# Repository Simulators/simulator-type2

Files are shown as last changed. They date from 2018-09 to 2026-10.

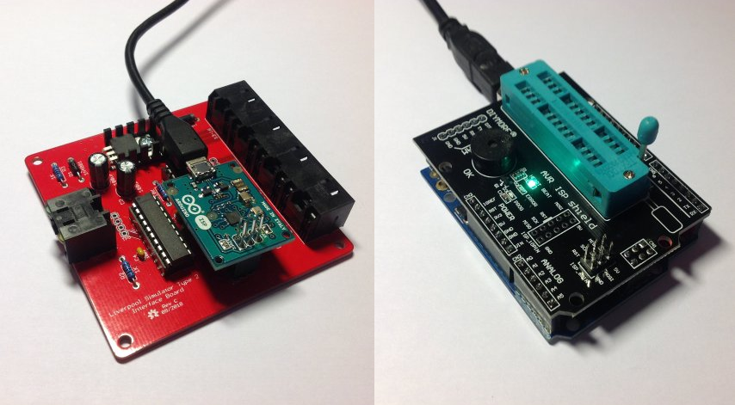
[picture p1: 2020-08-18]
docs/source/Images/Hardware/Interface/programmers.png

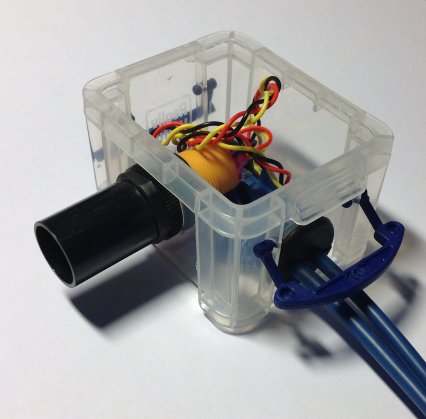
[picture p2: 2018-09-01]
docs/source/Images/Hardware/Enclosures/Img_0459.jpg

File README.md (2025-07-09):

# The Type 2 Liverpool Ringing Simulator

In this repository you will find all the resources for building the Liverpool Ringing Simulator Project's Type 2 simulator interfaces and sensor heads, including:
* Hardware & Software Manuals
* Firmware Source Code
* KiCad PCB Designs
* PCB Fabrication Gerber Files

You probably want to start in the docs folder above...

Please note that this is a Build-it-Yourself project. No pre-built hardware is available.

The original (Type 1) Liverpool Simulator hardware and code can be found in the legacy repository at https://github.com/Simulators/simulator. The Type 1 simulator is no longer under active development.

If you didn't get here from https://www.simulators.org.uk/, you might want to go and look at that, too.

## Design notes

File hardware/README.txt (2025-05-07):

*** If you just want to order PCBs from a fabrication house, ready-made Gerber files can be found in the Gerbers directory ***

If you require PCB CAD files, please use those in the "kicad" subdirectory. The CAD files in the "eagle" subdirectory are the last to be produced using Eagle prior to migration of PCB development to KiCad. Those are provided for reference only, and are no longer maintained.

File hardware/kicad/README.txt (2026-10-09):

HOW TO USE THE KICAD CAD FILES
==============================

*** If you just want to order PCBs from a fabrication house, you don't need THESE files ***
Ready-made Gerber files can be found in the Gerbers directory.

A working knowledge of KiCad is assumed.

The version of KiCad currently used for Liverpool Ringing Simulator Project PCB development is 10.0.x. Some KiCad projects were developed with KiCad 9.0.x, and may require updates if opened in KiCad 10.0.x. 

Libraries
=========

As far as possible, the PCB designs use symbols and footprints from the stock libraries supplied with KiCad. Where no suitable symbol or footprint exists in the stock libraries, additional symbols and footprints are provided by custom libraries in this repository.

Unpack the libraries zipfile into a convenient location, wherever you keep your custom KiCad libraries, and start KiCad 10.x. Note that some libraries now require KiCad 10.0x.

From the project browser window, use the "Preferences | Manage Symbol Libraries..." menu option to register the symbol library file "LRSP_Simulator.kicad_sym" as a Global symbol library with the nickname "LRSP_Simulator".

From the project browser window, use the "Preferences | Manage Footprint Libraries..." menu option to register the footprint library directory "LRSP_Simulator.pretty" as a Global footprint library with the nickname "LRSP_Simulator".

The footprint library uses the KiCad 9.x (and later) embedded file functionality to embed 3D models into the library. There is no need for a separate 3D models collection.

PCB Projects
============

Each PCB zipfile is a compressed KiCad project, created with the "File | Archive Project..." menu option from the KiCad project browser.

Download the zipfile for the PCB(s) you want to work on, and create an empty directory to hold each PCB project.

Use the "File | Unarchive Project..." menu option from the KiCad project browser window to unpack each zipfile into the appropriate directory, then use "File | Open Project..." to load the PCB project.

Gerber & Drill File Creation
============================

The Liverpool Ringing Simulator Project creates Gerbers and drill files using the "Fabrication Toolkit" plugin, which creates a compressed zipfile containing files formatted ready for fabrication by JLCPCB. These Gerbers should be suitable for use by other PCB fabrication houses.

Install this plugin into KiCad using the Plugin and Content Manager (PCM) from the KiCad project browser window, and run it from the icon is places in the PCB Editor toolbar. The output zipfile is placed in the sub-directory "production".

Panelisation
============

The Liverpool Ringing Simulator Project panelises small PCBs using the "KiKit" plugin. Ready-made panelised Gerber files are provided in the Gerbers directory.

KiKit has a two phase installation process. Install the plugin frontend into KiCad using the Plugin and Content Manager (PCM) from the KiCad main window, and the Python backend from the KiCad Comand Prompt window - refer to the KiKit documentation for details.

KiKit panelisation parameter files are provided in the PCB project zipfiles. The small sensor boards use the "KiKit_Panel_6.json" parameter file to create a 2 x 3 panel of 6 boards. The Power and 2nd PC boards use the "KiKit_Panel_4.json" parameter file to create a 2 x 2 panel of 4 boards.

Note that KiKit panelisation is intended to be run from the Standalone PCB Editor, not from within a project.

LRSP
20261009

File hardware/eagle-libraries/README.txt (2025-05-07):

*** DEPRECATED ***

These library files are the last to be produced using Eagle prior to migration of PCB development to KiCad. These are provided for reference only, and are no longer maintained.

Please use the KiCad CAD files where possible.

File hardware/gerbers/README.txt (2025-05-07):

Please use the KiCad-generated Gerbers in the "kicad" directory where possible.

The Gerbers in the "eagle" subdirectory are the last to be produced using Eagle prior to migration of PCB development to KiCad. Those are provided for reference only, and are no longer maintained.

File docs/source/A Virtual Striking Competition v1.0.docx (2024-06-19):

The Liverpool Ringing Simulator

A Virtual Striking Competition

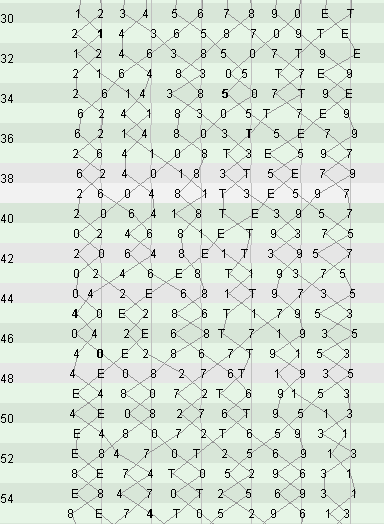
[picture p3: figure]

Author: Andrew Instone-Cowie

Date: 19 June 2024

Version: 1.0

# Index of Figures

# Document History

Version | Author | Date | Changes
0.1 | A J Instone-Cowie | 04/01/2020 | First Draft.
1.0 | A J Instone-Cowie | 19/06/2024 | Update external links.

Copyright ©2020-24 Andrew Instone-Cowie.

Cover image: CAS Visual Representation of Striking.

# Licence

This work is licensed under a Creative Commons Attribution-ShareAlike 4.0 International License.[^1]

Unless otherwise separately undertaken by the Licensor, to the extent possible, the Licensor offers the Licensed Material as-is and as-available, and makes no representations or warranties of any kind concerning the Licensed Material, whether express, implied, statutory, or other. This includes, without limitation, warranties of title, merchantability, fitness for a particular purpose, non-infringement, absence of latent or other defects, accuracy, or the presence or absence of errors, whether or not known or discoverable. Where disclaimers of warranties are not allowed in full or in part, this disclaimer may not apply to You.

To the extent possible, in no event will the Licensor be liable to You on any legal theory (including, without limitation, negligence) or otherwise for any direct, special, indirect, incidental, consequential, punitive, exemplary, or other losses, costs, expenses, or damages arising out of this Public License or use of the Licensed Material, even if the Licensor has been advised of the possibility of such losses, costs, expenses, or damages. Where a limitation of liability is not allowed in full or in part, this limitation may not apply to You.

# Background

## Polling Design

Both the Type 1 and Type 2 variants of the Liverpool Ringing Simulator use a polling approach to detecting sensor inputs. This is discussed in detail in the Type 2 Technical Reference Guide, but in summary, after completing initialization, the firmware code cycles round all the active inputs, examining the state of each sensor in turn. After all inputs have been read, the code loops round and the process starts again.

In the Type 2 Simulator Interface Module each iteration of the main polling loop takes approximately 400µs when configured to poll all 16 possible sensors. Put another way, the inputs are polled at approximately 2.5kHz.

## The Variable Odd-Struckness Problem

This use of a polling architecture invariably introduces a degree of variable odd-struckness.

- If a pulse from any Sensor Module starts a fraction of a second before the polling loop examines the associated input, the pulse will be detected almost immediately.
- If the pulse starts a fraction of a second after the polling loop examines the associated input, the pulse will not be detected until the next iteration of the polling loop, potentially as much as 400µs later.
- There is no fixed correlation between the start time of a pulse and the current position of the polling loop in its cycle, and therefore each pulse is subject to an effectively random delay of between zero and 400µs (the duration of the polling loop).
- The mean delay would be 200µs (half the polling interval), so if this was detectable then it would result in each simulated bell apparently striking randomly early or late by between zero and 200µs.

The following diagram taken from Type 2 Technical Reference Guide illustrates this problem:

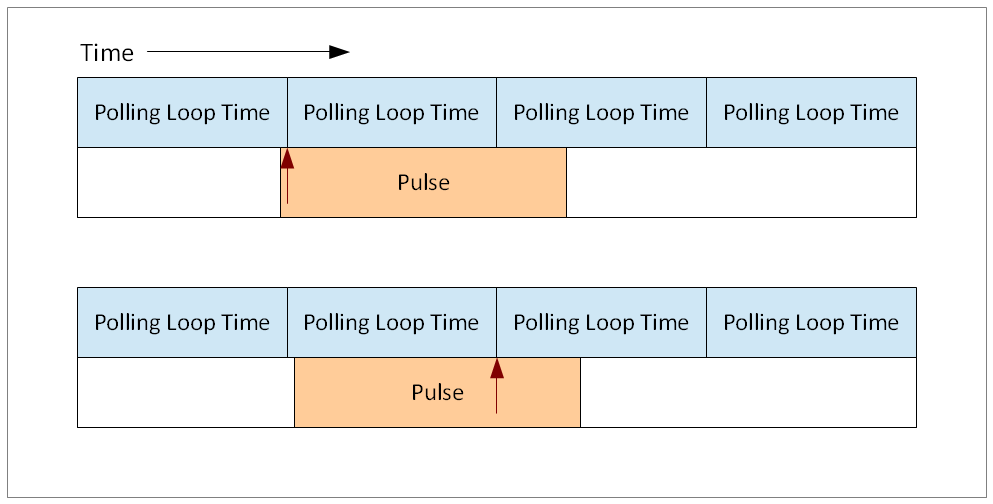
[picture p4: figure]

Figure 1 – Variable Odd-Struckness Illustration

The upper red arrow indicates the polling loop examining an input just after the start of an incoming sensor pulse. The delay due to polling is effectively zero.

In the lower diagram, the polling loop examines the input pin just before the start of an incoming sensor pulse, and hence does not detect the pulse until the next iteration of the loop, indicated by the lower red arrow. The delay due to polling is effectively equal to the polling loop interval.

The design of the simulator assumes that this variable odd-struckness is too small to be significant and is in practice not detectable.

The first question this paper seeks to consider is: Is this assumption reasonable?

## Virtual Striking Competition

The usual ringing approach to quantifying errors in striking is to conduct a striking competition!

A “virtual striking competition” was conducted to validate the reasonableness of this assumption. This exercise pre-dated the development of the Type 2 Simulator, so was undertaken with a Type 1 Simulator Interface driving Abel[^2] running on a PC, however both hardware variants use the same underlying approach.

The competition was conducted as follows:

- The “test piece” consisted of 10 minutes of rounds on 12, with an inter-bell interval of approximately 200ms and an open handstroke lead of 1.0. This results in approximately 240 rows at a peal speed of 3h 30m.
- The Abel striking statistics were reset prior to each test, the striking for each test piece was recorded, and then exported from Abel in “Lowndes” text format[^3].
- Each Lowndes file was then imported into the CAS[^4] tool for analysis. CAS (Computer Analysis of Striking) is used in conjunction with the Hawkear[^5] system as part of the judging process for the National 12-Bell Striking Competition[^6].
- The individual results for each test piece were recorded, and all test pieces were then ranked using the CAS Band Summary tool.
- Three different scenarios were tested, and these are detailed below.
- Note that data relating to two further scenarios has been removed for clarity; this related to other experimental hardware and is not relevant to this discussion.

# Virtual Competition Scenarios

## Test Scenario A

Test Scenario A was a control scenario, using Abel alone with no simulator hardware.

- Abel was setup to ring rounds on 12 at the required speed, the statistics cleared, and the ringing started.
- No external simulator hardware was used in this test.
- In this test, as in all tests, the Simulator PC was left as undisturbed as possible during ringing.

Scenario A is illustrated in the following diagram:

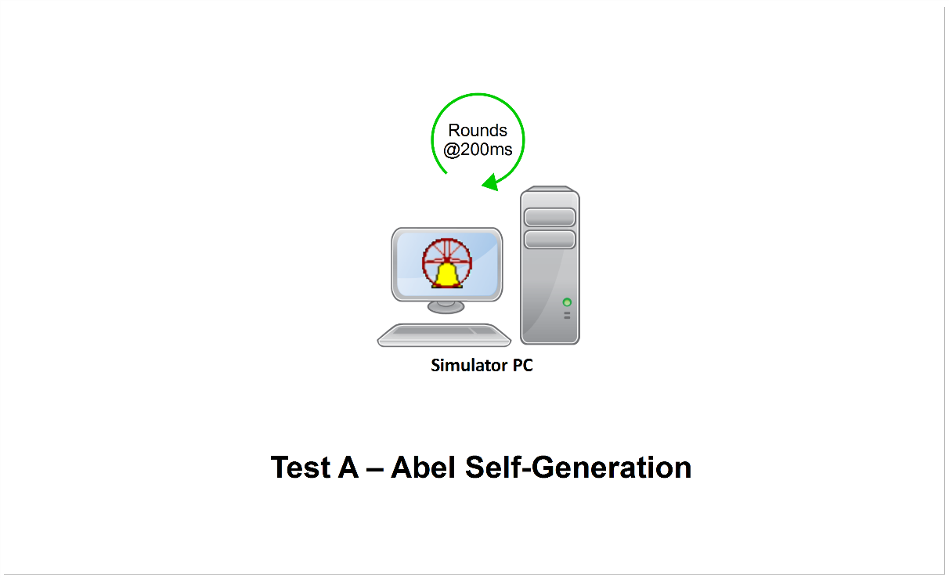
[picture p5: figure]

Figure 2 – Test Scenario A

The CAS analysis of the striking from Test Scenario A is shown in the following table. The single fault is most likely the result of some background processing on the PC.

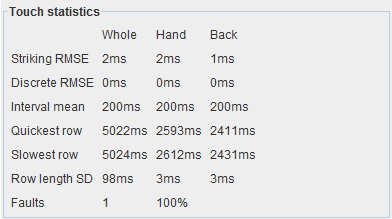
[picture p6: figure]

Figure 3 – Scenario A Test Results

## Test Scenario B

Test Scenario B was also a control and tested the accuracy of serial input detection in Abel.

- Abel was driven by a Simulator Interface operating with custom test code.
- The Interface was setup to ring rounds on 12 at the required speed, all non-essential code being eliminated. The Abel statistics were cleared, and the ringing started.
- No simulator sensor inputs were read in this test, and hence this test should not be susceptible to the variable odd-struckness problem.

Scenario B is illustrated in the following diagram:

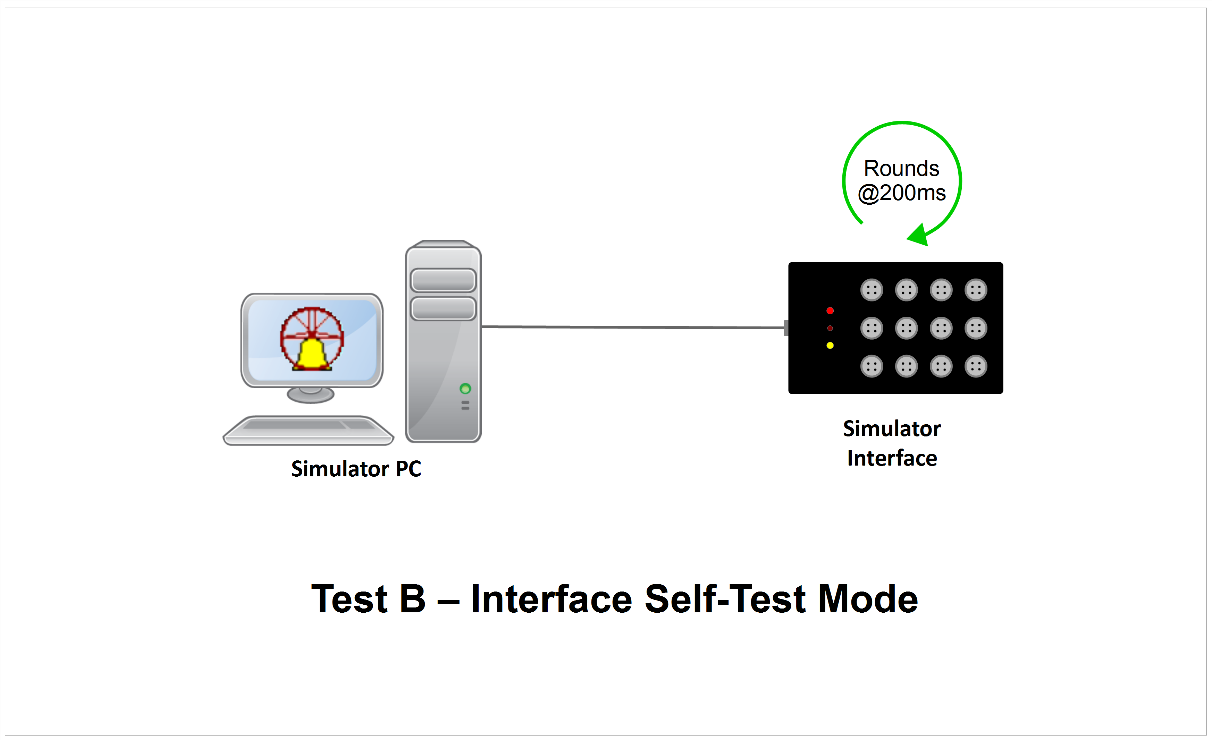
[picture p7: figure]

Figure 4 – Test Scenario B

The CAS analysis of the striking from Test Scenario B is shown in the following table.

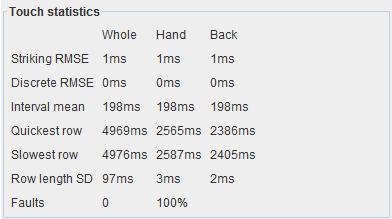
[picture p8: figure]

Figure 5 – Scenario B Test Results

## Test Scenario C

Test Scenario C introduced susceptibility to the variable odd-struckness problem.

- Abel was driven by a Simulator Interface operating with standard code. The Interface sensor inputs were driven by an Arduino setup as a pulse generator, to ring rounds on 12 at the required speed. The Abel statistics were cleared, and the pulse generator started.
- 12 simulator sensor inputs were polled in this test, and hence the test should be susceptible to the variable odd-struckness problem.
- This was the most live-like of the main test scenarios, including all interface code and polling variability.

Scenario C is illustrated in the following diagram:

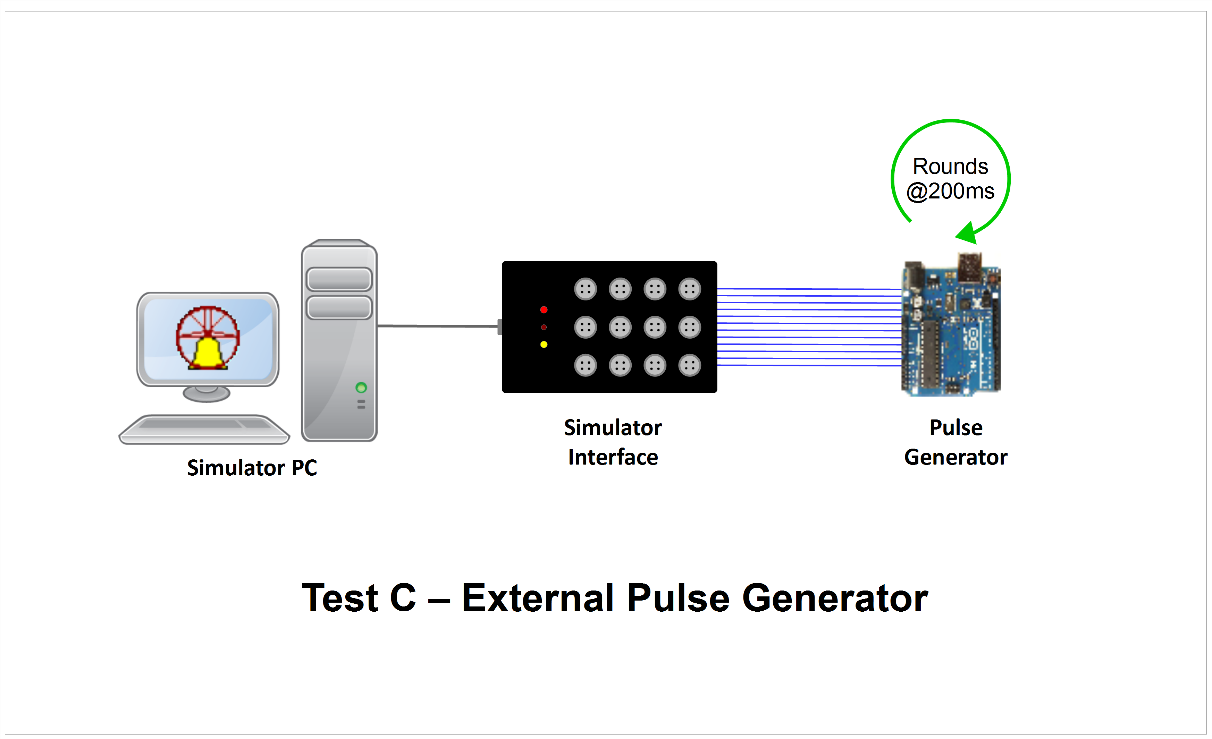
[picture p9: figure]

Figure 6 – Test Scenario C

The CAS analysis of the striking from Test Scenario C is shown in the following table. The virtual ringing is still very good, and no faults are recorded.

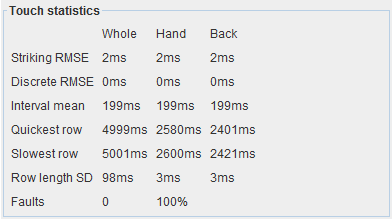
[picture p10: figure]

Figure 7 – Scenario C Test Results

## Interim Results

The CAS Band Summary results for all three scenarios are shown in the following table:

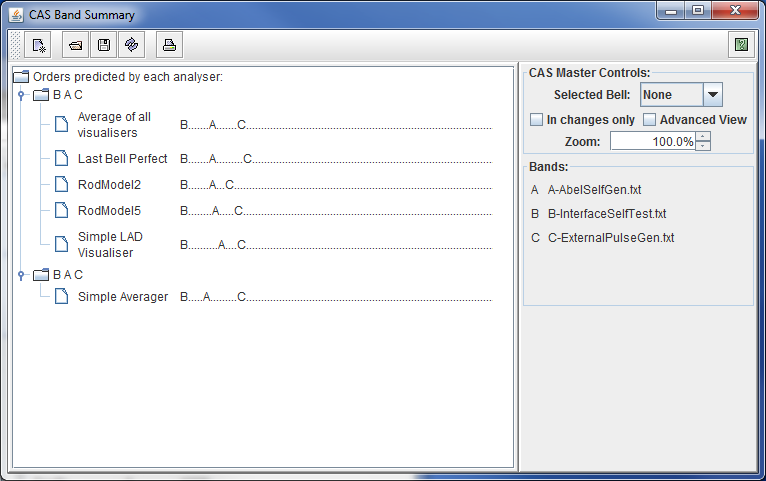
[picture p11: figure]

Figure 8 – Interim CAS Results

The detailed results above for each test scenario show that the striking achieved by the simulator is very good.

- Slightly surprisingly, the most accurate striking was achieved using the serial input (Scenario B) and not from Abel self-generating ringing (Scenario A). However, the difference between the two scenarios is extremely small.
- As expected, a very slight reduction in striking accuracy is introduced by polling Simulator Interface inputs (Scenario C versus Scenario B). The difference is again extremely small, and the striking still achieves a “perfect” 100% accuracy with no faults.
- Scenarios D and E have been removed, as noted above.

The assumption that any variable odd-struckness introduced by polling inputs is too small to be significant does therefore seem to be reasonable.

A more interesting question might be: How does the simulator striking compare to the best that humans can achieve?

# Real World Striking Comparison

To consider the second question, the results of the virtual striking competition were compared with the actual striking data from the bands placed first, fifth and ninth (i.e. last) in the 2010 National 12-Bell Striking Competition held at Crediton. This striking data is used for testing by the CAS developer[^7].

This comparison does not pretend to be a detail statistical analysis and should be treated with a degree of caution, but it does provide a rough indication of the relative magnitudes of the errors introduced by the simulator, and of the errors naturally incurred by highly experienced real ringers ringing under competition conditions.

The speed of competition ringing and the overall number of changes rung are broadly comparable with the simulator test scenarios above[^8].

## Scenario F – Crediton 2010 First Placed Band

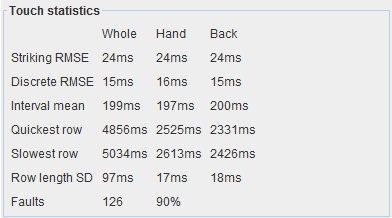
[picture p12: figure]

Figure 9 – Crediton 1st Placed Band

## Scenario G – Crediton 2010 Fifth Placed Band

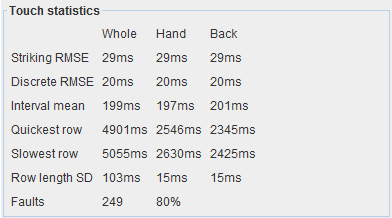
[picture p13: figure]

Figure 10 – Crediton 5th Placed Band

## Scenario H – Crediton 2010 Ninth Placed Band

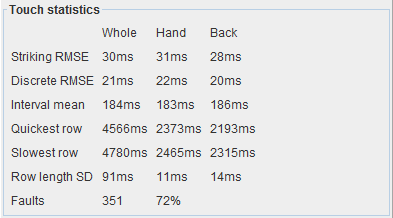
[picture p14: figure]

Figure 11 – Crediton 9th Placed Band

## Overall Result

The CAS summary results for all virtual and competition scenarios are shown in the following table:

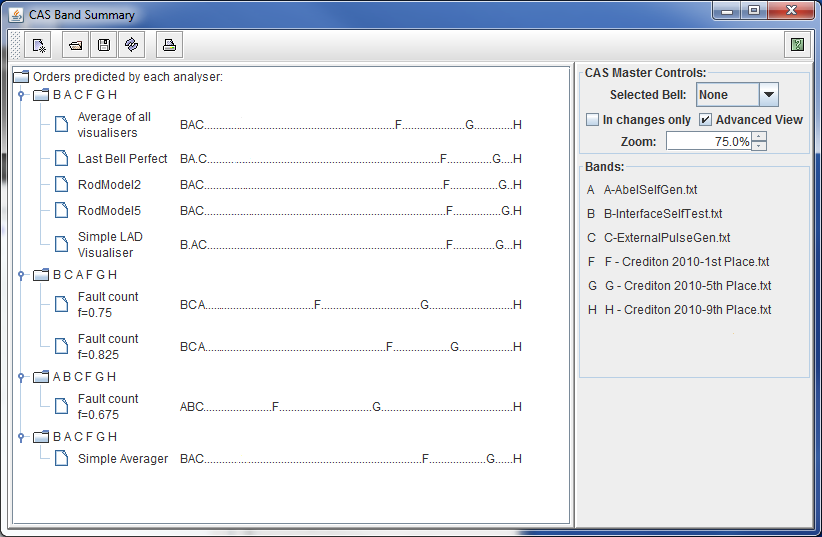
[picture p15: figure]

Figure 12 – Overall CAS Results

As might be expected, all the simulator results are bunched up at the left side of the analysis, showing that the errors introduced by the simulator are very much smaller than the errors naturally incurred by the human ringers.

Overall, the assumption that variable odd-struckness introduced by polling simulator inputs is too small to be significant does appear to be justified.

# Acknowledgements

CAS is developed and released under the GPL by Mark B Davies.

Abel is developed by Chris Hughes and Simon Feather, and is copyright © 2019 AbelSim Ltd.

[^1] https://creativecommons.org/licenses/by-sa/4.0/
[^2] https://www.abelsim.co.uk
[^3] https://www.abelsim.co.uk/doc/striking.htm
[^4] https://www.12bell.org.uk/downloads/cas1.4.zip, released under GNU General Public Licence v3.
[^5] https://www.12bell.org.uk/hawkear/
[^6] https://www.12bell.org.uk
[^7] https://github.com/EmBeeDee/CAS
[^8] https://www.12bell.org.uk/cgi-bin/results.cgi?year=2010&venue=crediton. Note that the judges’ final scores are not derived solely from CAS.

Liverpool Ringing Simulator – A Virtual Striking Competition 1.0

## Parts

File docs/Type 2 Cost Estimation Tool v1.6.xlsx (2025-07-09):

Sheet: Simulator Cost Estimation
Liverpool Simulator (Type 2) Cost Estimation Tool
v1.6, 07/08/2024 | For Interface Rev F, Power Board Rev E, Magnetic Sensor Rev E, Generic Sensor Rev D
This spreadsheet gives an ESTIMATE of the components costs for the Type 2 Liverpool Simulator Hardware.
Please read the notes at the bottom of the sheet, then set the numbers of interfaces and sensors in the red boxes.
Number of Interface/Power Boards | 1 | Adjust the quantities in the red bordered cells to suit the requirements of your installation.
Number of Magneto-Resistive (2SS52M) Sensors | 8
Number of Hall Effect (A1120EUA-T) Sensors | 0
Number of Infra-Red/Generic Sensors | 0
Item | Supplier | Part Code | Quantities Required |  |  |  |  | Pricing |  |  |  | # Multiples | Cost inc VAT
 |  |  | Base | MR Sensor | HE Sensor | IR Sensor | # Total | Price | Per | Multiple | VAT
100Ω 0.25W Metal Film Resistor | Farnell | 9341099 | 0 | 1 | 1 | 1 | 8 | £0.057 | 1 | 10 | 1.20 | 1 | £0.69
1kΩ 0.25W Metal Film Resistor | Farnell | 9341102 | 2 | 1 | 1 | 1 | 10 | £0.059 | 1 | 10 | 1.20 | 1 | £0.70
10kΩ 0.25W Metal Film Resistor | Farnell | 9341110 | 1 | 1 | 1 | 1 | 9 | £0.058 | 1 | 10 | 1.20 | 1 | £0.69
100µF 25V Electrolytic Capacitor (6.3mm Radial) | Farnell | 9451188 | 2 | 0 | 0 | 0 | 2 | £0.110 | 1 | 1 | 1.20 | 2 | £0.26
100nF (0.1µF) 50V MLCC Capacitor (2.54mm Radial) | Farnell | 1457655 | 4 | 1 | 1 | 1 | 12 | £0.095 | 1 | 10 | 1.20 | 2 | £2.27
1N4001 Diode | Farnell | 1458986 | 1 | 0 | 0 | 0 | 1 | £0.254 | 1 | 5 | 1.20 | 1 | £1.52
SA5.0A TVS Diode | Farnell | 1886342 | 1 | 2 | 2 | 2 | 17 | £0.346 | 1 | 5 | 1.20 | 4 | £8.30
SA12A TVS Diode | Farnell | 2679618 | 1 | 0 | 0 | 0 | 1 | £0.249 | 1 | 5 | 1.20 | 1 | £1.49
SA15CA TVS Diode | Farnell | 2762809 | 3 | 0 | 0 | 0 | 3 | £0.346 | 1 | 1 | 1.20 | 3 | £1.25
MC7805CTG 5V Voltage Regulator | Farnell | 9666095 | 1 | 0 | 0 | 0 | 1 | £0.612 | 1 | 1 | 1.20 | 1 | £0.73 | Part Change 26/06/2024
MAX233EPP+G36 Serial Line Driver | Farnell | 2519158 | 1 | 0 | 0 | 0 | 1 | £10.140 | 1 | 1 | 1.20 | 1 | £12.17
Blue 3mm LED | Farnell | 1863182 | 0 | 1 | 1 | 0 | 8 | £0.737 | 1 | 1 | 1.20 | 8 | £7.08
Yellow 3mm LED | Farnell | 2112098 | 0 | 0 | 0 | 1 | 0 | £0.222 | 1 | 5 | 1.20 | 0 | £0.00
Honeywell 2SS52M Magneto-Resistive Sensor | RS | 368-3945 | 0 | 1 | 0 | 0 | 8 | £7.400 | 1 | 1 | 1.20 | 8 | £71.04 | No longer stocked by Farnell, was part 3111519
Allegro Microsystems A1120 Hall Effect Sensor | Farnell | 1791402 | 0 | 0 | 1 | 0 | 0 | £0.830 | 1 | 1 | 1.20 | 0 | £0.00
ATmega328P-PU Microcontroller | Farnell | 1715487 | 1 | 0 | 0 | 0 | 1 | £2.320 | 1 | 1 | 1.20 | 1 | £2.78
Amphenol RJHSE-5084 RJ45 Connector | Farnell | 1860578 | 1 | 0 | 0 | 0 | 1 | £1.230 | 1 | 1 | 1.20 | 1 | £1.48
Amphenol RJHSE-5080-04 RJ45 Connector | Farnell | 2709010 | 1 | 0 | 0 | 0 | 1 | £2.030 | 1 | 1 | 1.20 | 1 | £2.44
Amphenol RJHSE-5080 RJ45 Connector | Farnell | 1860577 | 1 | 0 | 0 | 0 | 1 | £0.926 | 1 | 1 | 1.20 | 1 | £1.11
Amp TE Connectivity 5406526-1 RJ45 Connector | Farnell | 2452587 | 0 | 1 | 1 | 1 | 8 | £2.540 | 1 | 1 | 1.20 | 8 | £24.38
Right Angle PCB D Sub Connector 9 Pin | Farnell | 1848372 | 1 | 0 | 0 | 0 | 1 | £0.673 | 1 | 5 | 1.20 | 1 | £4.04
DC Power Connector 5mm PCB Mount | Farnell | 1854512 | 1 | 0 | 0 | 0 | 1 | £2.450 | 1 | 1 | 1.20 | 1 | £2.94
Header Pins 40-way Strip | Farnell | 1462888 | 0 | 0 | 0 | 3 | 0 | £1.500 | 40 | 40 | 1.20 | 0 | £0.00
ICSP Header 2x3 Pin | Farnell | 1593440 | 1 | 0 | 0 | 0 | 1 | £0.053 | 1 | 1 | 1.20 | 1 | £0.06 | Part Change 26/06/2024
20-pin, 0.3” pitch IC Socket | Farnell | 4285608 | 1 | 0 | 0 | 0 | 1 | £0.163 | 1 | 10 | 1.20 | 1 | £1.96 | Part Change 26/06/2024
28-pin, 0.3” pitch IC Socket | Farnell | 2445626 | 1 | 0 | 0 | 0 | 1 | £0.444 | 1 | 10 | 1.20 | 1 | £5.33
Murata CSTLS8M00G53-A0 Ceramic Resonator | Farnell | 2443273 | 1 | 0 | 0 | 0 | 1 | £0.135 | 1 | 5 | 1.20 | 1 | £0.81
TO-220 Heatsink (Optional) | Farnell | 1703172 | 1 | 0 | 0 | 0 | 1 | £2.770 | 1 | 1 | 1.20 | 1 | £3.32
20mm PCB Mount Fuse Holder | Farnell | 2461158 | 1 | 0 | 0 | 0 | 1 | £0.480 | 1 | 5 | 1.20 | 1 | £2.88
20mm 800mA Quick Blow Fuse | Farnell | 2461215 | 1 | 0 | 0 | 0 | 1 | £0.160 | 1 | 1 | 1.20 | 1 | £0.19
SW4177-1500 AC/DC Power Supply | Farnell | 2802689 | 1 | 0 | 0 | 0 | 1 | £23.580 | 1 | 1 | 1.20 | 1 | £28.30
Really Useful Box 0.75 Litre | Really Useful | NA | 2 | 0 | 0 | 0 | 2 | £2.540 | 1 | 1 | 1.00 | 2 | £5.08
Really Useful Box 0.14 Litre | Really Useful | NA | 0 | 0 | 0 | 1 | 0 | £0.690 | 1 | 1 | 1.00 | 0 | £0.00
Really Useful Box 0.07 Litre | Really Useful | NA | 0 | 1 | 1 | 0 | 8 | £0.670 | 1 | 1 | 1.00 | 8 | £5.36
20mm Closed Grommets | Screwfix | 884VT | 6 | 1 | 1 | 1 | 14 | £3.290 | 100 | 100 | 1.00 | 1 | £3.29 | Part Change 26/06/2024
N52 grade, 20mm x 10mm Neodymium | MagnetExpert | F646-N52-1 | 0 | 1 | 1 | 0 | 8 | £5.680 | 1 | 1 | 1.20 | 8 | £54.53 | Supplier Change
Infra-Red Obstacle Sensor | HobbyComponents | E18-D80NK | 0 | 0 | 0 | 1 | 0 | £4.990 | 1 | 1 | 1.00 | 0 | £0.00 | Supplier Change
RJ45 Power/Data Cable (25m assumed) | CPC | CS24970 | 1 | 0 | 0 | 0 | 1 | £10.120 | 1 | 1 | 1.20 | 1 | £12.14
RJ45 Sensor Cable (5m assumed) | CPC | CS17415 | 0 | 1 | 1 | 1 | 8 | £2.280 | 1 | 1 | 1.20 | 8 | £21.89
USB-Serial Adapter Cable | eBay | NA | 1 | 0 | 0 | 0 | 1 | £13.850 | 1 | 1 | 1.00 | 1 | £13.85
Interface Board PCB | JLCPCB | NA | - | - | - | - | 1 | £1.580 | 5 | 5 | 1.00 | 1 | £1.58
Power Board PCB | JLCPCB | NA | - | - | - | - | 8 | £6.160 | 20 | 20 | 1.00 | 1 | £6.16 | Panelisation fee applies
Magnetic Sensor PCB - for 2SS52M or A1120EUA-T | JLCPCB | NA | - | - | - | - | 8 | £6.080 | 30 | 30 | 1.00 | 1 | £6.08 | Panelisation fee applies
Generic/Optical Sensor PCB | JLCPCB | NA | - | - | - | - | 0 | £6.080 | 30 | 30 | 1.00 | 0 | £0.00 | Panelisation fee applies
Estimated Total Cost |  |  |  |  |  |  |  |  |  |  |  |  | £320.17
Notes
JLCPCB PCB Costs exclude carriage, estimated at £12 per order.
Farnell carriage is free for orders >£40 ex VAT, £9.99 for smaller orders. Many eBay items have free postage.
Other carriage costs not included.
Farnell, CPC, Really Useful and Screwfix prices correct at 26/06/2024.
eBay costs for typical items with active listings on 26/06/2024.
In addition to these components, you will need a PC, simulator software of your choice, and mounting hardware for the sensors.
The VAT column indicates where VAT needed to be added to a price quoted exclusive of VAT.
The Honeywell 2SS52M is no longer stocked by Farnell, part code and price are from RS.

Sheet: Multi-PC Cost Estimation
Multi-PC Hardware (Type 2) Cost Estimation Tool
v1.6, 26/06/2024 | For Second PC Board Rev C, Basic Serial Splitter/Expander Rev D
This spreadsheet gives an ESTIMATE of the components costs for the Type 2 Liverpool Simulator Multi-PC Hardware.
Please read the notes at the bottom of the sheet, then set the numbers of modules in the red boxes.
Number of Second PC Boards | 0 | Adjust the quantities in the red bordered cells to suit the requirements of your installation.
Number of Basic Serial Splitter Master Boards | 1
Number of Basic Serial Splitter Expander Boards | 0
Item | Supplier | Part Code | Quantities Required |  |  |  | Pricing |  |  |  | # Multiples | Cost inc VAT
 |  |  | Second PC | Master | Expander | # Total | Price | Per | Multiple | VAT
1kΩ 0.25W Metal Film Resistor | Farnell | 9341102 | 0 | 1 | 0 | 1 | £0.059 | 1 | 10 | 1.20 | 1 | £0.70
100µF 25V Electrolytic Capacitor (6.3mm Radial) | Farnell | 9451188 | 0 | 2 | 0 | 2 | £0.110 | 1 | 1 | 1.20 | 2 | £0.26
330nF (0.33µF) 50V MLCC Capacitor (6.3mm Radial) | Farnell | 2819679 | 0 | 3 | 0 | 3 | £1.500 | 1 | 1 | 1.20 | 3 | £5.40
47nF (0.047µF) 50V MLCC Capacitor (2.54mm Radial) | Farnell | 2819680 | 0 | 1 | 0 | 1 | £0.308 | 1 | 1 | 1.20 | 1 | £0.37
100nF (0.1µF) 50V MLCC Capacitor (2.54mm Radial) | Farnell | 1457655 | 0 | 6 | 5 | 6 | £0.095 | 1 | 10 | 1.20 | 1 | £1.13
1N4001 Diode | Farnell | 1458986 | 0 | 1 | 0 | 1 | £0.254 | 1 | 5 | 1.20 | 1 | £1.52
SA5.0A TVS Diode | Farnell | 1886342 | 0 | 1 | 0 | 1 | £0.346 | 1 | 5 | 1.20 | 1 | £2.08
SA12A TVS Diode | Farnell | 2679618 | 1 | 1 | 0 | 1 | £0.249 | 1 | 5 | 1.20 | 1 | £1.49
SA15CA TVS Diode | Farnell | 2762809 | 3 | 3 | 0 | 3 | £0.346 | 1 | 1 | 1.20 | 3 | £1.25
MC7805CTG 5V Voltage Regulator | Farnell | 9666095 | 0 | 1 | 0 | 1 | £0.612 | 1 | 1 | 1.20 | 1 | £0.73
MAX3323EEPE+ Serial Line Driver | Farnell | 2511866 | 0 | 1 | 0 | 1 | £10.890 | 1 | 1 | 1.20 | 1 | £13.07
MAX208CNG+ Serial Line Driver | Farnell | 2511906 | 0 | 1 | 1 | 1 | £8.840 | 1 | 1 | 1.20 | 1 | £10.61
Green 3mm LED | Farnell | 1581114 | 0 | 1 | 0 | 1 | £0.078 | 1 | 5 | 1.20 | 1 | £0.47
DIP Switch 8-Way SPST | Farnell | 9472185 | 0 | 1 | 0 | 1 | £1.110 | 1 | 1 | 1.20 | 1 | £1.33
Amp TE Connectivity 5406526-1 RJ45 Connector | Farnell | 2452587 | 1 | 1 | 0 | 1 | £2.540 | 1 | 1 | 1.20 | 1 | £3.05
Right Angle PCB D Sub Connector 9 Pin | Farnell | 1848372 | 1 | 4 | 4 | 4 | £0.673 | 1 | 5 | 1.20 | 1 | £4.04
16-pin, 0.3” pitch IC Socket | Farnell | 2445622 | 0 | 1 | 0 | 1 | £0.235 | 1 | 10 | 1.20 | 1 | £2.82 | Part Change
24-pin, 0.3” pitch IC Socket | Farnell | 2672303 | 0 | 1 | 1 | 1 | £0.750 | 1 | 1 | 1.20 | 1 | £0.90 | Part Change
8-Way Right Angle Header | Farnell | 2356196 | 0 | 0 | 1 | 0 | £0.587 | 1 | 10 | 1.20 | 0 | £0.00
8-Way Right Angle Socket | Farnell | 1668343 | 0 | 0 | 1 | 0 | £2.330 | 1 | 1 | 1.20 | 0 | £0.00
Really Useful Box 0.75 Litre | Really Useful | NA | 1 | 0 | 0 | 0 | £2.540 | 1 | 1 | 1.00 | 0 | £0.00
Really Useful Box 0.55 Litre | Really Useful | NA | 0 | 1 | 0 | 1 | £2.610 | 1 | 1 | 1.00 | 1 | £2.61
20mm Closed Grommets | Screwfix | 884VT | 1 | 1 | 0 | 1 | £3.290 | 100 | 100 | 1.00 | 1 | £3.29
Basic Serial Splitter Board PCB | JLCPCB | NA | - | - | - | 1 | £1.580 | 5 | 5 | 1.00 | 1 | £1.58
Second PC Board PCB | JLCPCB | NA | - | - | - | 0 | £6.160 | 20 | 20 | 1.00 | 0 | £0.00 | Panel fee applies
Estimated Total Cost |  |  |  |  |  |  |  |  |  |  |  | £58.71
Notes
The VAT column indicates where VAT needed to be added to a price quoted exclusive of VAT.
JLCPCB PCB Costs exclude carriage, estimated at £12 per order.
Farnell carriage is free for orders >£40 ex VAT, £9.99 for smaller orders. Many eBay items have free postage.
Other carriage costs not included.
Farnell, CPC, Really Useful and Screwfix prices correct at 26/06/2024.
The VAT column indicates where VAT needed to be added to a price quoted exclusive of VAT.

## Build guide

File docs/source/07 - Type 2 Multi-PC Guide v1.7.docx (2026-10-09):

Type 2 Liverpool Ringing Simulator

07 – Multi-PC Guide

Author: Andrew Instone-Cowie

Date: 09 October 2026

Version: 1.7

# Index of Figures

# Index of Tables

# Document History

Version | Author | Date | Changes
1.0 | A J Instone-Cowie | 01/10/2019 | First Release.
1.1 | A J Instone-Cowie | 18/08/2020 | Minor update.
1.2 | A J Instone-Cowie | 27/08/2021 | Alternative DB9 enclosure drilling option, DB9 part.
1.3 | A J Instone-Cowie | 19/06/2024 | Update external links.
1.4 | A J Instone-Cowie | 26/06/2024 | Updated Farnell/Screwfix part numbers.
1.5 | A J Instone-Cowie | 28/08/2024 | Improve diagrams following feedback, add module configurations table.
1.6 | A J Instone-Cowie | 07/05/2025 | Eagle to KiCad PCB design tool migration. Updated schematics and board layouts.
1.7 | A J Instone-Cowie | 09/10/2026 | Updated Basic Serial Splitter schematics.

Copyright ©2019-26 Andrew Instone-Cowie.

Cover photograph: A completed Type 2 Basic Serial Splitter PCB.

PC ports vector graphic design by https://www.vecteezy.com
(Vecteezy Standard Licence, Free for personal and commercial use with attribution.)

# Licence

This work is licensed under a Creative Commons Attribution-ShareAlike 4.0 International License.[^1]

Unless otherwise separately undertaken by the Licensor, to the extent possible, the Licensor offers the Licensed Material as-is and as-available, and makes no representations or warranties of any kind concerning the Licensed Material, whether express, implied, statutory, or other. This includes, without limitation, warranties of title, merchantability, fitness for a particular purpose, non-infringement, absence of latent or other defects, accuracy, or the presence or absence of errors, whether or not known or discoverable. Where disclaimers of warranties are not allowed in full or in part, this disclaimer may not apply to You.

To the extent possible, in no event will the Licensor be liable to You on any legal theory (including, without limitation, negligence) or otherwise for any direct, special, indirect, incidental, consequential, punitive, exemplary, or other losses, costs, expenses, or damages arising out of this Public License or use of the Licensed Material, even if the Licensor has been advised of the possibility of such losses, costs, expenses, or damages. Where a limitation of liability is not allowed in full or in part, this limitation may not apply to You.

# Attribution

The Creative Commons Attribution-ShareAlike (CC BY-SA) licence permits you to re-use this material for any purpose you wish, subject to the conditions of the licence, including providing attribution of the source.

The following is suggested as a suitable form of attribution for this document, or extracts thereof:

Type 2 Multi-PC Guide, Liverpool Ringing Simulator Project (https://www.simulators.org.uk). This document is licensed under the CC BY-SA 4.0 licence (https://creativecommons.org/licenses/by-sa/4.0/). © 2019-2026 Andrew J Instone-Cowie.

# Documentation Map

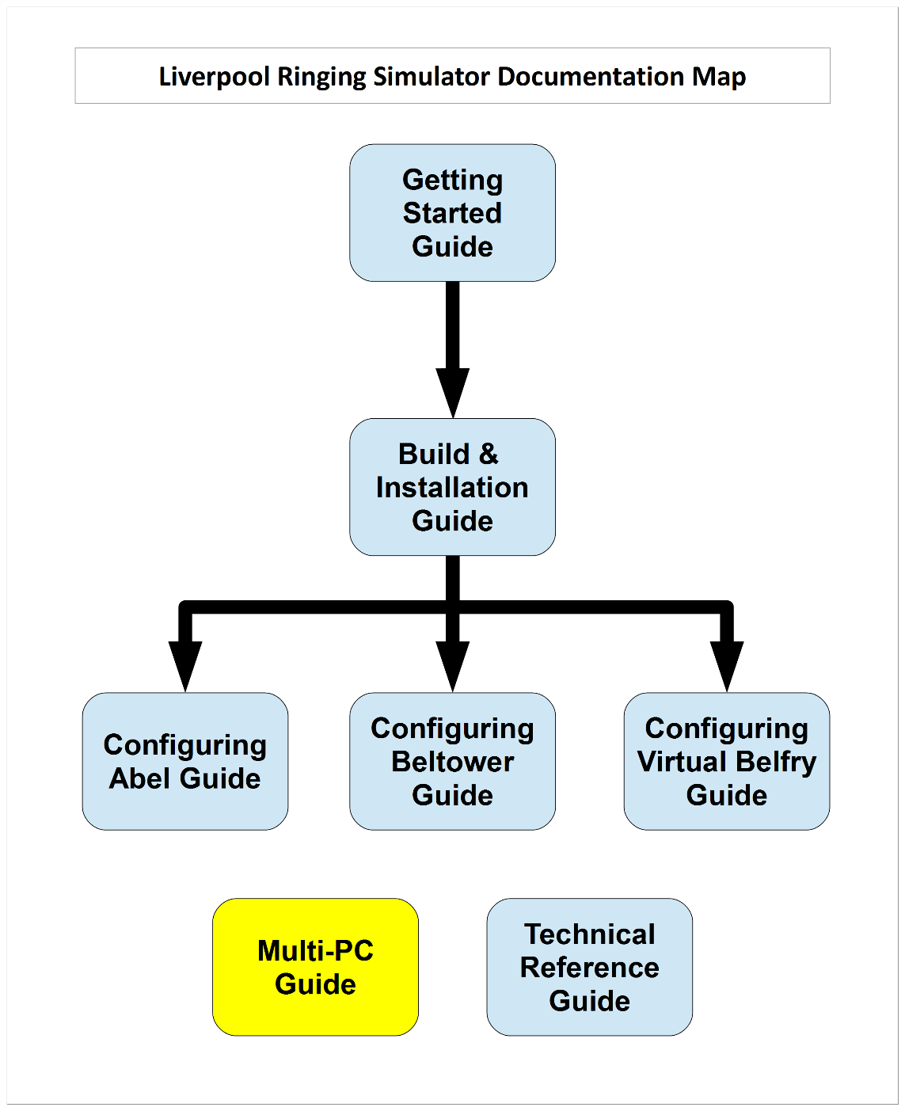
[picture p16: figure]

Figure 1 – Documentation Map

# About This Guide

This guide contains information on building modules which allow multiple PCs to be used concurrently with the Type 2 Liverpool Ringing Simulator:

- Second PC module
- Basic Serial Splitter module

If you are planning to use multiple PCs, it is strongly recommended that you complete and test the core Simulator modules first (Power, Interface, Sensors), as described in the Build & Installation Guide, before moving on to build the multiple PC modules.

In this guide you will find:

- Parts lists and schematics.
- Detailed construction and configuration information.

Notes on configuring the main Simulator Software Packages for use with multiple PCs can be found in the relevant software guides.

Please note that this is a Build-it-Yourself project. No pre-built hardware is available.

# Using Multiple PCs

The Liverpool Ringing Simulator currently supports two alternative modules to use multiple Simulator PCs concurrently. For example, typically this allows more than one ringer with headphones to use the simulator with a simulated band at the same time.

- The Second PC module, as its name suggests, allows a second Simulator PC to be use concurrently with the PC connected to the Power module.
- The Basic Serial Splitter module supports up to four Simulator PCs, or up to eight PCs with an expansion board. Up to two Basic Serial Splitters can also be daisy-chained together, supporting a maximum of 16 PCs.

You can use either the Second PC module, or the Basic Serial Splitter module, depending on how many PCs you want to connect in total.

## Second PC Module

A second Simulator PC can be connected via a Second PC module. This module utilises the second transmitter in the Simulator Interface MAX233 RS-232 serial line driver IC, and a spare core in the Power/Data cable, to provide a separate data feed to the Second PC.

The Second PC module is similar in size and shape to the Power module and is daisy-chained between the Power module and the Simulator Interface module on an RJ45 cable, in a similar manner to the chains of sensors. It also provides surge protection diodes on the power and serial lines.

A typical configuration with a Second PC module is illustrated in the following diagram (only eight sensors are shown to save space, up to 16 may be connected):

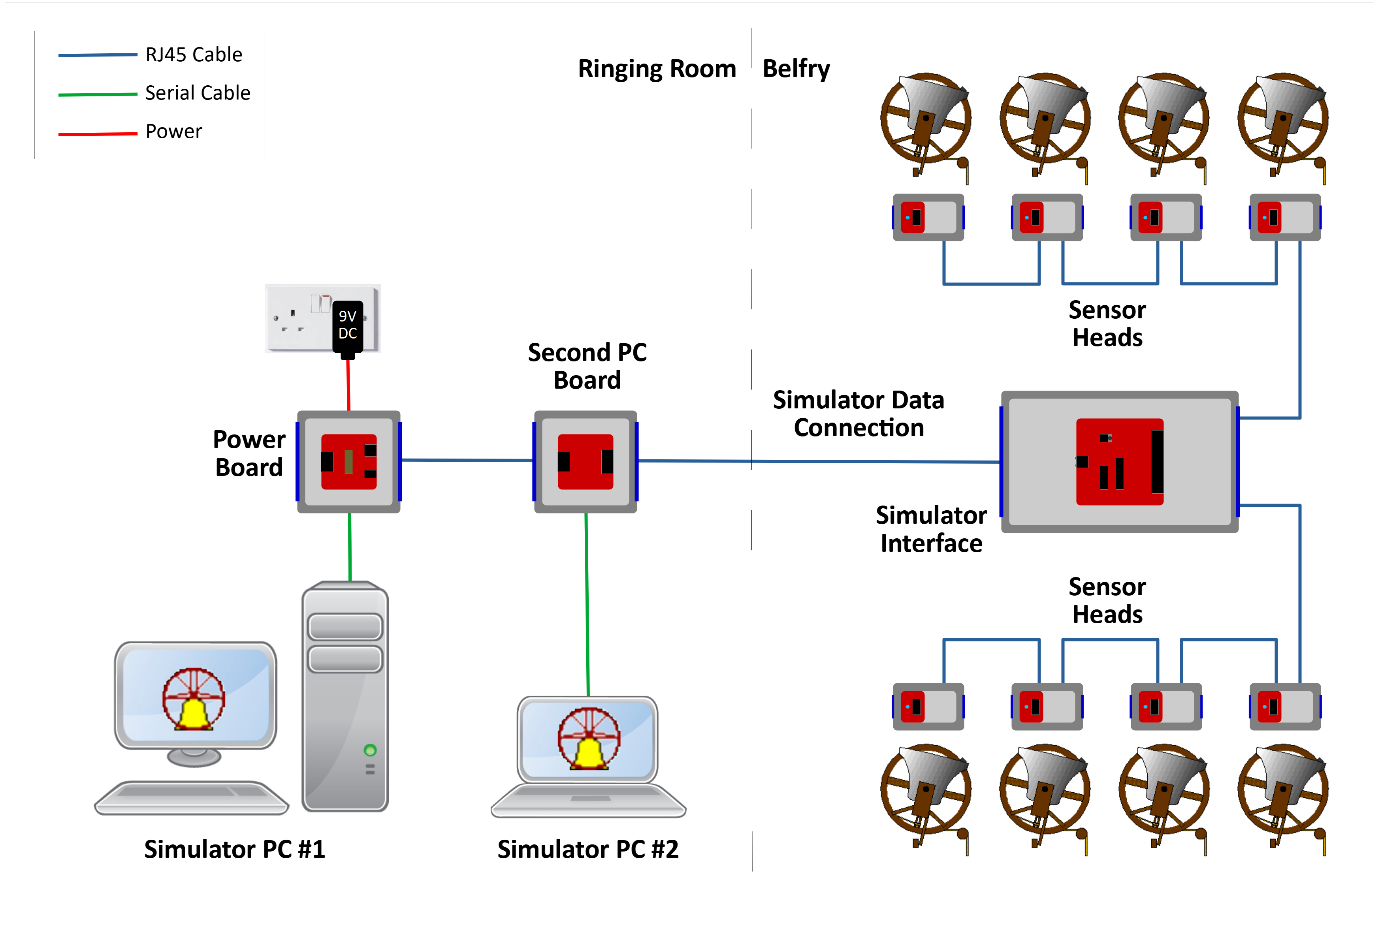
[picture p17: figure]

Figure 2 – Second PC Module General Arrangement

The Second PC receives a read-only copy of the same signals from the Simulator Interface module as the primary PC. Both PCs run their own copies of the Simulator Software Package (or even of different software packages), and the Simulator Software on each PC is configured to filter out unwanted signals.

Only the PC connected to the Power module can be used to configure the Simulator Interface.

The Second PC module requires Revision D or later of the Simulator Interface PCB. A modification is possible for older interface boards, and this is described in an Appendix below.

## Basic Serial Splitter Module

The Basic Serial Splitter module uses additional RS-232 receiver and line driver ICs to copy the stream of signals from the Simulator Interface to multiple PCs. The minimum configuration of the Basic Serial Splitter (the “Master Board”) supports up to four PCs, but this can be linked to a second “Expander Board” which supports four more PCs.

Up to two Basic Serial Splitters can be daisy-chained between the Power module and the Simulator Interface module on RJ45 cables, supporting a maximum of 16 Simulator PCs. The Basic Serial Splitter module also provides surge protection diodes on the power and serial lines.

The maximum configuration of two daisy-chained Basic Serial Splitters is illustrated in the following diagram (only four sensors are shown to save space, up to 16 may be connected):

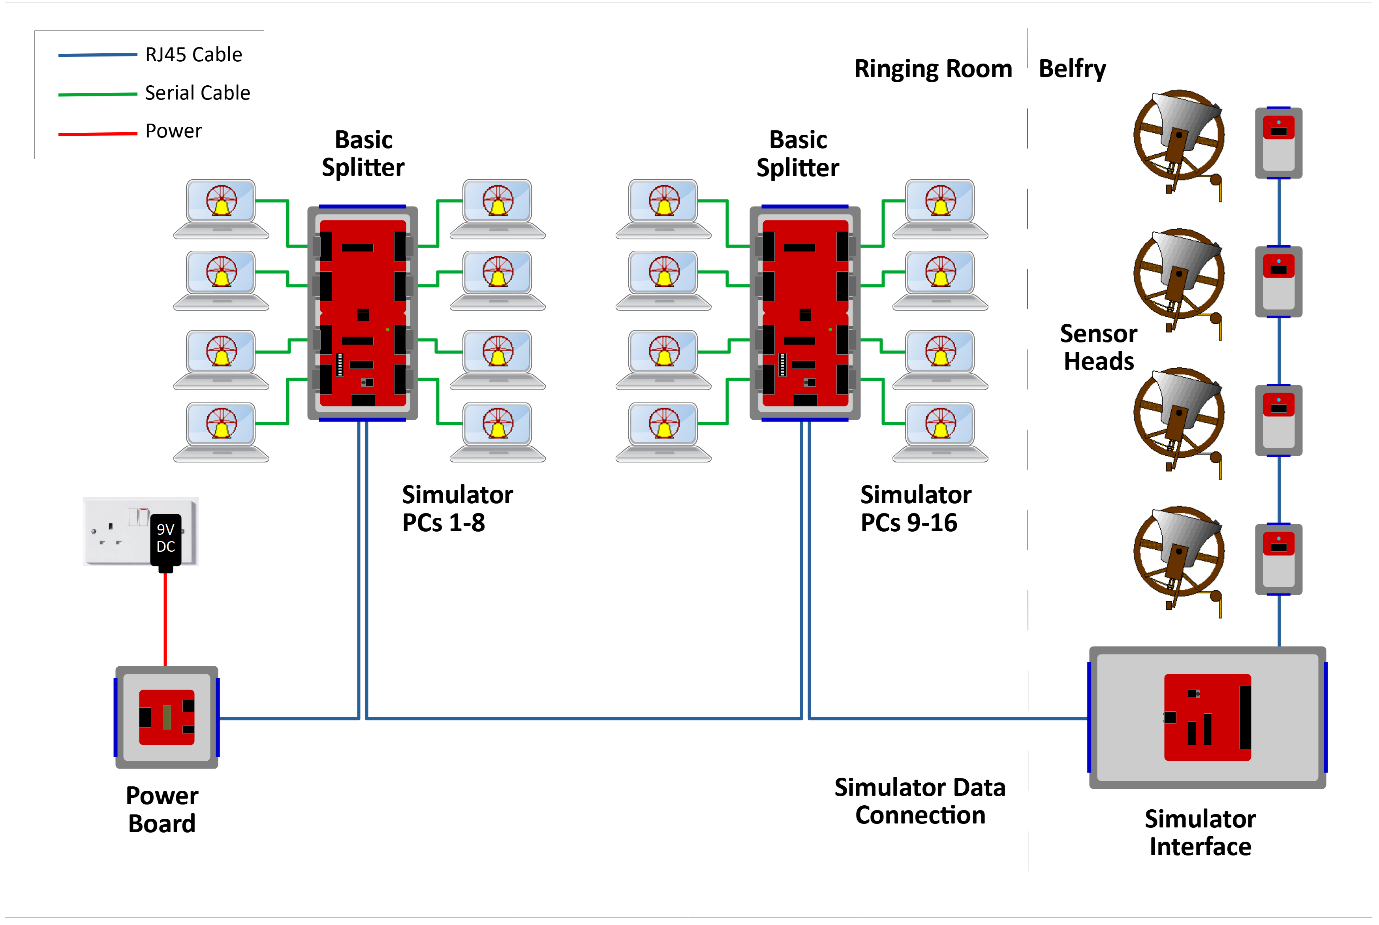
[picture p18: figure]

Figure 3 – Basic Serial Splitter Modules General Arrangement

All Simulator PCs receive a read-only copy of the same signals from the Simulator Interface. Each PC runs its own copy of the Simulator Software Package (or even of different software packages), and the Simulator Software on each PC is configured to filter out unwanted signals.

The PC connector on the Power module is not used with the Basic Serial Splitter.

Any one PC connected to the Basic Serial Splitter can be used to send configuration data to the Simulator Interface, selectable by a switch on the splitter. (If two Basic Serial Splitters are daisy-chained together, only PCs connected to the Splitter nearest to the Power module can be used to configure the Interface.)

Daisy-chaining two Basic Serial Splitters requires Revision D or later of the Simulator Interface PCB. A modification is possible for older interface boards, and this is described in an Appendix below.

## Modules Configurations

In addition to one Simulator Interface module[^2], one Power Module, and between one and 16 Sensor Modules (all covered in the Build & Installation Guide), the multi-PC modules required depend on the number of Simulator PCs to be connected. The following table describes the possible configurations.

Table 1 – Multi-PC Module Configurations

Number of Simulator PCs | Multi-PC Modules Required | Simulator PC Serial Connections
1 | None | Power Module
2 | 1 x Second PC Board | Power Module & Second PC Board
3 or 4 | 1 x Basic Serial Splitter (Master) | Basic Serial Splitter (Power Module serial connector not used)
5 to 8 (Option 1) | 1 x Basic Serial Splitter (Master) 1 x Basic Serial Splitter (Expander) | Basic Serial Splitters (Power Module serial connector not used)
5 to 8 (Option 2) | 2 x Basic Serial Splitter (Master) | Basic Serial Splitters (Power Module serial connector not used)
9 to 12 | 2 x Basic Serial Splitter (Master) 1 x Basic Serial Splitter (Expander) | Basic Serial Splitters (Power Module serial connector not used)
13 to 16 | 2 x Basic Serial Splitter (Master) 2 x Basic Serial Splitter (Expander) | Basic Serial Splitters (Power Module serial connector not used)

# What You Will Need

## Skills

Like the rest of the Liverpool Ringing Simulator, the multi-PC modules are Build-it-Yourself projects. Please refer to the main Build & Installation Guide for details of the skills and tools you will require to build the Simulator.

The Basic Serial Splitter module is more complex to build than the core Simulator modules, so it is probably best to complete and test the core modules before moving on to the multi-PC modules.

Advice and guidance are available from the project via the contact form on the website.

## Parts

Please refer to the main Build & Installation Guide for suggested sources of parts for the multi-PC modules. As with the core Simulator modules, where possible Farnell or CPC part numbers have been given.

## PCBs

Surplus development PCBs may be available from the Liverpool Ringing Simulator Project, please enquire about availability via the contact form on the website.

The multi-PC modules use two basic types of PCB:

- Second PC Board.
- Basic Serial Splitter Board

Note that the Basic Serial Splitter has been designed so that the same type of PCB can be built either as the Master Board or the optional Expander Board.

Suggested sources of PCBs are listed in the main Build & Installation Guide, and PCB design files, known as “Gerber files”, are available from the project GitHub repository:

- https://github.com/Simulators/simulator-type2

### PCB Design Software Change

The Cadsoft Eagle design tool, now owned by AutoDesk, and originally used for all Liverpool Ringing Simulator Project PCBs, is being discontinued. As of May 2025, PCB designs have been migrated to the open source KiCad EDA package, and KiCad CAD files and KiCad-generated Gerber files have been made available in the GitHub repository.

The project documentation has also being updated with schematics and PCB layouts generated by KiCad, but board photographs may continue to show boards designed using Eagle. There may be cosmetic differences between the Eagle and KiCad versions of PCBs, but the functionality of the first KiCad and final Eagle versions of boards will be the same, except where noted otherwise.

# Hardware Assembly

This section describes the assembly of the multi-PC module options. It also covers the suggested enclosures.

Before you start construction of the multi-PC module hardware, check the Release Notes and the issues log on the project GitHub repository for any open or late-breaking issues which may affect your build:

- https://github.com/Simulators/simulator-type2/issues

## Polarised Components

A number of the components of the multi-PC modules are polarised and must be fitted the right way round for correct operation. Guidance is given in the main Build & Installation Guide on correct orientation of the polarised components, but if in any doubt consult the component supplier or the manufacturer’s data sheets. Fitting a polarised component the wrong way round may result in damage to the component.

## Second PC Board

### Parts List

Table 2 – Second PC Module PCB Parts List

Reference | Component | Notes
PCB | Type 2 Second PC Board PCB
PC Connector | Right Angle PCB D Sub Connector 9 Pin | Farnell 1848372*
Connector | AMP TE Connectivity 5406526-1 | Farnell 2452587
D1 | SA12A | Farnell 2679618
D2, D3, D4 | SA15CA | Farnell 2762809

(* Farnell part 1848372 has threaded screw lock posts for cable plugs fitted with locking screws. If you do not want these, use alternative part 1084701 instead.)

### Schematic

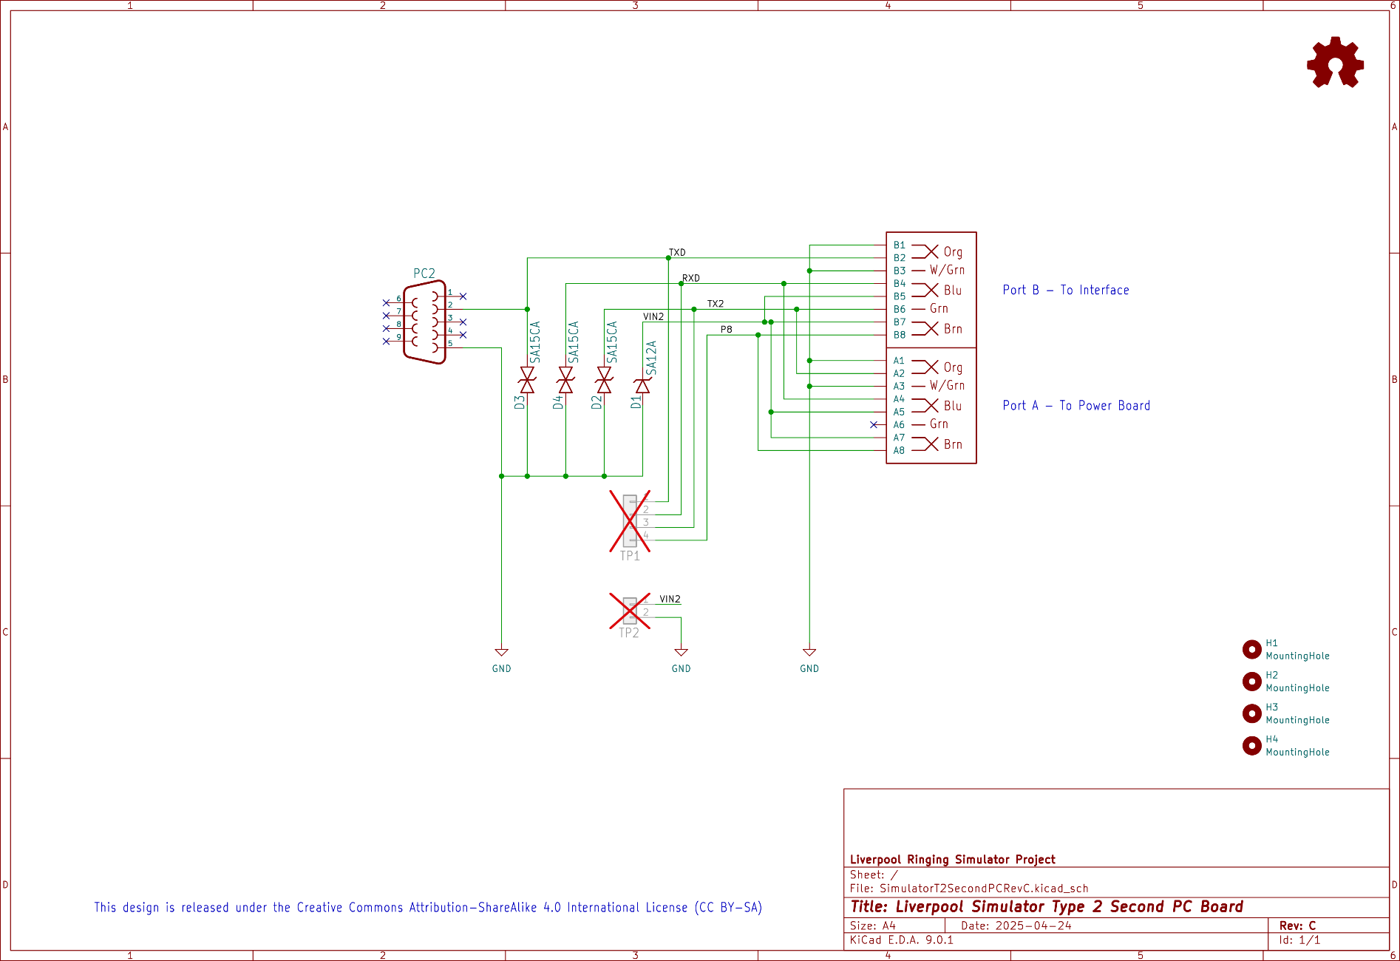
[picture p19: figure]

### Parts

The following photograph shows the complete set of parts required for the Second PC module PCB.

Figure 4 – Second PC Module Parts

### PCB Layout

The following diagram shows the layout of the Second PC module PCB. All components are mounted on the top (silkscreen) side of the board.

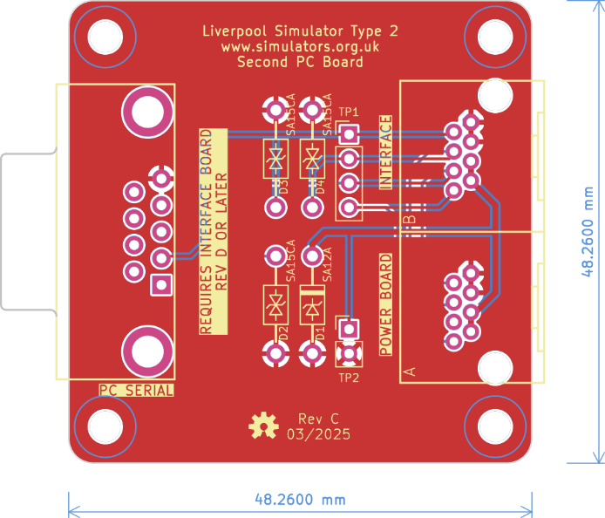
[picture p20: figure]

Figure 5 – Second PC Module PCB Layout

### Construction

All the components on the Second PC module PCB are mounted on top, silkscreen, side of the board.

- If your Second PC PCB came from a panelized PCB, lightly file down any remaining nibs from the edges of the board.
- Pay close attention to the correct orientation of the polarised diode D1.
- D2, D3 & D4 are not polarised.
- There is no need to fit pins to the test point holes TP1 – TP2.

A completed Second PC module is shown in the following photograph.

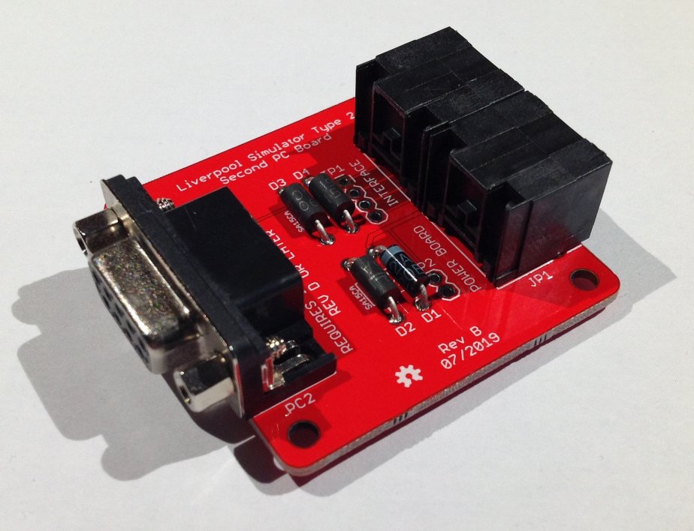
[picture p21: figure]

Figure 6 – Completed Second PC Module

### Enclosure

The Second PC module may be housed in a 0.75 litre Really Useful Box, with space for a USB-Serial adapter if required, and with the same drilling as for the core Power module. The PCB may be mounted on standoffs, as described in the Build & Installation Guide.

## Basic Serial Splitter Module – Master Board

### Parts List

Table 3 – Basic Serial Splitter Module Master Board Parts List

Reference | Component | Notes
PCB | Type 2 Basic Serial Splitter PCB
R1 | 1kΩ 0.25W Metal Film | Farnell 9341102
C1, C2 | 100µF 25V Electrolytic (6.3mm Radial) | Farnell 9451188
C3, C5, C6 | 330nF (0.33µF) 50V MLCC[^3] (2.54mm Radial) | Farnell 2819679
C4 | 47nF (0.047µF) 50V MLCC (2.54mm Radial) | Farnell 2819680
C7, C8, C9, C10, C11, C12 | 100nF (0.1µF) 50V MLCC (2.54mm Radial) | Farnell 1457655
D1 | SA12A | Farnell 2679618
D2, D3, D4 | SA15CA | Farnell 2762809
D5 | 1N4001 | Farnell 1458986
D6 | SA5.0A | Farnell 1886342
IC1 | MC7805CTG (replacement for LM7805) | Farnell 9666095
IC2 | MAX3323EEPE+ | Farnell 2511866
IC3 | MAX208CNG+ | Farnell 2511906
RJ45 Connector | AMP TE Connectivity 5406526-1 | Farnell 2452587
PC1, PC2, PC3, PC4 | Right Angle PCB D Sub Connector 9 Pin | Farnell 1848372*
SW1 | DIP Switch 8-Way SPST | Farnell 9472115
IC Socket | 16-pin, 0.3” pitch | Farnell 2445622
IC Socket | 24-pin, 0.3” pitch | Farnell 2672303
LED1 | Green 3mm | Farnell 1581114
Hardware | 6mm M3 PCB Standoffs, Nuts & Screws | eBay

(* Farnell part 1848372 has threaded screw lock posts for cable plugs fitted with locking screws. If you do not want these, use alternative part 1084701 instead.)

### Schematic

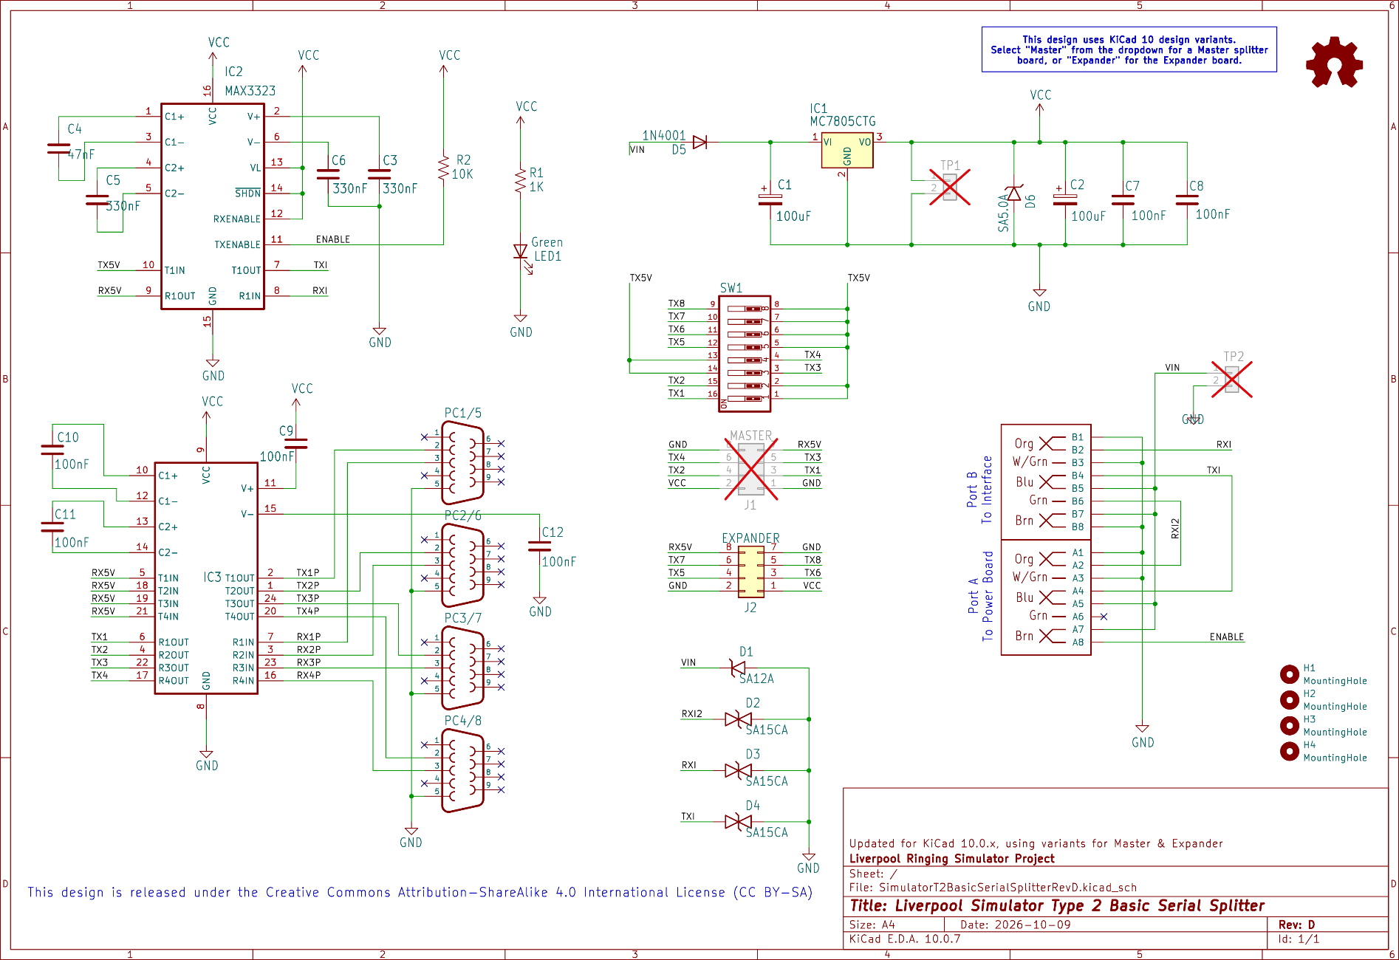
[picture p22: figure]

### Parts

The following photograph shows the complete set of parts required for the Basic Serial Splitter Module Master Board.

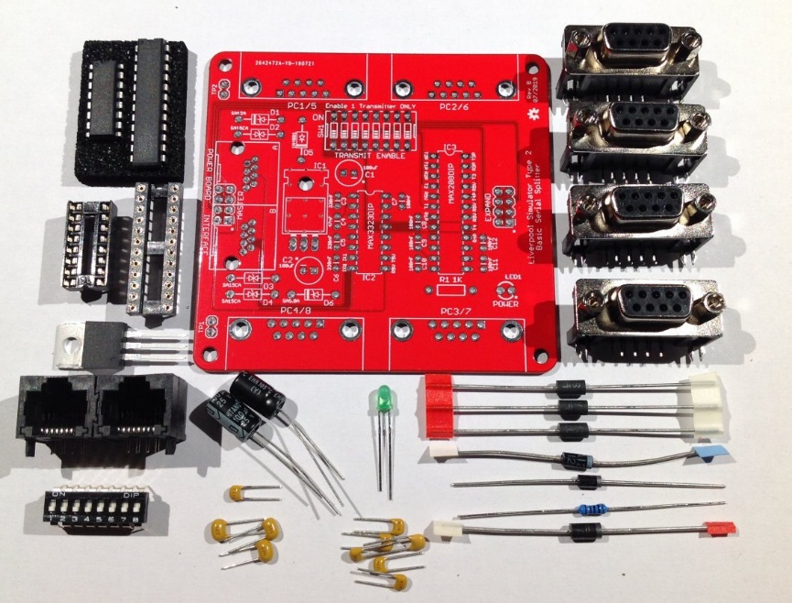
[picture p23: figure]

Figure 7 – Basic Serial Splitter Module Master Board Parts

### PCB Layout

The following diagram shows the layout of the Basic Serial Splitter Master PCB. All components are mounted on the top (silkscreen) side of the board. Note that the Expander uses an identical PCB.

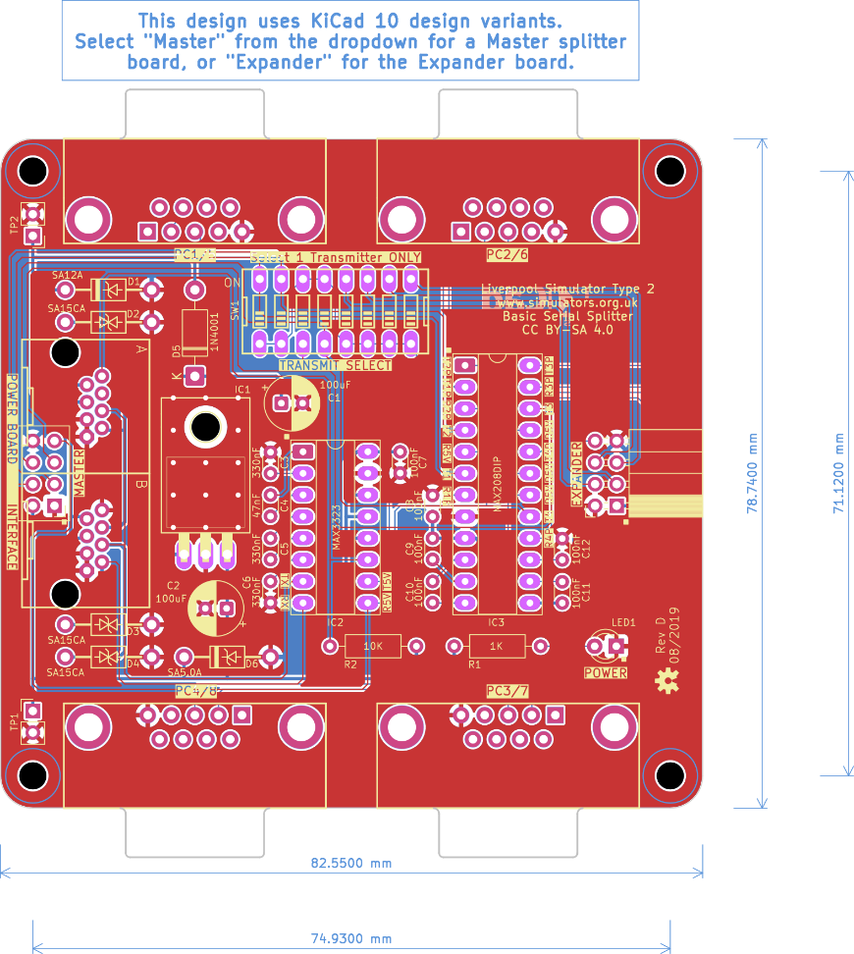
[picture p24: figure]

Figure 8 – Basic Serial Splitter Module Master Board Layout

### Construction

All the components on the Basic Serial Splitter Module Master Board are mounted on top, silkscreen, side of the board.

- Start by soldering the components with the lowest profile (resistors, ceramic capacitors), then the remainder of the components in order of increasing height, ending with the RJ45 and 9-Pin Serial connectors.
- The use of IC sockets for IC2 & IC3 is strongly recommended.
- When fitting the voltage regulator, carefully bend the pins through 90 degrees so that the mounting hole in the tab lines up with the mounting hole in the PCB. Secure the regulator to the board with an M3 nut, bolt and washer before soldering the pins. A tiny smear of heatsink compound between the tab and board will improve heatsinking. No additional heatsink is required.
- Before fitting the socketed ICs, connect the board to a power supply (using the Power module and a short RJ45 cable) and check using a multimeter that the supply voltage appears on the pins of TP2, and that +5V and 0V appear on the pins of TP1 and the correct pins of the IC sockets. The pins are identified in the diagram below. The green power LED should also light. Disconnect the power supply and fit the ICs.

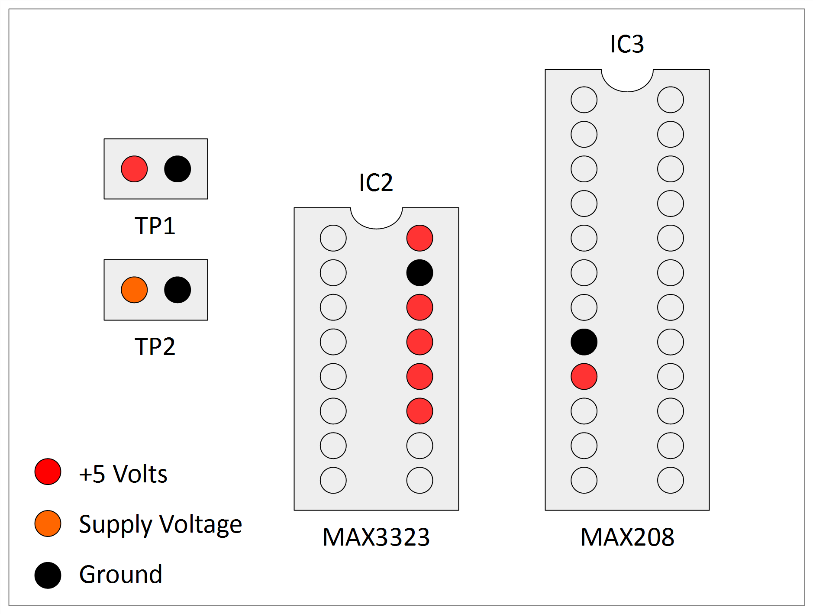
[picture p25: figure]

Figure 9 – Voltage Check Pin Locations

- Pay close attention to the correct orientation of the polarised components D1, D5, D6, C1, C2, IC1, IC2, IC3 & LED1.
- Diodes D2, D3 & D4 are not polarised.
- The mounting lugs of the RJ45 and 9-Way D-Sub connectors clip into the holes in the PCB. Make sure the connector pins are correctly aligned with the holes before clipping the connector into the board, and then soldering the pins.

A completed Basic Serial Splitter module Master Board is shown in the following photograph.

Figure 10 – Completed Basic Serial Splitter Module Master Board

## Basic Serial Splitter Module – Expander Board

The Expander Board links to the Master Board and provides four additional serial ports for Simulator PCs. Only one Expander can be linked to a Master Board.

### Parts List

Table 4 – Basic Serial Splitter Module Expander Board Parts List

Reference | Component | Notes
PCB | Type 2 Basic Serial Splitter PCB
C8, C9, C10, C11, C12 | 100nF (0.1µF) 50V MLCC (2.54mm Radial) | Farnell 1457655
IC3 | MAX208CNG+ | Farnell 2511906
PC5, PC6, PC7, PC8 | Right Angle PCB D Sub Connector 9 Pin | Farnell 1848372*
IC Socket | 24-pin, 0.3” pitch | Farnell 2672303
Master Connector | 8-Way Right Angle Header | Farnell 2356196
Expand Connector[^4] | 8-Way Right Angle Socket | Farnell 1668343
Hardware | 6mm M3 PCB Standoffs, Nuts & Screws | eBay

(* Farnell part 1848372 has threaded screw lock posts for cable plugs fitted with locking screws. If you do not want these, use alternative part 1084701 instead.)

### Schematic

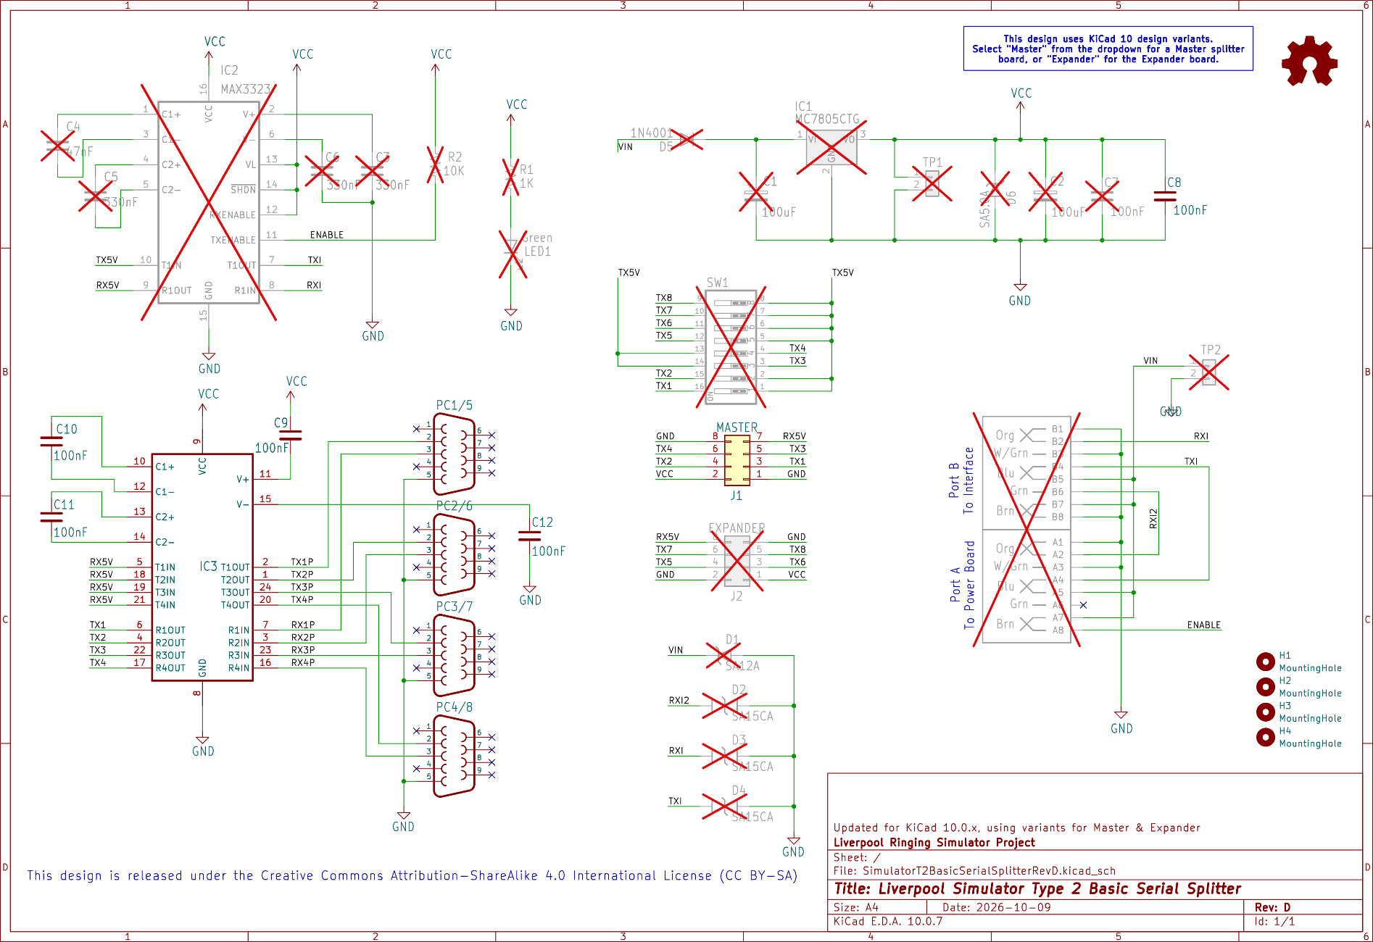
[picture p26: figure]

### Parts

The following photograph shows the complete set of parts required for the Basic Serial Splitter Expander PCB.

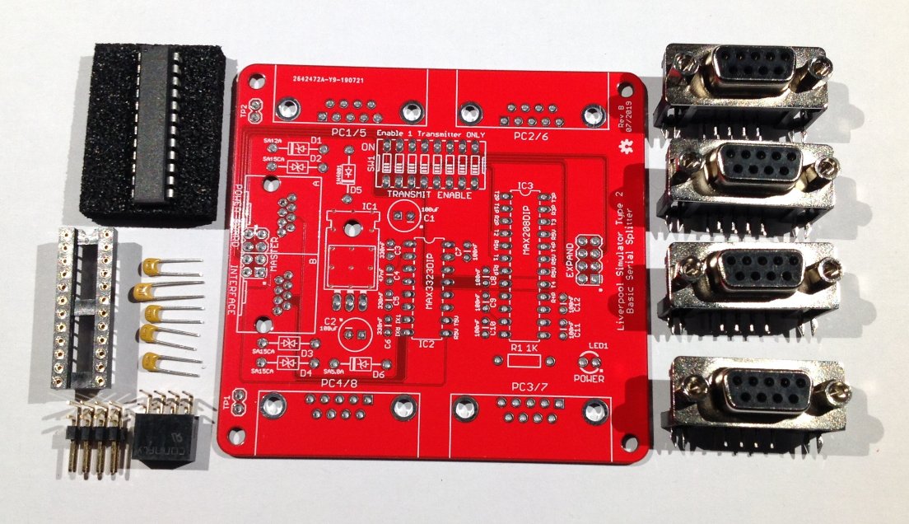
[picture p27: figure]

Figure 11 – Basic Serial Splitter Module Expander Board Parts

### Construction

The Basic Serial Splitter module Expander uses the same PCB as the Master board, shown in the diagram in the previous section. All the components are mounted on top, silkscreen, side of the board.

- Fit only the parts listed in the Expander parts list above. All remaining positions on the Expander PCB can be left empty.
- Note that the 8-Way Right Angle Socket is fitted to the Expand position on the MASTER board, not the Expander. It mates with the 8-Way Right Angle Header fitted to the Master position on the Expander board, as shown in the photographs below.
- The use of an IC socket for IC3 is strongly recommended.
- Before fitting the socketed IC, connect the board to a power supply (via the Master board and a Power Board and a short RJ45 cable) and check using a multimeter that +5V and 0V appear on TP1 and the correct pins of the IC3 socket. The pins are the same as identified in the diagram above. Disconnect the power supply and fit the ICs.
- Pay close attention to the correct orientation of the polarised component IC3.
- The mounting lugs of the 9-Way D-Sub connectors clip into the holes in the PCB. Make sure the connector pins are correctly aligned with the holes before clipping the connector into the board, and then soldering the pins.

A completed Basic Serial Splitter module with Master and Expander Boards is shown in the following photograph.

Figure 12 – Basic Serial Splitter Master & Expander PCBs

## Enclosures

The suggested enclosures for the Second PC module and the Basic Serial Splitter module are from the “Really Useful” series of plastic boxes, widely available from hobby and stationery shops, or direct from the manufacturer[^5].

- Drilling large diameter holes with twist drills can result in bit grabbing and damage to the enclosure. Use a 20mm hole saw[^6] for cable holes, this makes the process of drilling the enclosure much easier and safer.
- Support the inside surface of the enclosure with a block of scrap wood when cutting the holes and cut at a low speed.
- Clean up any rough edges or swarf with a sharp knife.
- Cables are run into the enclosures via PVC grommets, which provide some protection against dust and moisture.
- A set of suitable paper templates is available from the GitHub repository as a PDF and should be printed out full size with no scaling.

### Parts List

Table 5 – Enclosures Parts List

Reference | Component | Notes
Second PC Module | Really Useful Box® 0.75 Litre | 195 x 135 x 55mm
Basic Serial Splitter | Really Useful Box® 0.55 Litre | 220 x 100 x 40mm
Grommets | 20mm Closed Grommets | Screwfix 884VT

### Second PC Module Enclosure

The following diagram shows the holes required in a 0.75 litre Really Useful Box for the Second PC module.

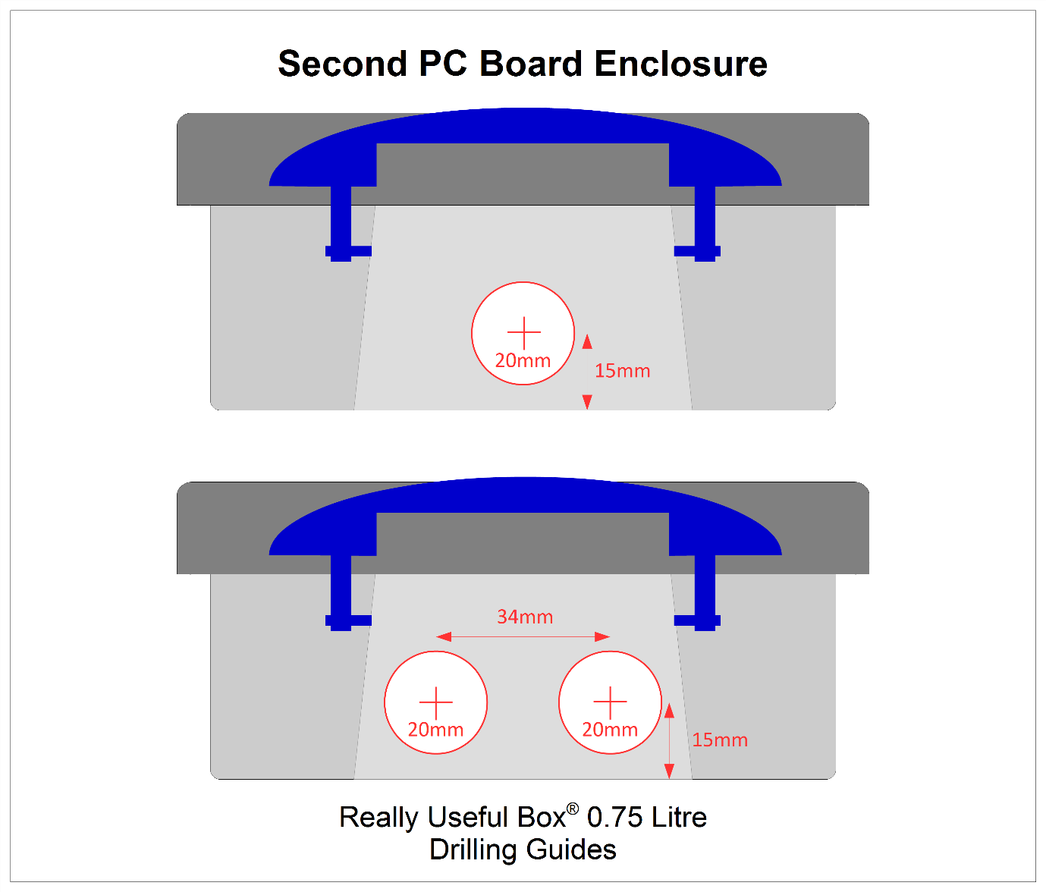
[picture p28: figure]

Figure 13 – Second PC Module Enclosure Drilling Guide

### D Sub Serial Connector Alternative Drilling

The single 20mm hole in the Second PC Module enclosure is sufficient for a USB-Serial adapter with a USB-A connector. If you are using an RS-232 cable with a 9-pin D Sub Connector, then a larger hole will be required. Drill two 20mm holes and cut out the area between them as shown by the dotted lines in the diagram below.

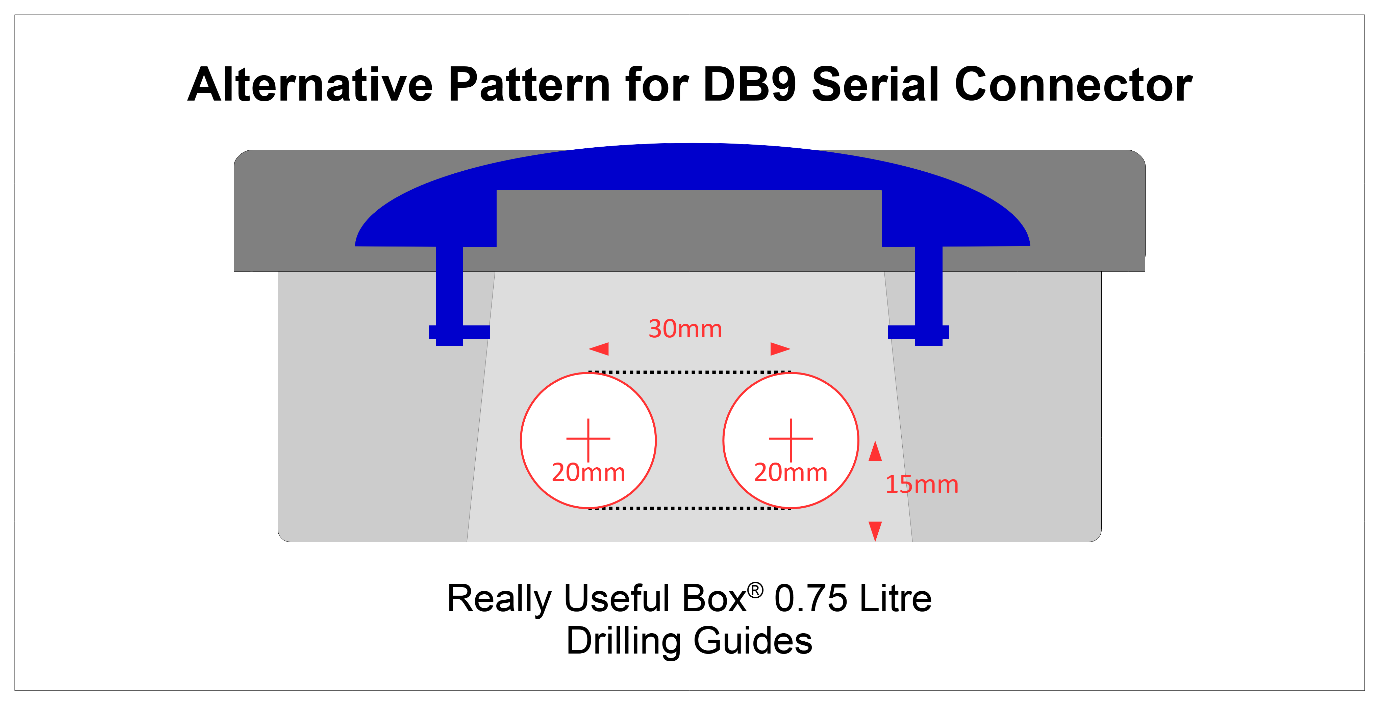
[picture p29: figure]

Figure 14 – Alternative Drilling Guide for DB9 Connector

### Basic Serial Splitter Enclosure

The following diagram shows the holes required in a 0.55 litre Really Useful Box for the Basic Serial Splitter. A single enclosure is big enough for a linked Master Board and Expander Board.

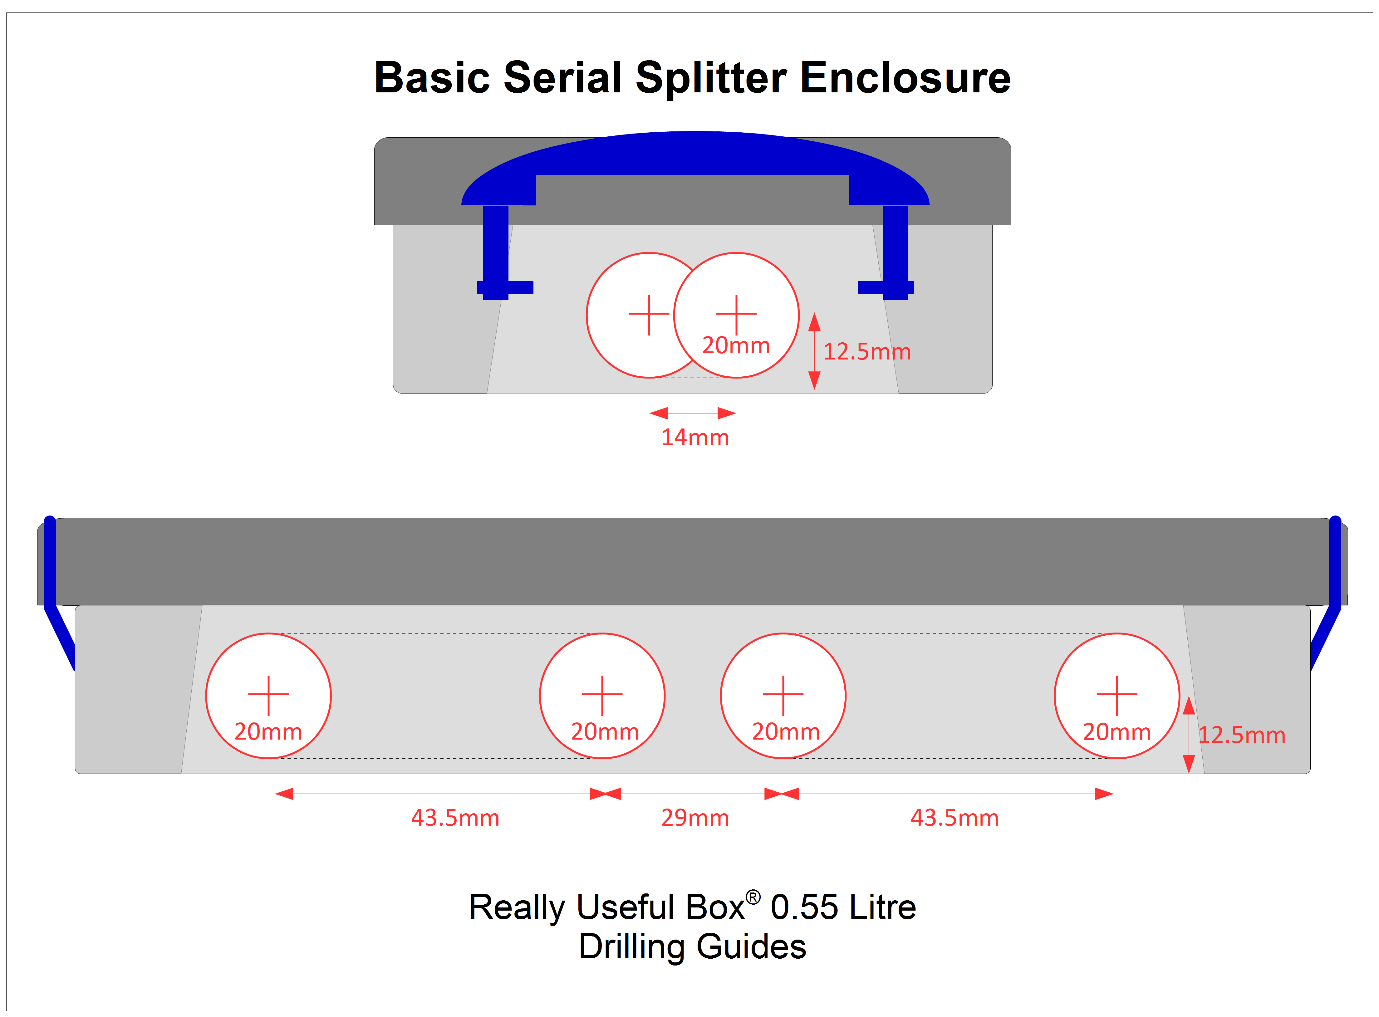
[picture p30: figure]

Figure 15 – Basic Serial Splitter Module Enclosure Drilling Guide

The two 20mm holes in the end of the enclosure overlap. The material between each pair of 20mm holes in each side of the enclosure should be cut out, leaving two slots. This can be seen in the completed assembly module photograph below.

### PCB Mounting Hardware

The Basic Serial Splitter PCBs should be secured to the base of the enclosure using M3 x 6mm Nylon PCB standoffs, nuts, screws and washers.

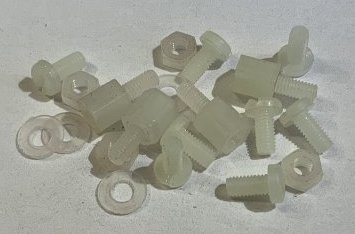
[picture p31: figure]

Figure 16 – PCB Mounting Hardware

The following photograph shows how the bare PCBs can be used to mark out the base of the Basic Serial Splitter enclosure prior to drilling.

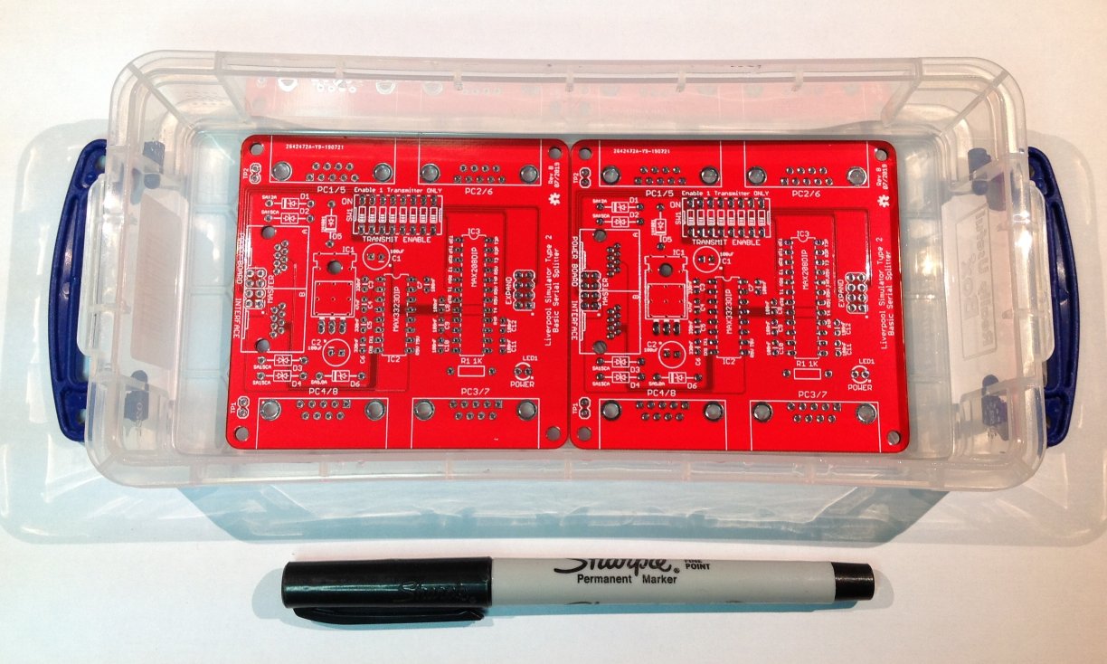
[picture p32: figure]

Figure 17 – Enclosure Marking Out

The Basic Serial Splitter enclosure marked out for drilling is shown in the following photograph.

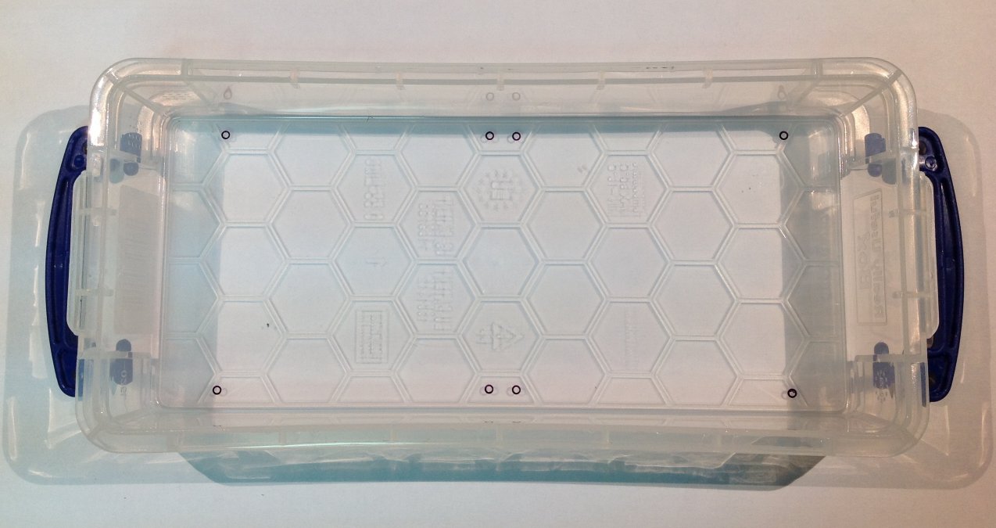
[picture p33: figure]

Figure 18 – Enclosure Marked for Drilling

## Completed Assemblies

### Second PC Module

The following photograph shows a completed Second PC Board, with a USB-Serial adapter also inside the enclosure.

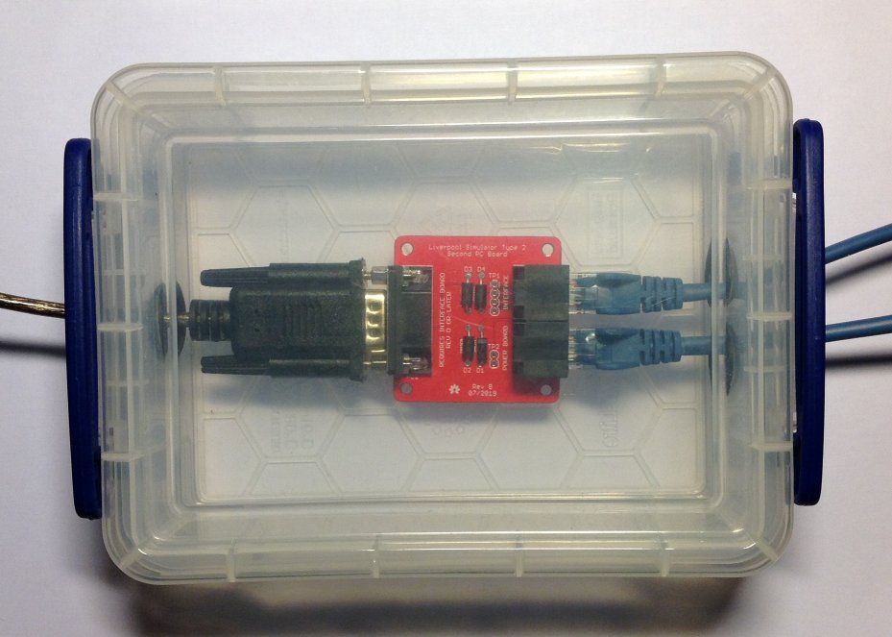
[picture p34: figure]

Figure 19 – Completed Second PC Module in Enclosure

### Basic Serial Splitter Module

The following photographs show completed Basic Serial Splitter modules, with Master & Expander Boards.

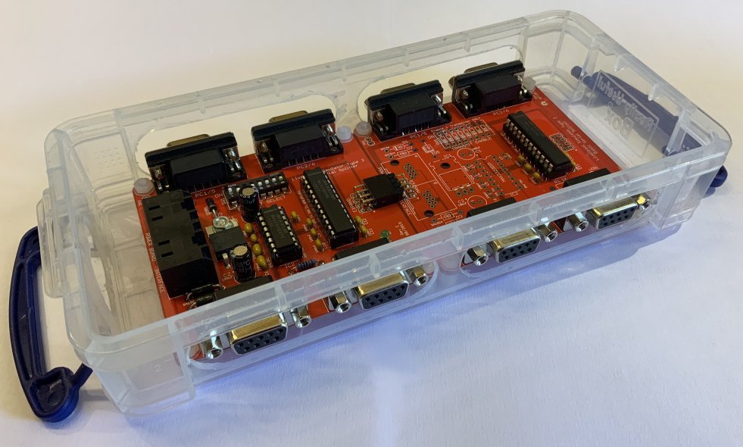
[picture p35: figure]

Figure 20 – Completed Basic Serial Splitter Module in Enclosure

Figure 21 – Completed Basic Serial Splitter Module

## Cabling

### Second PC Module

The Second PC module is daisy-chained between the Simulator Interface module and the Power module, as shown in the following diagram.

- As with the core Simulator cabling, the cable is a standard straight-through (not crossover) Cat5e or Cat6 Ethernet network cable, with RJ45 connectors.
- The maximum total length of cable tested is 30m (25m between Interface and Second PC module, and a further 5m to the Power module), although longer cables may be feasible.

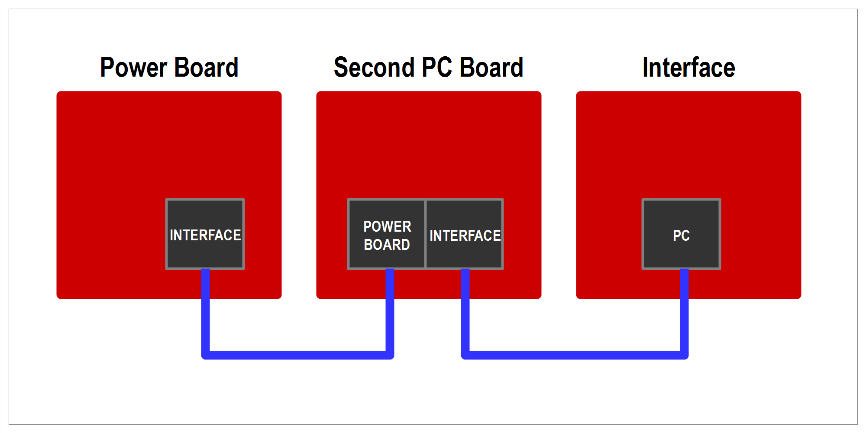
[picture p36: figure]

Figure 22 – Second PC Module Cabling

### Basic Serial Splitter Module

The Basic Serial Splitter module is daisy-chained between the Simulator Interface module and the Power module, as shown in the following diagram.

- One or two Basic Serial Splitter modules may be connected as shown, providing ports for up to 8 or up to 16 Simulator PCs.
- As with the core Simulator cabling, the cable is a standard straight-through (not crossover) Cat5e or Cat6 Ethernet network cable, with RJ45 connectors.
- The maximum total length of cable tested is 30.5m (25m between Interface and Basic Serial Splitter module, a further 5m to the second Splitter module, and a short cable to the Power module), although longer cables may be feasible.

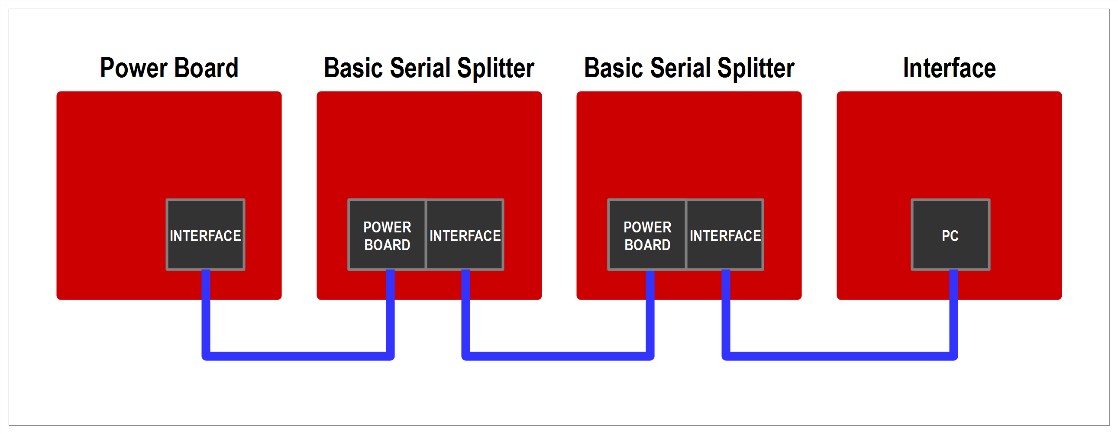
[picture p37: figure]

Figure 23 – Basic Serial Splitter Module Cabling

# Appendix: Older Interface Boards

The Second PC module works with Simulator Interface PCBs from PCB Revision D onwards – no modification of these interface boards is necessary.

Daisy-chaining two Basic Serial Splitter modules together works with Simulator Interface PCBs from PCB Revision D onwards – no modification of these interface boards is necessary.

A single Basic Serial Splitter module will work with any version of the Simulator Interface PCB.

Older Simulator Interface PCBs may be modified for use with the Second PC module, or to allow daisy-chaining of two Basic Serial Splitter modules, with the addition of two wire links. On the solder side of the Simulator Interface PCB, fit two small wire links:

- Between pins 1 and pin 2 of IC2.
- Between pin 18 of IC2 and pin 2 of TP5 (pin 1 of TP5 is marked with a square pad).

Remember that when working on the solder side of the PCB the IC pin numbers will be reversed. The locations of the links are shown in the diagram below:

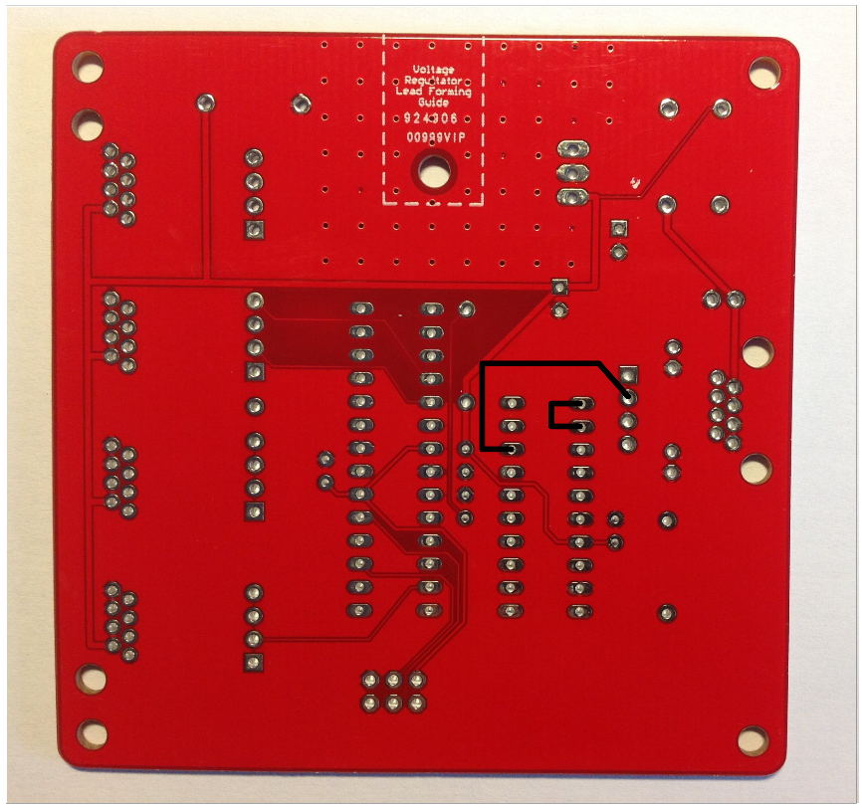
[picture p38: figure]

Figure 24 – Modification for Older Interface PCBs

An example of a modified Simulator Interface PCB is shown in the following photograph.

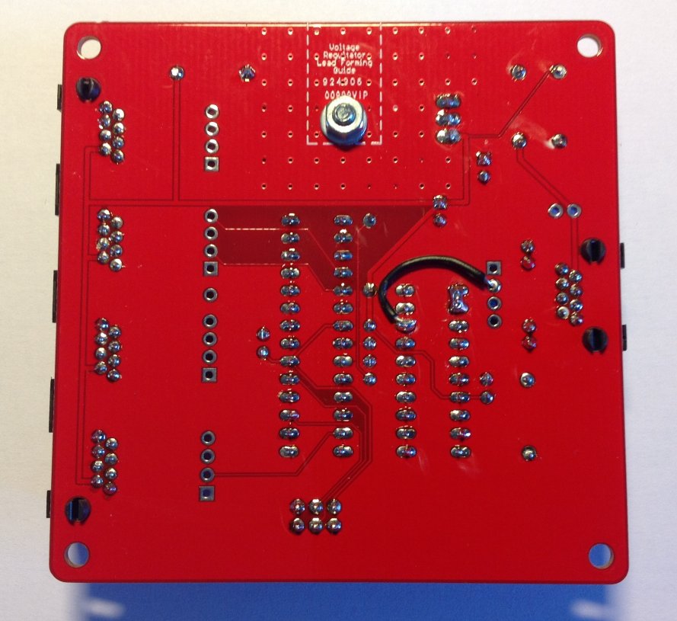
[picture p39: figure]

Figure 25 – Modified Interface Board

# Appendix: Configuring the Interface

When multiple PCs are connected, only one PC can be used to configure the Simulator Interface using a terminal emulator (as described in the Build & Installation Guide).

- When using the Second PC module, only the PC connected to the Power module can be used to configure the Interface.
- The PC connected to the Second PC module is not able to send data to the Interface and cannot be used for configuration.
- When using a single Basic Serial Splitter module, any one PC (selected by the 8-way DIP switch on the PCB) can be used to configure the Interface. Only one PC should be enabled at any time.
- When two Basic Serial Splitter modules are connected, any one PC (selected by the 8-way switch) connected to the Splitter closest to the Power module can be used to configure the Interface. The PCs connected to the Splitter closer to the Interface module are automatically disabled for configuration use.
- The PC connector on the Power module is not used at all when the Basic Serial Splitter(s) is used and must not have a PC connected to it.

# Licensing & Disclaimers

## Documentation

All original manuals and other documentation (including PCB layout CAD files and schematics) released as part of the Liverpool Ringing Simulator project[^7] are released under the Creative Commons Attribution-ShareAlike 4.0 International License (CC BY-SA),[^8] which includes the following disclaimers:

Unless otherwise separately undertaken by the Licensor, to the extent possible, the Licensor offers the Licensed Material as-is and as-available, and makes no representations or warranties of any kind concerning the Licensed Material, whether express, implied, statutory, or other. This includes, without limitation, warranties of title, merchantability, fitness for a particular purpose, non-infringement, absence of latent or other defects, accuracy, or the presence or absence of errors, whether or not known or discoverable. Where disclaimers of warranties are not allowed in full or in part, this disclaimer may not apply to You.

To the extent possible, in no event will the Licensor be liable to You on any legal theory (including, without limitation, negligence) or otherwise for any direct, special, indirect, incidental, consequential, punitive, exemplary, or other losses, costs, expenses, or damages arising out of this Public License or use of the Licensed Material, even if the Licensor has been advised of the possibility of such losses, costs, expenses, or damages. Where a limitation of liability is not allowed in full or in part, this limitation may not apply to You.

## Software

All original software released as part of the Liverpool Ringing Simulator project is released under the GNU General Public Licence (GPL), Version 3[^9], and carries the following disclaimers:

This program is free software: you can redistribute it and/or modify it under the terms of the GNU General Public License as published by the Free Software Foundation, either version 3 of the License, or (at your option) any later version.

This program is distributed in the hope that it will be useful, but WITHOUT ANY WARRANTY; without even the implied warranty of MERCHANTABILITY or FITNESS FOR A PARTICULAR PURPOSE. See the GNU General Public License for more details.

# Acknowledgements

The Liverpool Ringing Simulator project relies extensively on work already undertaken by others, notably David Bagley (developer of the Bagley MBI), Chris Hughes and Simon Feather (developers of the Abel simulator software package), Derek Ballard (developer of the Beltower simulator software package), Doug Nichols (developer of the Virtual Belfry simulator software package), and others. Their invaluable contributions are hereby acknowledged. Sources used are referenced in the footnotes throughout.

Thanks are also owed to the Ringing Masters and ringers of the following towers for their willingness to be the crash test dummies of simulator design and testing.

- Liverpool Cathedral
- St George’s, Isle of Man
- St Mary, Chirk, Wrexham
- St John, Higham, Kent
- St Margaret, Crick, Northamptonshire
- St Mary & St Peter, Lois Weedon, Northamptonshire

Really Useful Box ® is a registered trademark of Really Useful Products Ltd.

[^1] https://creativecommons.org/licenses/by-sa/4.0/
[^2] Configurations with more than one Simulator Interface are possible, but unusual.
[^3] Multi-Layer Ceramic Capacitor
[^4] Note that this component is installed on the MASTER board.
[^5] https://www.reallyusefulproducts.co.uk/
[^6] Frequently used by electricians.
[^7] https://www.simulators.org.uk/
[^8] https://creativecommons.org/licenses/by-sa/4.0/
[^9] https://www.gnu.org/licenses/gpl-3.0.en.html

Type 2 Simulator – Multi-PC Guide 1.7

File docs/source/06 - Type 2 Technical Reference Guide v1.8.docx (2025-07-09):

Type 2 Liverpool Ringing Simulator

06 – Technical Reference Guide

Author: Andrew Instone-Cowie

Date: 09 July 2025

Version: 1.8

# Index of Figures

# Index of Tables

# Document History

Version | Author | Date | Changes
0.1 | A J Instone-Cowie | 26/12/2019 | First Draft.
1.0 | A J Instone-Cowie | 28/12/2019 | First Release.
1.1 | A J Instone-Cowie | 02/01/2020 | Add Basic Serial Splitter hardware details, more cabling information, logic analyser trace.
1.2 | A J Instone-Cowie | 18/08/2020 | Minor update.
1.3 | A J Instone-Cowie | 27/08/2021 | Add Circuit Protection, DB9 pin-outs, minor corrections.
1.4 | A J Instone-Cowie | 19/06/2024 | Update for interface firmware 3.7, MBI Protocol 0xFD command support in Abel 10.3.2, update software versions. Update external links.
1.5 | A J Instone-Cowie | 03/03/2025 | Add Type 1 – Type 2 Interface Adapter.
1.6 | A J Instone-Cowie | 07/05/2025 | Eagle to KiCad PCB design tool migration. Updated schematics and board layouts.
1.7 | A J Instone-Cowie | 09/05/2025 | Restyled MR sensors as “Magnetic Sensors” for consistency with Build & Installation Guide.
1.8 | A J Instone-Cowie | 07/07/2025 | Debugging options changes for Firmware 3.8.

Copyright ©2019-25 Andrew Instone-Cowie.

Cover image: Type 2 Simulator Interface PCB Design.

# Licence

This work is licensed under a Creative Commons Attribution-ShareAlike 4.0 International License.[^1]

Unless otherwise separately undertaken by the Licensor, to the extent possible, the Licensor offers the Licensed Material as-is and as-available, and makes no representations or warranties of any kind concerning the Licensed Material, whether express, implied, statutory, or other. This includes, without limitation, warranties of title, merchantability, fitness for a particular purpose, non-infringement, absence of latent or other defects, accuracy, or the presence or absence of errors, whether or not known or discoverable. Where disclaimers of warranties are not allowed in full or in part, this disclaimer may not apply to You.

To the extent possible, in no event will the Licensor be liable to You on any legal theory (including, without limitation, negligence) or otherwise for any direct, special, indirect, incidental, consequential, punitive, exemplary, or other losses, costs, expenses, or damages arising out of this Public License or use of the Licensed Material, even if the Licensor has been advised of the possibility of such losses, costs, expenses, or damages. Where a limitation of liability is not allowed in full or in part, this limitation may not apply to You.

# Attribution

The Creative Commons Attribution-ShareAlike (CC BY-SA) licence permits you to re-use this material for any purpose you wish, subject to the conditions of the licence, including providing attribution of the source.

The following is suggested as a suitable form of attribution for this document, or extracts thereof:

Type 2 Technical Reference Guide, Liverpool Ringing Simulator Project (https://www.simulators.org.uk). This document is licensed under the CC BY-SA 4.0 licence (https://creativecommons.org/licenses/by-sa/4.0/). © 2019-2025 Andrew J Instone-Cowie.

# Documentation Map

Figure 1 – Documentation Map

# About This Guide

The Type 2 Liverpool Ringing Simulator allows sensors, attached to one or more real tower bells or teaching dumb bells, to be connected to a computer Simulator Software Package such as Abel[^2], Beltower[^3] or Virtual Belfry[^4]. This allows you to extend and augment the teaching and practice opportunities in your tower.

This Technical Reference Guide contains background information on the design of the simulator hardware and firmware, and other reference material which may be useful.

Configuration guides for the main Simulator Software Packages are available separately, as are the detailed Build & Installation Guide and Multi-PC Guide.

Please note that this is a Build-it-Yourself project. No pre-built hardware is available.

# Typical Type 2 Simulator Installations

## Basic Configuration

The following diagram illustrates the general arrangement of a simulator installation using a sensor aggregation hardware interface like the Liverpool Ringing Simulator.

Multiple Sensor Modules in the belfry, one per bell, are connected to a Simulator Interface Module. A single data cable transmits the aggregated signals from the Simulator Interface Module to the Simulator PC in the ringing room. The same cable feeds power from a low voltage power supply in the ringing room, via a Power Module, back up to the Simulator Interface to power both Interface and Sensor Modules. The Type 2 simulator supports up to 16 sensors (only 12 shown on the diagram to save space).

In the ringing room, a PC runs a Simulator Software Package which interprets the received signals and turns them into the simulated sound of bells.

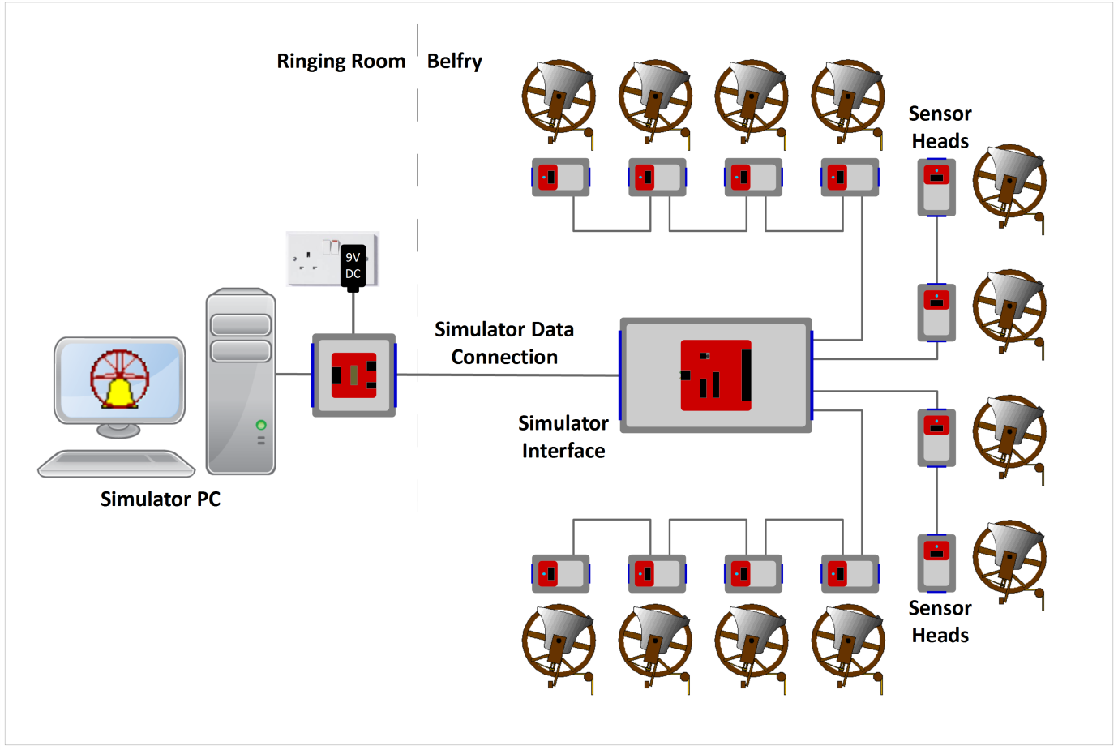
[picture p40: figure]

Figure 2 – Simulator General Arrangement

## Second PC Module

As an option, multiple Simulator PCs may be used concurrently, using either a Second PC Module, or the Basic Serial Splitter Module.

A second Simulator PC can be connected via a Second PC Module. This module utilises the second transmitter in the Simulator Interface MAX233 RS-232 serial line driver IC, and a spare core in the Power/Data cable, to provide a separate data feed to the Second PC.

A typical configuration with a Second PC Module is illustrated in the following diagram (only a subset of sensors are shown to save space):

Figure 3 – Second PC Module General Arrangement

## Basic Serial Splitter Module

The Basic Serial Splitter Module uses additional RS-232 receiver and line driver ICs to copy the stream of signals from the Simulator Interface to multiple PCs. The minimum configuration of the Basic Serial Splitter (the “Master Board”) supports up to four PCs, but this can be linked to a second “Expander Board” which supports four more PCs.

Two Basic Serial Splitter Modules can be daisy-chained between the Power Module and the Simulator Interface Module on RJ45 cables, supporting a maximum of 16 Simulator PCs. The maximum configuration of two daisy-chained Basic Serial Splitters is illustrated in the following diagram (all sensors are omitted to save space):

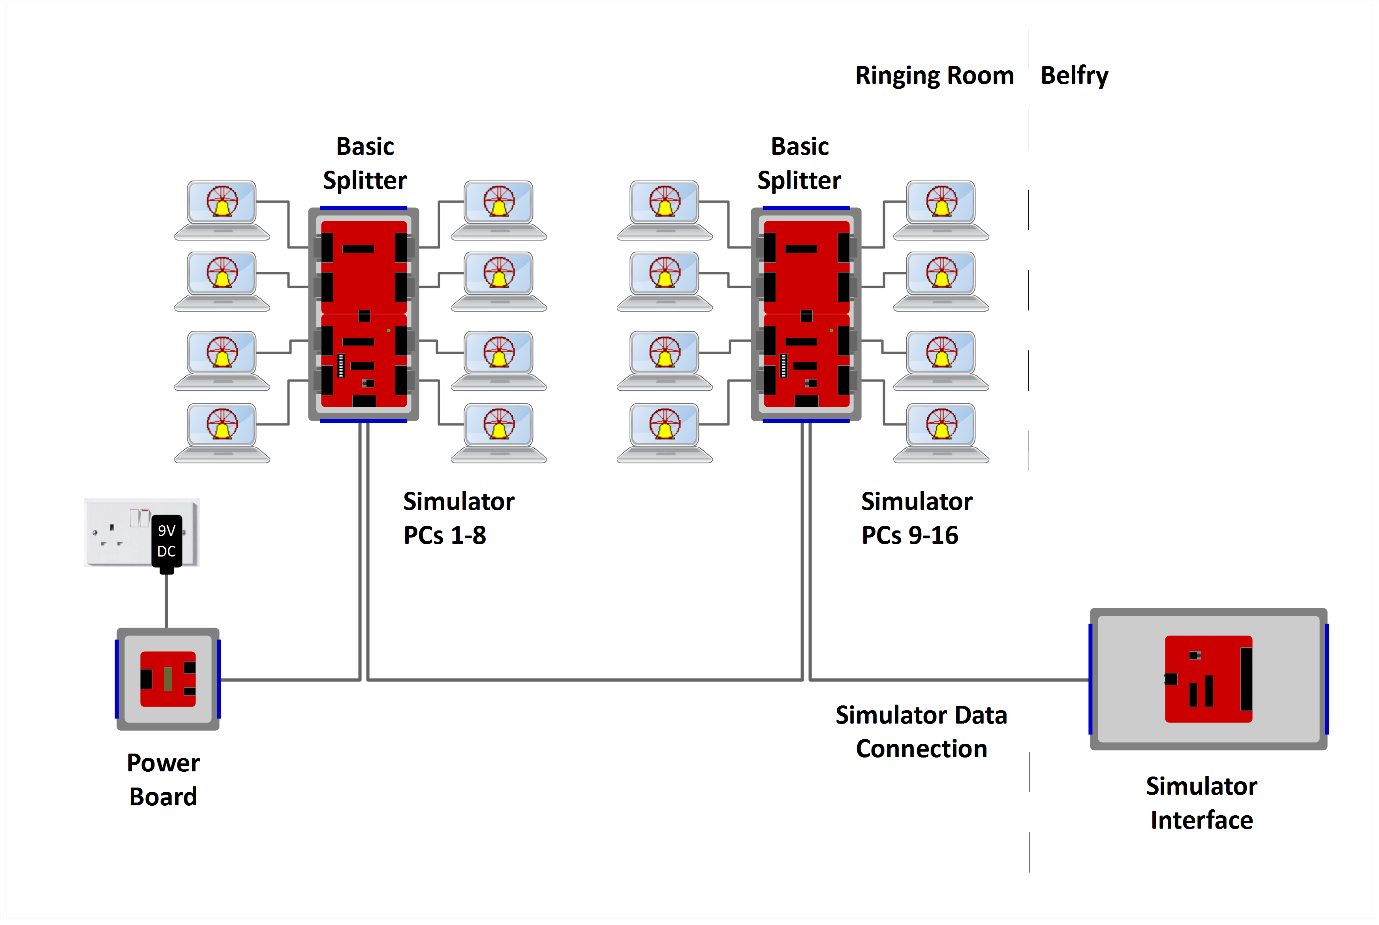
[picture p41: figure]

Figure 4 – Basic Serial Splitter Modules General Arrangement

All Simulator PCs receive a read-only copy of the same signals from the Simulator Interface. Each PC runs its own copy of the Simulator Software Package (or even of different software packages), and the Simulator Software on each PC is configured to filter out unwanted signals.

Any one PC connected to the Basic Serial Splitter can be used to send configuration data to the Simulator Interface, selectable by a switch on the splitter. (If two Basic Serial Splitters are daisy-chained together, only PCs connected to the Splitter nearest to the Power module can be used to configure the Interface.)

# Simulator Overview

## Bell Sensing Methods

### Sensor Types

Over the years a number of different approaches have been used for detecting the position of a tied or dumb bell, and translating that position into a signal for use by a simulator.

- Mechanical switches or contacts suffer from reliability problems, including mechanical fatigue and environmental damage (e.g. corrosion or ingress of dirt), and are not now widely used. Mechanical switches also typically suffer from a high degree of contact “bounce”.
- Electro-Magnetic sensors, typically consisting of a glass-encapsulated reed switch attached to the bell frame and a small magnet attached to the wheel shroud, have also been used, but typically require very close alignment of switch and magnet. They can also suffer from fatigue and contact bounce.
- Inductive sensors, which have a fixed detector circuit attached to the bell frame, and a wire coil fitted to the wheel shroud, have also been used. In principle the absence of moving parts should make these a very reliable option. However, a key component of the original design[^5] is no longer available, and parts for an alternative design[^6] are described as difficult to obtain.
- Aidan Hedley has produced a sensor design[^7] using a Honeywell magneto-resistive sensor, activated by a small, powerful rare earth magnet mounted on the wheel shroud. Alan Griffin and Derek Livsey produced a similar design using an Allegro Microsystems Hall Effect device. The standard magnetic sensor used by the Type 2 Liverpool Ringing Simulator is derived from these designs.
- A wireless, accelerometer-based sensor has been developed and prototyped as the Belfree simulator. This sensor is mounted on the wheel of the bell and communicates with the Simulator PC via a radio link. At the time of writing these not currently available[^8].
- Optical sensor heads using visible light typically consist of a light source, usually a fixed red Light Emitting Diode (LED), mounted parallel to a photo-diode or photo-transistor detector, in an enclosure attached to the bell frame; and a reflector mounted on the wheel shroud. Visible light optical sensors are widely used, are very reliable, and this is the approach adopted by the Bagley MBI sensor heads[^9]. Their use can be problematic in areas with high ambient light levels. Other designs include additional pulse-shaping or timing circuitry[^10].
- Optical sensor heads using infra-red light are similar in general design, but have reduced susceptibility to ambient visible light levels. A sensor design using a low cost commercially available modulating infra-red detector has been developed as an alternative sensor for the Type 2 Simulator.

## Single vs Dual Trigger

There are generally two approaches used by simulators when detecting signals from sensors:

- The dual trigger approach uses two triggers (for example, optical reflectors) on the shroud of the wheel of each bell, one of which triggers at the moment that the bell would strike at handstroke, the other at the moment that the bell would strike at backstroke.
- The single trigger approach uses one trigger, which triggers as the bell passes through the bottom dead centre (BDC) of its swing. A delay is then applied (either in the Simulator Interface or the Simulator Software Package) before the simulator triggers the simulated sound of the bell.

The Liverpool Ringing Simulator project adopts the single trigger approach, on the grounds of simplicity of installation and compatibility with other similar systems. This is discussed in more detail in a later section of this guide.

### Dual Triggers

The dual trigger approach uses two triggers (for example, optical reflectors or magnets) on the shroud of the wheel of each bell, one of which triggers at the moment that the bell would strike at handstroke, the other at the moment that the bell would strike at backstroke. The simulator triggers the simulated sound of the bell as soon as the signal pulse is received (from the trigger travelling past the sensor as the bell is on its way up to the balance), and then ignores the next signal pulse (as the first trigger travels back past the sensor as the bell is on its way down), and so on.

This approach is illustrated in the following diagrams. In Figure 5 the bell is rising towards the handstroke position, and is passing through the backstroke strike point. The backstroke trigger passes the sensor and generates a signal to the Simulator. Figure 6 shows the opposite stroke as the bell rises towards the backstroke position and passes through the handstroke strike point.

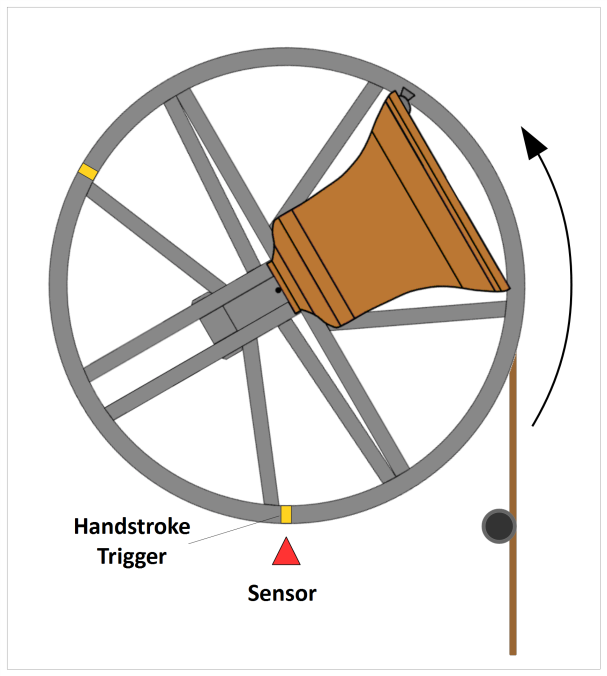
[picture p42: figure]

Figure 5 – Dual Triggers – Backstroke Strike Point | Figure 6 – Dual Triggers – Handstroke Strike Point

The sensor is shown at the BDC position only for clarity. The sensor may be located anywhere around the wheel, provided that the geometrical relationship between the sensor and the two triggers is maintained.

This approach has the capacity to provide a very accurate representation of the striking of a bell, but equally requires very accurate placement of the triggers to match the strike points of the bell in motion. This may be difficult and time-consuming to determine.

### Single Trigger

The single trigger approach uses one trigger, which triggers as the bell passes through the bottom dead centre (BDC) of its swing. A delay is then applied (either in the Simulator Interface or the Simulator Software Package) before the simulator triggers the simulated sound of the bell.

This approach is illustrated in the following diagrams. In Figure 7 the bell is rising towards the handstroke position. The trigger passed the sensor at BDC, and a delay is applied so that the signal to the Simulator is generated later, as the bell passes through the backstroke strike point. Figure 8 shows the opposite stroke as the bell rises towards the backstroke position and passes through the handstroke strike point.

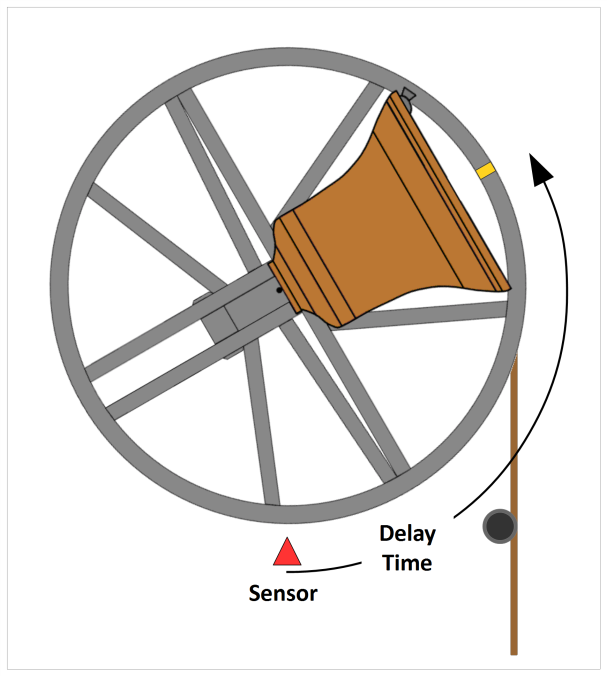
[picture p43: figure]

Figure 7 – Single Trigger – Backstroke Strike Point | Figure 8 – Single Trigger – Handstroke Strike Point

The sensor is again shown at BDC only for clarity. The sensor may be located anywhere around the wheel, provided that the geometrical relationship between the sensor and the trigger is maintained, the trigger being positioned directly opposite the sensor when the bell is down.

This approach is simpler to implement, and the single trigger is much easier to align accurately against the Sensor Head with the bell down. Work by John Norris[^11] has shown that this approach can provide an acceptable degree of accuracy, with any errors considered too small to be detectable to the human ear.

The Type 2 Liverpool Ringing Simulator adopts the single trigger approach, on the grounds of simplicity of installation, and compatibility with other similar systems.

# Simulator Interface Module Hardware

## Overview

The Simulator Interface Module hardware consists of three main functional blocks:

- A 5V regulated power supply, which provides power for the interface electronics and for the sensor.
- A digital microcontroller, which detects incoming signals from the sensors, and then sends aggregated signals to the Simulator PC in the form of a stream of ASCII characters.
- A RS-232 serial line driver, which converts the TTL-level signals from the microcontroller to higher voltage RS-232 signals, for transmission over longer distances to the Simulator PC.

All the components of these functional blocks are mounted on a single custom PCB. The same core hardware (and firmware) can connect to any number of Sensors Modules from one to 16.

## Hardware Options

Over recent years several low-cost electronic prototyping platforms have been brought to the market, with a number of different architectures, and suitable for a wide range of experimental and embedded functions. These include single board computers running feature-rich operating systems, such as the Raspberry Pi and Beagle Board, and simpler microcontroller-based products such as the Arduino family, PICAXE, ARM Cortex and others.

New devices and variants are released frequently.

The Arduino Uno development platform (based on the Microchip (formerly Atmel) ATmega328P microcontroller[^12]) was originally selected as the prototyping platform for the Liverpool Cathedral Simulator project, on the grounds of:

- Simplicity & low cost
- Established user base & wide community support
- Wide availability of additional prototyping peripheral hardware (“shields”)

The use of the same microcontroller family has been continued for the Type 2 Liverpool Ringing Simulator, allowing the same well-supported and freely available tool chain to be used for code development and deployment.

## Hardware Interrupts

The choice of the ATmega328P imposes an important constraint on the firmware design for the Simulator Interface, in that the microcontroller has limited support for hardware interrupt inputs. This is described in more detail in a later section of this guide.

## Microcontroller Hardware

The Simulator Interface is based on the same Microchip (formerly Atmel) ATmega328P microcontroller as the Arduino Uno used in the first prototype interfaces. Using the same microcontroller makes it very easy to port the Simulator Interface firmware to the new hardware.

- The Simulator Interface[^13] makes use of an external 8MHz resonator as a clock source. Although this is less accurate than a crystal oscillator, it is still adequate for the purposes of the Simulator Interface, and this reduces the overall component count and complexity of the interface board by omitting crystal load capacitors.
- Although the Simulator Interface uses the ATmega328P microcontroller and development tool chain, it does not use the Arduino boot loader program. The ATmega328P is programmed via an ICSP header using a programmer (the Arduino-as-ISP method is suggested and is described in more detail in the Build & Installation Guide.)

## Serial Line Driver

- The Simulator Interface uses the Analog Devices (formerly Maxim) MAX233 RS-232 serial line driver[^14]. The MAX233 has the advantage over other line driver ICs of requiring no external charge pump capacitors, also reducing the overall component count. It also provides two RS-232 transmitters, simplifying support for multiple Simulator PCs.

## Microcontroller Configuration

### Microcontroller I/O Pins

The following table shows the ATmega328P pin assignments for the Type 2 Simulator Interface:

Table 1 – Microcontroller I/O Pin Assignments

Arduino I/O Pin[^15] | ATmega328P Physical Pin | Function
0 | 2 | Serial Port Receive
1 | 3 | Serial Port Transmit
2 | 4 | Sensor #12 (T)
3 | 5 | Sensor #10 (0)
4 | 6 | Diagnostic LED
5 | 11 | CRO Timing Pin (enabled in development code only)
6 | 12 | Sensor #1
7 | 13 | Sensor #2
8 | 14 | Sensor #3
9 | 15 | Sensor #4
10 | 16 | Sensor #5
11 | 17 | Sensor #6
12 | 18 | Sensor #7
13 | 19 | Sensor #8
14 (A0) | 23 | Sensor #9
15 (A1) | 24 | Sensor #11 (E)
16 (A2) | 25 | Sensor #13 (A)
17 (A3) | 26 | Sensor #14 (B)
18 (A4) | 27 | Sensor #15 (C)
19 (A5) | 28 | Sensor #16 (D)

### Microcontroller Fuse Settings

The ATmega328P microcontroller has several configuration registers known as fuses. These are used to control the behaviour of the microcontroller[^16]. Fuse values are contained in the file boards.txt described in the section on uploading firmware below, and are only written during the burn bootloader phase of programming.

Warning: Setting incorrect fuse values can render the microcontroller unusable or prevent further reprogramming without specialist hardware.

The appropriate set of fuses is selected in the Arduino IDE by selecting the correct board type in the Liverpool Ringing Simulator Boards set.

Table 2 – ATmega328P Fuse Settings – Board Rev A to D

Fuse | Value | Notes
Low | 0xE2 | 8MHz internal oscillator, maximum clock startup delay. (SUT0, CKSEL3, CKSEL2, CKSEL0)
High | 0XDF | Enable serial programming, boot reset vector disabled. (SPIEN)
Extended | 0xFD | Brown-out detection level 1 (2.7V). (BODLEVEL1)

For more details of these fuse settings and their functions, refer to the ATmega328P data sheet, or see the online fuse calculator at: https://eleccelerator.com/fusecalc/fusecalc.php?chip=atmega328p&LOW=E2&HIGH=DF&EXTENDED=FD.

Table 3 – ATmega328P Fuse Settings – Board Rev E onwards

Fuse | Value | Notes
Low | 0xCF | 8MHz external resonator, maximum clock startup delay. (SUT0, SUT1)
High | 0XDF | Enable serial programming, boot reset vector disabled. (SPIEN)
Extended | 0xFD | Brown-out detection level 1 (2.7V). (BODLEVEL1)

For more details of these fuse settings and their functions, refer to the ATmega328P data sheet, or see the online fuse calculator at: https://eleccelerator.com/fusecalc/fusecalc.php?chip=atmega328p&LOW=CF&HIGH=DF&EXTENDED=FD.

Note that unlike the Type 1 Simulator Interface, EEPROM contents are cleared on firmware load (high fuse bit 3, EESAVE, is not set, giving 0xDF instead of 0xD7). This is to be confident of having a workable default configuration even if the interface has not yet been configured by the user.

## Power Supply

DC power is supplied to the Simulator Interface over the Power/Data Cable at a higher voltage than required, to overcome the effects of losses due to the resistance of the Power/Data Cable. Incoming power is fed to a conventional linear 5V regulator on the Simulator Interface PCB. An alternative to a conventional linear regulator is described in the Build & Installation Guide, for installations with higher current requirements.

### Typical Current Requirements

The Simulator Interface Module and Sensor Modules all operate at 5V DC.

- The Simulator Interface current consumption is approximately 25mA.
- The current consumption of the standard Magnetic Sensor Modules is approximately 8mA per module in the triggered state (i.e. with the LED lit).
- The current consumption of the Infra-Red Sensor Modules is approximately 25mA per module in the triggered state.
- The total current requirement with a full set of 16 Magnetic Sensor Modules is therefore approximately 153mA.
- The total current requirement with a full set of 16 Infra-Red Sensor Modules is approximately 425mA.

These values are well below the 1A maximum current rating of the specified 5V voltage regulator, however heatsinking may be required for configurations with many Infra-Red Sensor Modules, as noted below.

### Microcontroller Package Ratings

The ATmega328P microcontroller has a source/sink current limit of 40mA per pin, and a total device package current limit of 200mA. The majority of the microcontroller pins will be connected to sensor inputs, and these were measured to sink approximately 130 μA each when triggered, so neither of the microcontroller limits should present a problem. Other pins drive the diagnostic LED and the RS-232 line driver, and in total these do not draw more than a few milliamps.

### Voltage Regulator

The Simulator Interface uses a standard linear voltage regulator to provide a regulated 5V DC supply. The voltage regulator requires at least 7V DC at its input pin in order to maintain a stable 5V DC output. The voltage regulator is fed via a polarity protection diode, which drops approximately 0.7V, giving a minimum input voltage requirement of 7.7V at the Simulator Interface input.

### Cable Voltage Drop

CAT5 Ethernet cable is specified[^17] as having a DC loop resistance of <0.188 Ω/m.

The effective resistance of the power cores of a 25m cable (considering that the simulator configuration doubles up both power and ground cores) is therefore estimated to be approximately 2.35Ω. At a peak supply current of 425mA, this would result in a voltage drop of approximately 1V along the 25m cable.

Taking into account the voltage drop across the polarity protection diode, the theoretical minimum supply voltage to the cable is approximately 8.7V in order for the voltage regulator to maintain a stable 5V DC output. In practice a multi-voltage DC plug-in power supply unit rated at 1000mA with the output set to 9V has been found adequate for a cable run up to 25m.

For exceptionally long cable runs a 12V DC supply could be used, but there is no advantage to doing so for shorter runs, and the heat dissipation of the voltage regulator will increase, with a requirement for additional heatsinking.

### Heat Dissipation

At peak load, with a full complement of 16 Infra-Red Sensor Modules, the voltage regulator would be dissipating a minimum[^18] of approximately 0.85W. The power dissipation will be higher with shorter cable runs or a higher supply voltage. The data sheet for the voltage regulator indicates that this will require a heatsink.

An alternative approach, described in the Build & Installation Guide, is to replace the linear voltage regulator with a switched buck regulator. These are available as drop-in replacements for the standard TO-220 regulator package and eliminate the need for a heatsink altogether.

## Hardware Compatibility

The Type 2 Liverpool Ringing Simulator has been designed to be compatible, as far as possible, with existing simulator hardware, to allow operation with unmodified Simulator Software Packages which support the MBI protocol. This is described in more detail in later section of this guide. The following hardware design decisions have been made to maximise compatibility and interoperability:

- The Simulator Data Connection uses a RS-232 data link to the Simulator, running at 2400 bps, 8 data bits, 1 stop bit, no parity.
- The sensor inputs of the Simulator Interface operate at 5V DC TTL levels. Under normal (un-triggered) conditions the interface expects that the Sensor Head output pin will be HIGH (nominally +5V), and that when triggered the Sensor Head output pin will drop LOW (nominally 0V) for the duration of the trigger pulse[^19].

Unlike the Type 1 design, the simplified cabling used by the Type 2 Simulator Interface means that the sensor inputs do not use the same 4-pin GX16-4 panel mount connectors as the Bagley MBI. Integrating existing sensors into the Type 2 Simulator may be achieved using the Generic Sensor module described in the Build & Installation Guide.

# Basic Serial Splitter Module Hardware

## Overview

The Basic Serial Splitter Module replicates data sent from the Simulator Interface Module (“downstream data”) to up to 8 Simulator PCs. All PCs receive copies of the same data, simultaneously. For example, typically this allows more than one ringer with headphones to use the simulator with a simulated band at the same time, the Simulator Software Package on each ringer’s PC responding only to the Sensor on “their” tower bell.

The Basic Serial Splitter Module also allows any one Simulator PC to send data to the Simulator Interface Module (“upstream data”) for configuration purposes. The active Simulator PC is selected using a DIP switch on the Basic Serial Splitter Module.

Finally, it is possible to daisy-chain two Basic Serial Splitters to allow the connection of up to 16 Simulator PCs. When two Basic Serial Splitters are daisy-chained together, only PCs on the more downstream Splitter Module can be used to send configuration data to the Simulator Interface Module.

The Basic Serial Splitter Module is a passive device and has no microcontroller or firmware.

## Serial Line Drivers

The Basic Serial Splitter uses two different Serial Line Driver ICs. Data to and from the upstream Simulator Interface Module is handled by an Analog Devices (formerly Maxim) MAX3323, and data to and from the Simulator PCs is handled by an Analog Devices (formerly Maxim) MAX208.

- The MAX3323 has been selected to handle the interface data because it can disable its transmitter and receiver in response to additional control pins (only the ability to disable the transmitter is used in the Basic Serial Splitter Module), and because its receiver has the capacity to fan out to multiple transmitters (calculation below).
- The MAX208 consists of 4 pairs of RS-232 transmitters and receivers in a single package. It can therefore handle signals to and from up to 4 PCs per IC. Note that no RS-232 control lines are connected. A second MAX208 on the expander board supports a further 4 PCs.

## PCB Design

The Basic Serial Splitter Module has been designed such that a common PCB can be assembled either as a Master Board with connections to the Simulator Interface Module, Power Module, and up to 4 PCs; or as an Expander Board, which connects to the Master Board and up 4 further PCs.

The Expander Board requires only a subset of the components normally fitted to a Master Board. This is detailed in the assembly instructions in the Multi-PC Guide.

## Power Supply

The Basic Serial Splitter derives its power from the Power Module, using the power lines looped through on the RJ45 connectors. Although the Basic Serial Splitter current requirements are very low, a large TO-220 voltage regulator is used to handle the additional heat dissipation if the installation requires a 12V supply instead of the usual 9V.

## Downstream Data

The downstream data flow is illustrated in the following diagram:

Figure 9 – Basic Serial Splitter Downstream Data Flow

Data from the Simulator Interface Module is received at RS-232 line levels by the receiver on the MAX3323, which inverts and level shifts it to TTL levels. The data is then fanned out to up to 8 MAX208 transmitters, which invert and level shift it back to RS-232 line levels for the connected Simulator PCs.

### Fan-Out Calculation

The MAX3323 can operate on supply voltages between 3.0V and 5.5V. In the Basic Serial Splitter Module design the supply voltage VCC is nominally 5.0V, and the VL logic supply pin is tied to VCC.

The choice of VCC = 5.0V is driven by the MAX208, which requires a supply voltage of 5.0V.

MAX3323 RS-232 receiver output specification:

Output Voltage Low VOL:

- IOUT = 1.6mA, VL > 1.8V, guarantees VOL < 0.4V
- IOUT = 1mA, VL ≤ 1.8V, guarantees VOL < 0.4V
- Hence at VL = VCC = 5.0V, the receiver output can sink up to 1.6mA while maintaining VOL below 0.4V.

Output Voltage High VOH:

- IOUT = -1mA, VL > 1.8V, guarantees VOH > VL - 0.4V
- IOUT = -500µA, VL ≤ 1.8V, guarantees VOH > VL - 0.4V
- Hence at VL = VCC = 5.0V, the receiver output can source up to 1mA while maintaining VOH above 4.6V.

MAX208 RS-232 transmitter input specification:

Input Voltage Low:

- Input Logic Threshold Low < 0.8V
- Input internal pull-up resistor = 400kΩ
- Input current therefore approximately 12.5μA per transmitter with transmitter input held low.
- One MAX3323 receiver will drive 8 x MAX208 transmitters in a fully populated Basic Serial Splitter Module (master board + expander board).
- 12.5μA x 8 transmitters = 100μA
- 100μA is less than the maximum 1.6mA which the MAX3323E receiver output can sink.
- Hence one MAX3323 RS-232 receiver can maintain VOL < 0.4V, which is less than the 0.8V MAX208 RS-232 transmitter logic low threshold, while driving the required 8 x MAX208 RS-232 transmitters.

Input Voltage High:

- Input Logic Threshold High > 2.0V
- The MAX208 transmitter input pull-up resistor ensures logic high even if the input is open circuit. No external current source is required.
- Hence one MAX3323 RS-232 receiver output can maintain VOH >4.6V, which is greater than the 2.0V MAX208 RS-232 transmitter logic high threshold, while driving the required 8 x MAX208 RS-232 transmitters.

## Upstream Data

The upstream data flow is illustrated in the following diagram:

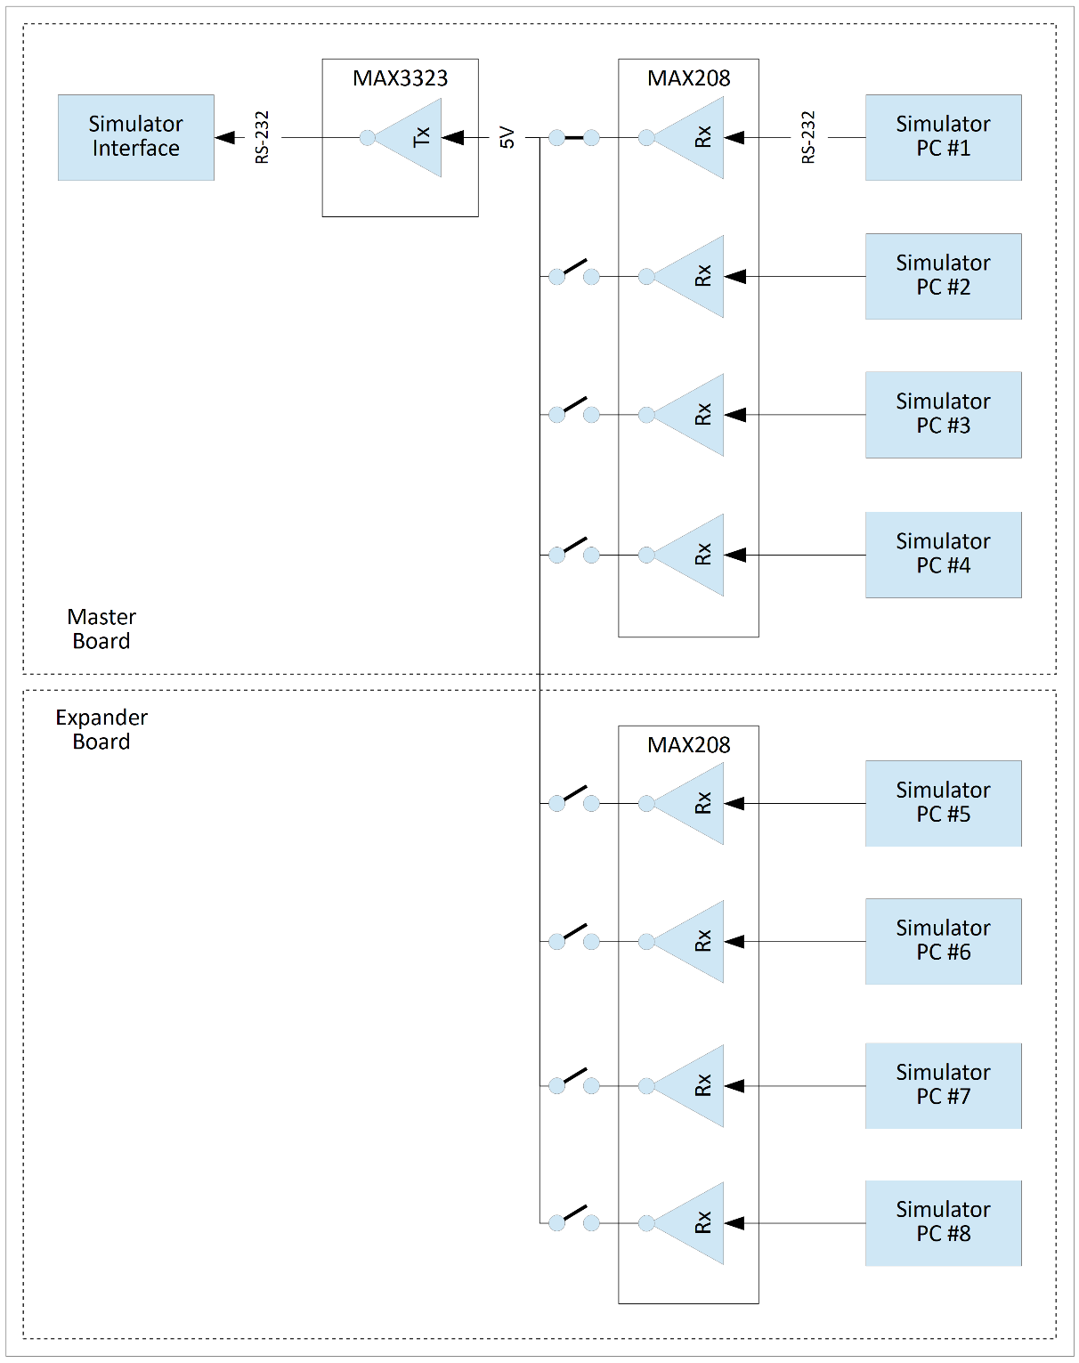
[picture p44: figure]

Figure 10 – Basic Serial Splitter Upstream Data Flow

Data from a Simulator PC is received at RS-232 line levels by a receiver on a MAX208, which inverts and level shifts it to TTL levels. The data from one PC (Simulator PC #1 in the diagram above) is then connected via the DIP switch to the MAX3323 transmitter, which inverts and level shifts it back to RS-232 line levels for the Simulator Interface Module.

It is important to note that only one MAX208 receiver should be connected at any time to the MAX3323 transmitter.

- The MAX208 ensures that the outputs of any receivers not connected to an RS-232 source are held at logic 1 level (logic 1 is high voltage – approximately VCC – on the TTL side).
- Connecting more than one receiver at the same time will result in an effective short circuit from VCC to ground during any data transmission from a connected PC, as the other receiver tries to pull its output low. This may damage the MAX208.

### Transmitter Disabling

Two Basic Serial Splitter Modules may be daisy-chained to support a maximum of 16 Simulator PCs.

- Where a single Basic Serial Splitter Module is used, only one Simulator PC can be used to send configuration data to the Simulator Interface Module. The active PC is selected using the 8-position DIP switch on the Basic Serial Splitter Module.
- Where two Basic Serial Splitter Modules are daisy-chained together, only one module can be used to send configuration data to the Simulator Interface Module (the active PC on that module being selected with the DIP switch, as above).
- Only the RS-232 transmitter on the downstream of the two modules is enabled; the transmitter on the upstream module is disabled.
- The disabling of the upstream transmitter is automatic and cannot be configured.

The circuit controlling the transmitter disabling function is illustrated in the following diagram:

Figure 11 – Basic Serial Splitter Transmitter Control

The transmitter disabling function operates as follows:

- The Basic Serial Splitter Modules uses the MAX3323 RS-232 serial line driver IC, which has the capability to disable the serial transmitter via a control pin, making the RS-232 level transmit T1OUT[^20] pin passive and high impedance[^21].
- When a single Basic Serial Splitter Module is used, the TXENABLE pin is held high via a 10kΩ pull-up resistor.
- The TXENABLE pin is also connected to pin 8 of the Power Board connector. This is pin is not connected on the Power Module, so the TXENABLE pin is still held high. This enables the RS-232 transmitter.
- Pin 8 on the Interface connector is connected to ground (0V). This pin is not used on the Simulator Interface Module, so this has no effect.
- When a second Basic Serial Splitter is connected, pin 8 on the Power Board connector of the upstream module is connected to the Interface connector of the downstream interface. This has the effect of pulling low the TXENABLE pin of the upstream module’s MAX3323.
- This disables the upstream MAX3323’s RS-232 transmitter and makes the T1OUT transmit pin high impedance. PCs connected to the upstream module cannot transmit data to the Simulator Interface Module, regardless of the DIP switch setting.
- The TXENABLE pin of the downstream module’s MAX3323 is still held high by its pull-up resistor. As above, this pin is connected to pin 8 of the Power Board connector, but this is not connected on the Power Module, so the TXENABLE pin is still held high. The downstream module’s RS-232 transmitter remains enabled.

# Circuit Protection

## Over-Current Protection

Primary over-current protection is provided by the 800mA fuse fitted to the Power Module.

Secondary over-current protection is provided by the selected LM340T-5.0 voltage regulator[^22] or alternative Traco Power TSR 1-2450 switched buck regulator[^23]. Both devices have internal short-circuit protection and thermal shutdown features.

The LM340T-5.0 has internal thermal overload protection, and an internal short-circuit current limit of 2.1A.

The short-circuit current limit of the Traco Power TSR 1-2450 is not specified in the data sheet, but the maximum input current is given as 1000mA (1A).

## Polarity Protection

The use of polarised connectors on all modules of the Liverpool Ringing Simulator minimises the possibilities for reversed polarity connections between modules. However, many general-purpose plug-in power supply units are provided with a selection of non-polarised reversible connector tips, with the consequent risk of inadvertently connecting the power supply with the polarity reversed.

The Simulator Interface Module and the Basic Serial Splitter Module are therefore provided with a reverse polarity protection diode, connected before the voltage regulator or other polarity sensitive devices.

The diode specified is a 1N4001 device[^24], which has a maximum peak forward current rating of 1A, and a peak inverse voltage rating of 50V, which is adequate for a fully specified simulator.

With correct power supply polarity, the diode is forward biased and conducts, allowing current to flow to the rest of the Interface or Splitter Module. This is illustrated in the following diagram:

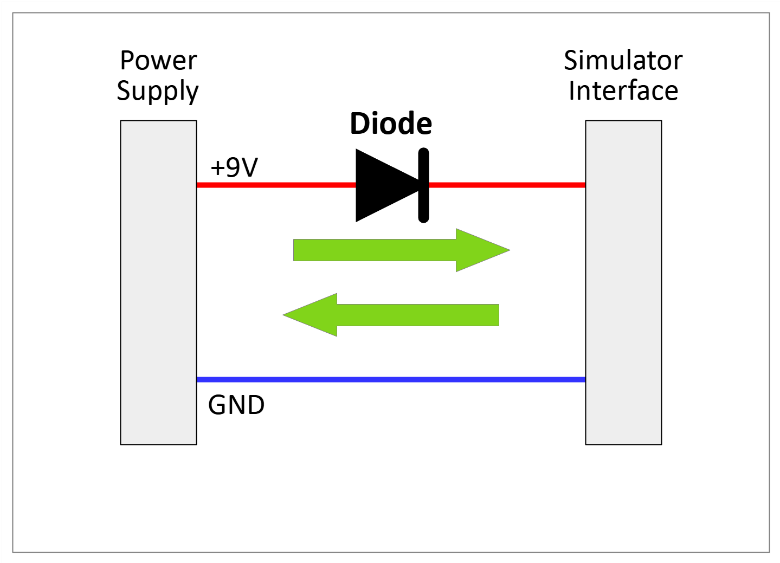
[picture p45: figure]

Figure 12 – Polarity Protection – Correct

If the power supply is connected with the polarity reversed, the diode is reverse biased and does not allow current to flow, thus protecting the remainder of the electronics. The peak inverse voltage rating of the diode provides protection up to 50V. Reverse polarity connection is illustrated in the following diagram:

Figure 13 – Polarity Protection – Reversed

## Transient Voltage Suppression

The Liverpool Ringing Simulator modules are fitted with Transient Voltage Suppression (TVS) diodes to provide a degree of protection against induced over-voltage spikes on the power supply and signal lines, for example resulting from local lightning strikes or electrostatic discharge events.

Uni-directional TVS diodes are used on logic and power supply lines. Bi-directional TVS diodes are used on the RS-232 signal lines.

The key properties of the diodes specified are listed in the following table, taken from the device data sheet:[^25]

Table 4 – TVS Diode Key Properties

Part Number | Reverse Standoff Voltage (VR) | Breakdown Voltage (VBR) | Maximum Clamping Voltage (VC) | Maximum Peak Pulse Current (IPP) (A) | Maximum Reverse Leakage Current (IR @ VR) (µA)
SA5.0A | 5.0 | 6.40 – 7.00 | 9.2 | 55.4 | 600
SA12A | 12.0 | 13.30 – 14.70 | 19.9 | 25.6 | 1
SA15CA* | 15.0 | 16.70 – 18.50 | 24.4 | 20.9 | 1

(* Bi-directional)

TVS diodes will not provide protection against direct lightning strikes. Disconnecting the Simulator Interface cable from the Power Module is recommended when the simulator is not in use.

The differences between the behaviour of uni-directional and bi-directional TVS diodes can be seen in the following graphs:[^26]

Figure 14 – TVS Diode Characteristic Curves

When reverse biased up to its Reverse Standoff Voltage, a uni-directional TVS diode does not conduct (apart from the Reverse Leakage Current discussed further below). As the reverse voltage reaches and exceeds the Breakdown Voltage, the diode starts to conduct, restricting the further increase in applied voltage, until the Maximum Peak Pulse Current is reached, at which point the voltage is effectively clamped at the Clamping Voltage.

When forward biased, a uni-directional TVS diode behaves much like a conventional rectifier diode and starts conducting with a very small forward voltage drop.

A bi-directional TVS diode is effectively two diodes connected anode-to-anode. It therefore always behaves as though it is reverse biased.

Note that the quoted values are not continuous ratings. TVS diodes are designed to absorb large amounts of power during sub-millisecond spikes.

### Uni-Directional TVS Diodes

12V Reverse Standoff Voltage uni-directional TVS diodes are fitted across the incoming unregulated power supply rails of the following modules:

- Power Module
- 2nd PC Module
- Basic Serial Splitter Module

5V Reverse Standoff Voltage uni-directional TVS diodes are fitted across the 5V regulated power rails of the Simulator Interface Module and the Sensor Modules, and between the 5V signal line and ground on the Sensor Modules.

The uni-directional TVS diodes operate as follows: On power supply rails, the power rail is always expected to be positive relative to ground rail; between +9V and +12V for the unregulated supplies, and +5V for the regulated supplies.

On data signal lines, the signal line is expected to be at +5V or 0V relative to the ground rail.

The TVS diode is connected as shown in the following diagram and is therefore normally reverse biased at up to[^27] its rated Reverse Standoff Voltage, and no current flows through the diode:

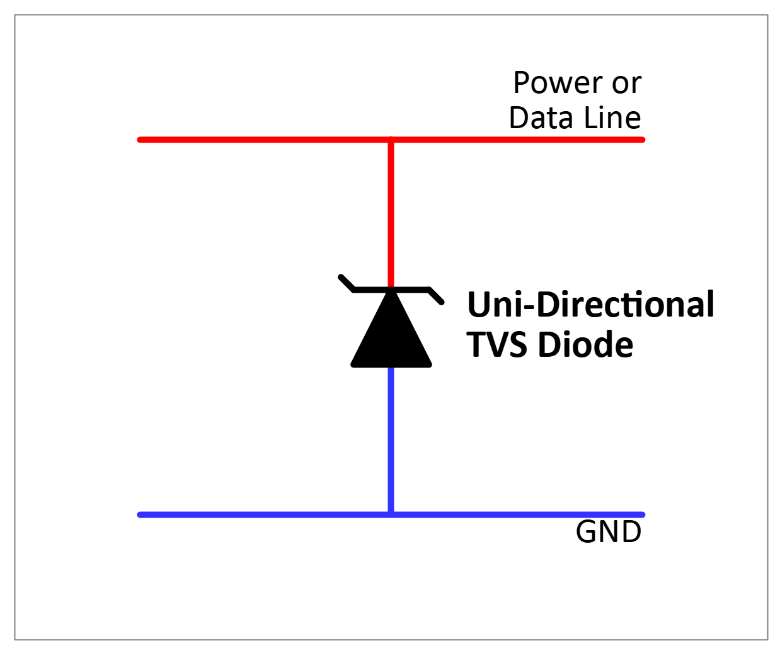
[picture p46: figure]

Figure 15 – Uni-Directional TVS Diode

If a transient voltage event causes the power or signal line voltage to spike above Breakdown Voltage of the TVS diode, the diode starts to conduct, holding the rail down to the Clamping Voltage and dissipating the power of the spike. This is illustrated in the following diagram:

Figure 16 – Spike Dissipation (Uni-Directional)

If a transient voltage event causes the voltage of the ground rail to rise above that of the power rail or signal line, the diode is forward biased and starts to conduct, clamping the two lines together and dissipating the power of the spike.

### Bi-Directional TVS Diodes

15V Reverse Standoff Voltage bi-directional TVS diodes are fitted between the RS-232 data lines and ground in the following modules:

- Power Module
- 2nd PC Module
- Basic Serial Splitter Module

RS-232 data lines may operate in the range +15V to -15V relative to the ground rail[^28], but the typical voltage swing achieved by the line drivers used in the Liverpool Ringing Simulator is ±8V (MAX233, MAX208) or ±5.4V (MAX3323). These are still within the limits of the RS-232 specification, which deliberately allows for wide ranges.

Because the RS-232 data lines swing both positive and negative relative to ground, uni-directional TVS diodes cannot be used, and bi-directional TVS diodes are required.

The bi-directional TVS diodes operate as follows: Regardless of whether the RS-232 data line is currently positive or negative relative to the ground rail, the TVS diode is always effectively reverse biased at up to its rated Reverse Standoff Voltage, and no current flows through the diode:

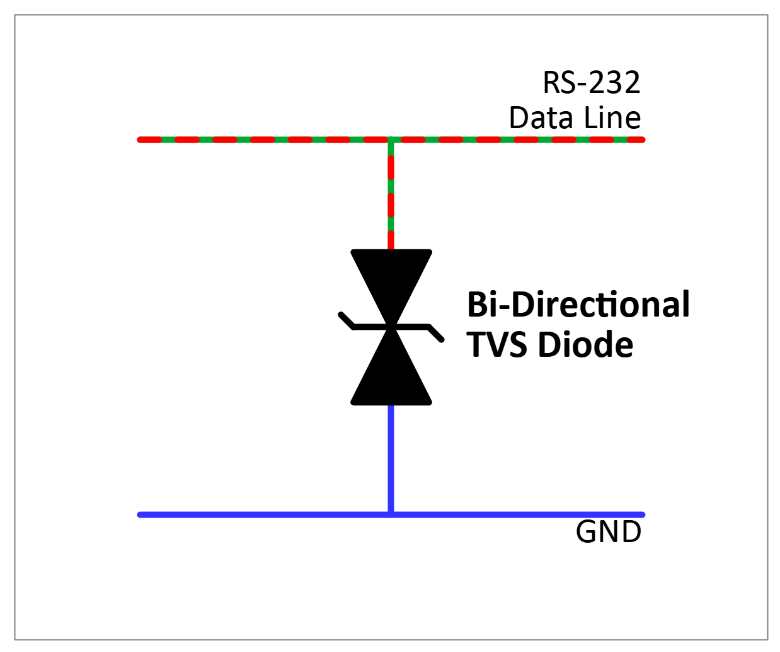
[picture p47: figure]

Figure 17 – Bi-Directional TVS Diode

If a transient voltage event causes the RS-232 data line spike outside the Breakdown Voltage of the TVS diode (so above +15V, or below -15V), the diode starts to conduct, holding the rail down to the Clamping Voltage and dissipating the power of the spike. The direction in which the diode conducts depends on the polarity of the spike. This is illustrated in the following diagram:

Figure 18 – Spike Dissipation (Bi-Directional)

### Leakage Current Issues

As noted above, the TVS diodes pass a Reverse Leakage Current when reverse biased, and for lower voltage diodes this can be substantial. The SA5.0A diode has a leakage current up to 600µA at 5V, and this can cause problems with microcontroller inputs.

Most sensors have “open-collector” outputs. When the sensor is triggered, a transistor inside the sensor turns on and connects the output pin to the ground rail, pulling it low. When the sensor is not triggered, the transistor turns off and the output pin “floats”. A pull-up resistor is required to pull the pin high.

The ATmega328P microcontroller requires an input pin to reach approximately 3V (VIH Min) to be considered “high”, and has weak internal pull-up resistors which can be activated in code to pull floating input pins high[^29]. The value of these resistors is not formally specified but is estimated to be in the range 20kΩ – 50kΩ, and may vary between devices.

As well as being pulled high by the microcontroller internal pull-up resistor, the sensor output pin is also connected the ground rail via a TVS diode. Reverse biased, the diode behaves like a resistor, and the weak internal pull-up resistor and the TVS diode “resistor” form a simple voltage divider which can be enough to hold the untriggered pin below the 3V required for it to be registered as high by the microcontroller.

This is illustrated in the following schematic:

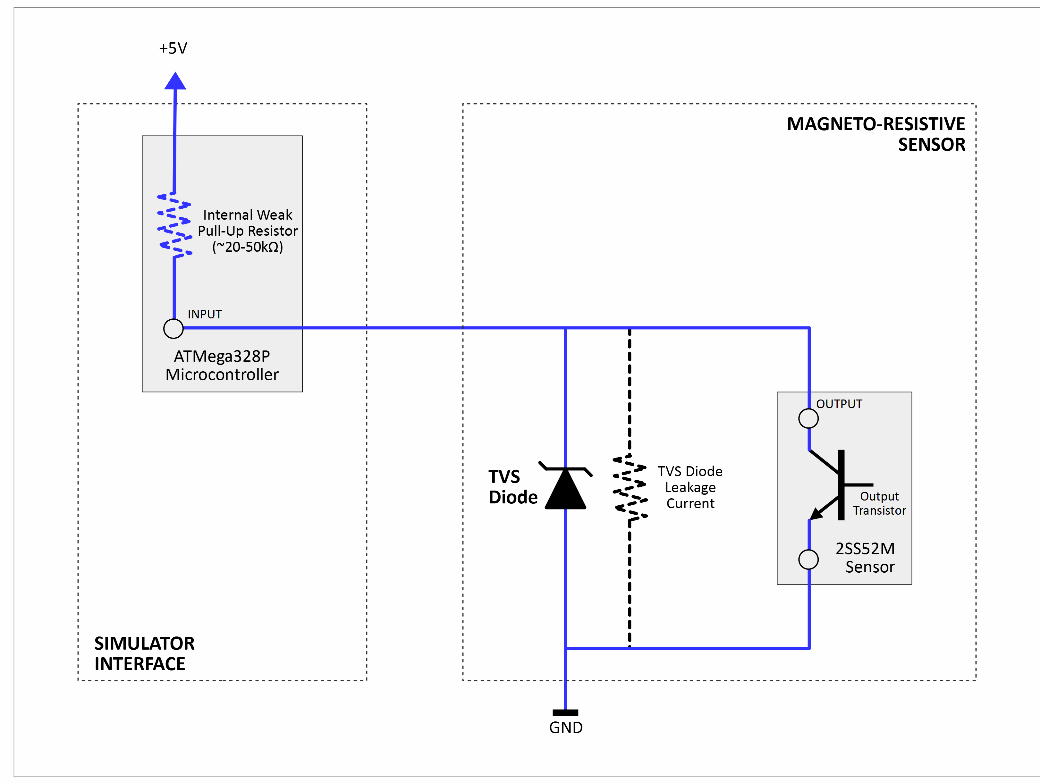
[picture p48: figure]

Figure 19 – Leakage Current "Voltage Divider" Effect

To counteract this, the Sensor Modules are also fitted with a supplementary “helper” 10kΩ pull-up resistor, as shows in the following diagram. A value of 10kΩ has been found adequate with the sensors used, but if found necessary the value of this resistor could be reduced further to 4.7kΩ.

Figure 20 – Leakage Current – Supplementary Pull-Up Resistor

# Connector Pin-Outs

## Multiple Device Conventions

The following conventions are used by the Power/Data connections between the Simulator Interface Module and any downstream devices (such as the Power Module or Multi-PC Modules, where these are used).

- Data is transmitted by the Simulator Interface Module downstream on pin 2, and from board Rev D, also on pin 6, using the second RS-232 transmitter in the MAX233.
- Upstream configuration data is received from the (or a) Simulator PC on pin 4.
- Power pins are doubled up to mitigate the effects of voltage drop in longer cable runs. Pins 5 and 7 are used for the nominal +9V supply to the devices, and pins 1 and 3 are 0V.
- Any downstream device connected to a Simulator Interface should expect to find and to use incoming serial data on pin 2 of the RJ45 Interface connector.
- Any downstream device connected to a Simulator Interface should assume that there may also be incoming serial data on pin 6 of the RJ45 Interface connector[^30], and should loop pin 6 to pin 2 on any downstream connector[^31].
- Any downstream device which does not require to send data to an upstream Simulator Interface should loop pin 4 of the RJ45 Interface connector to pin 4 on any downstream connector[^32].
- Any downstream device which requires to send configuration data to an upstream Simulator Interface should do so on pin 4 of the RJ45 Interface connector. This pin should also be looped to pin 4 on any downstream connector.
- Where multiple devices have the potential to send configuration data to an upstream Simulator Interface concurrently, a device should ground pin 8 to assert their right to send on pin 4[^33].

## Sensor Module Connector

The Sensor Modules use RJ45 connectors for the downstream cabling connection towards the Simulator Interface, and upstream connections to other Sensor Modules in the same chain.

- Each Sensor Module presents its output signal on pin 8 of the downstream Interface connector. Each Sensor Module takes any upstream sensor signals appearing on pins 4, 6 and 8 of the Next Sensor connector, and loops them through to pins 2, 4 and 6 respectively of the Interface connector.
- Pin 2 of the Next Sensor connector is not used, and hence connecting more than four sensors in one chain is not possible.
- Power pins are doubled up to mitigate the effects of voltage drop in longer cable runs. Pins 5 and 7 are used for the +5V supply to sensors, and pins 1 and 3 are 0V. These pins are looped through between the Interface and Next Sensor connectors.

The wiring of the female PCB connector is shown in the following diagram:

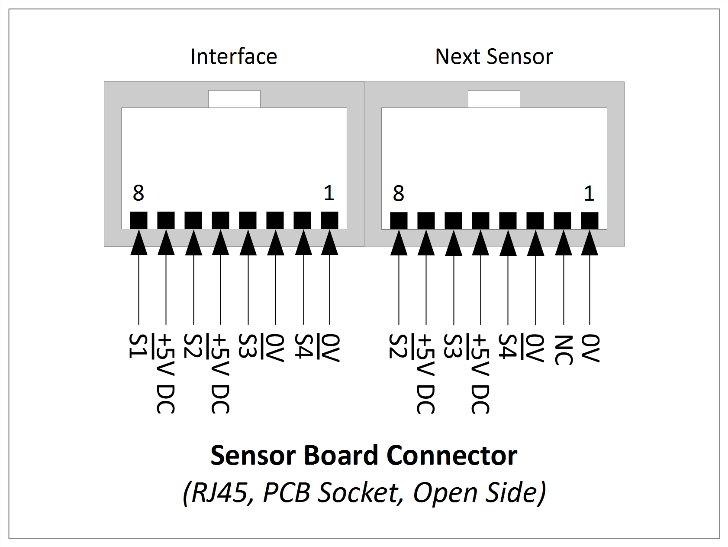
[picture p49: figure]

Figure 21 – Sensor Module Connector

The daisy-chain inter-connection of the sensors is illustrated in the following diagram:

Figure 22 – Sensor Chain Inter-Connection

## Simulator Interface Module Sensor Connector

The Simulator Interface Module uses RJ45 connectors for the upstream cabling connection to the Sensor Modules. A 4-gang connector is used, allowing the connection of up to 16 sensors.

The wiring of each female PCB connector is shown in the following diagram:

Figure 23 – Simulator Interface Module Sensor Connector

The layout of the 4-gang RJ45 PCB connector is shown in the following diagram:

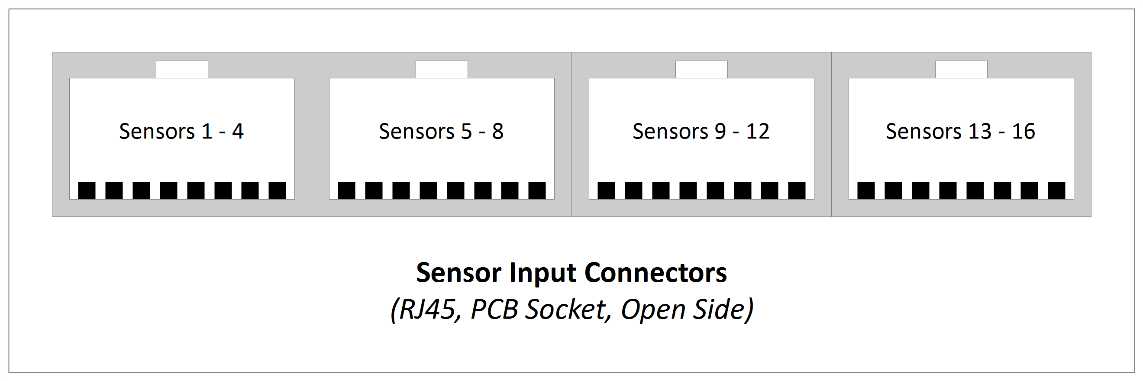
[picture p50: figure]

Figure 24 – Simulator Interface 4-Gang Connector

## Simulator Interface Module Power/Data Connector

The Simulator Interface Module uses an RJ45 connector for the downstream cabling connection to the Power Module (or Multi-PC Modules, where these are used).

- Data is transmitted downstream towards the Power Module on pin 2 (and from board Rev D, also on pin 6, using the second RS-232 transmitter in the MAX233), and upstream configuration data is received from the Simulator PC on pin 4.
- Power pins are doubled up to mitigate the effects of voltage drop in longer cable runs. Pins 5 and 7 are used for the nominal +9V supply to the interface, and pins 1 and 3 are 0V.

The wiring of the female PCB connector is shown in the following diagram:

Figure 25 – Simulator Interface Module Power/Data Connector

## Power Module Power/Data Connector

The Power Module uses an RJ45 connector for the upstream cabling connection to the Simulator Interface Module (or Multi-PC Modules, where these are used).

- Data is received from the upstream Simulator Interface Module on pin 2, and upstream configuration data is sent to the interface on pin 4.
- In a basic single PC configuration, any data received on pin 6 is discarded. Pin 6 is connected only to a TVS surge protection diode.
- Power pins are doubled up to mitigate the effects of voltage drop in longer cable runs. Pins 5 and 7 are used for the nominal +9V supply to the interface, and pins 1 and 3 are 0V.
- Pin 8 is not connected. This is required for correct operation when the Basic Serial Splitter Module is used.

The wiring of the female PCB connector is shown in the following diagram:

Figure 26 – Power Module Power/Data Connector

## Second PC Module Connector

The Second PC Module uses RJ45 connectors for the upstream cabling connection to the Simulator Interface, and the downstream connection to the Power Module.

- Power pins 1, 3, 5 and 7, and the spare pin 8 are looped through from the Interface connector to the Power Board connector.
- Pin 4 is used to send data (marked RX – configuration data received from the point of view of the upstream interface module) and is also looped through; this pin is not connected to the 9-pin serial connector on the Second PC Module.
- Sensor data received on Pin 2 of the Interface connector (marked TX – sensor data transmitted from the point of view of the upstream interface module) is routed to the 9-pin serial connector on the Second PC Module.
- Sensor data received on Pin 6 of the Interface connector (marked TX2) is looped through to pin 2 of the Power Board connector.
- Connecting more than two Second PC modules is therefore not possible; only the two most upstream modules will receive data from the Simulator Interface Module.

The wiring of the female PCB connector is shown in the following diagram:

Figure 27 – Second PC Module Connector

## Basic Serial Splitter Module Connector

The Basic Serial Splitter Module uses RJ45 connectors for the upstream cabling connection to the Simulator Interface Module, and the downstream connection to the Power Module.

- Power pins 1, 3, 5 and 7 are looped through from the Interface connector to the Power Board connector.
- Pin 4 is used to send data (marked RX – configuration data received from the point of view of the upstream interface module) and is also looped through; where two Basic Serial Splitter Modules are daisy-chained, the RS-232 transmitter of the upstream splitter module is disabled. This mechanism is discussed in detail in a previous section.
- Sensor data received on Pin 2 of the Interface connector (marked TX – sensor data transmitted from the point of view of the upstream interface module) is routed to the PCs connected to the Basic Serial Splitter Module.
- Sensor data received on Pin 6 of the Interface connector (marked TX2) is looped through to pin 2 of the Power Board connector. This data may be used a second, downstream Basic Serial Splitter Module.
- Pin 8 on each connector is used to enable or disable the RS-232 transmitter of the upstream splitter module where more than one Basic Serial Splitter Module is used.
- Connecting more than two Basic Serial Splitter Modules is therefore not possible; only the two most upstream modules will receive data from the Simulator Interface Module, and the transmitters of all but the most downstream module will be disabled.

The wiring of the female PCB connector is shown in the following diagram:

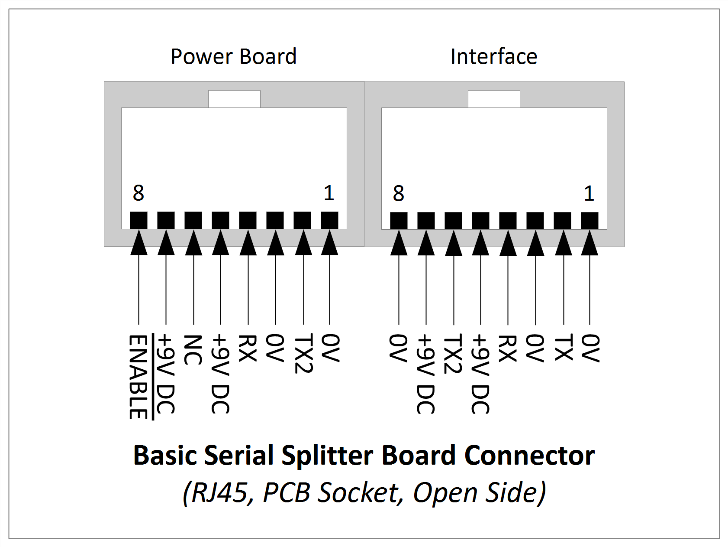
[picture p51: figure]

Figure 28 – Basic Serial Splitter Connector

## DB9 Serial Connectors

The Power Module, Second PC Module and Basic Serial Splitter Module all use standard 9-pin female sub-miniature D connectors (“DB9”) for serial data connections to attached Simulator PCs. The pin-outs of these connectors are illustrated below.

### DTEs & DCEs

In RS-232 communications, the description of connector pins as Transmit or Receive can be confusing. Devices can be configured as Data Terminal Equipment (DTE) or Data Communication Equipment (DCE). Traditionally, for example, a PC would be configured as a DTE, connected to a modem configured as a DCE.

By convention, a DTE has a male connector, a DCE has a female connector, and the DTE-to-DCE connection uses a female-to-male straight cable[^34]. A PC acting as DTE transmits data to the DCE from Pin 3 of the PC’s DB9 connector, which would be designated TD or TX; and receives data from the DCE on Pin 2, designated RD or RX[^35]. The DCE uses a female connector, receives data from the DTE on Pin 3, still designated as the “transmit” pin on the DCE, and sends data to the DTE on Pin 2, still designated as the “receive” pin on the DCE[^36].

The Simulator PC is a DTE. The Simulator Modules are fitted with female DB9 connectors and for simplicity are all wired for use with straight cables, so are technically DCEs and should by convention use DCE pin naming conventions.

However, to make the simulator module designs easier to follow, the schematics follow the transmit and receive pin designations used by the ATmega328P microcontroller UART, and the RS-232 sides of the Analog Devices (formerly Maxim) MAX233, MAX208 and MAX3323 line drivers. Following these conventions, the module pins used for transmitting sensor data from the Simulator Interface to the attached PC are marked TX, and the module pins used for receiving CLI data from the attached PC to the Simulator Interface are marked RX. This is the opposite of the usual convention for a DCE.

### Power Module

The Power Module uses a female DB9 connector for the downstream cabling connection to the Simulator PC.

- Pin 2 is used for simulator sensor data transmitted to the attached PC.
- Pin 3 is used for CLI data transmitted to the Simulator Interface from the attached PC.

The wiring of this connector is shown in the following diagram:

Figure 29 – Power Module DB9 Serial Connector

### Second PC Module

The Second PC Module uses a female DB9 connector for the downstream cabling connection to the Simulator PC.

- Pin 2 is used for simulator sensor data transmitted to the attached PC.
- Pin 3 is not connected. It is not possible to use the CLI from the PC attached to the Second PC Module.

The wiring of this connector is shown in the following diagram:

Figure 30 – Second PC Module DB9 Serial Connector

### Basic Serial Splitter Module

The Basic Serial Splitter Module uses female DB9 connectors for the downstream cabling connections to the Simulator PCs.

- Pin 2 is used for duplicated simulator sensor data transmitted to each attached PC.
- As noted previously in the section on Transmitter Disabling in the Basic Serial Splitter Hardware section of this document, only one selected Simulator PC connected to a Basic Serial Splitter Module can be used to send CLI configuration data to the Simulator Interface Module.
- Pin 3 will be used for CLI data sent to the Simulator Interface from the selected attached PC only. On all other connectors this pin will connected to an inactive RS-232 receiver.

The wiring of this connector is shown in the following diagram:

Figure 31 – Basic Serial Splitter DB9 Serial Connectors

# Simulator Interface Module Firmware

## Sensor Characteristics

Over the years several different approaches have been used for detecting the position of a tied or dumb bell and translating that position into a signal for use by a Simulator. These are discussed above.

- For the purposes of the Type 2 Simulator Interface Module, the essential feature of the sensor is that it should generate a signal pulse with a clean change of logic state when the bell is at the bottom dead centre of its swing.
- The Type 2 Simulator Interface Module adopts the convention that the output of a sensor should normally be logic high (~+5V), falling to logic low (~0V) for the duration of the pulse. This approach retains compatibility with other similar systems.
- The minimum practical pulse duration is a few milliseconds, but should be long enough to allow for the positive detection of good signals and the rejection of noise. Practical implementations have shown actual pulse durations in the range 5ms-20ms.
- The design of the Simulator Interface Module firmware is such that the maximum apparent pulse duration may be several hundred milliseconds. The state of the output from the sensor is ignored from the time a good signal is confirmed to the expiry of the “guard timer”.

## Firmware Design

### Interrupt Driven vs Polling

As noted in the hardware section above, an interrupt-driven approach to the Simulator Interface firmware would be problematic on the Atmel ATmega328P microcontroller hardware. The firmware therefore uses a polling approach. After completing initialization and setup, the main code loop cycles round all the configured bells’ inputs, processing signals from the Sensor Modules and sending serial data to the Simulator PC as appropriate. After all bells have been processed, the code loops round and the process starts again.

In the current version of code (v3.5), with the ATmega328P driven by an external 8MHz resonator, each iteration of the main polling loop takes approximately 400µs when configured for 16 sensors, which is fast enough for the disadvantages of polling not to be significant. Enabling debug mode and the CRO timing pin increases the loop time by a few percent, but as these are not intended for active simulator use this is also not significant.

The timing of the main loop using the CRO timing pin is illustrated in the following CRO capture:

Figure 32 – Simulator Interface Main Loop Timing

Processing of serial input from the Simulator, in the form of CLI commands, is triggered by the standard Arduino serialEvent() function.

### State Machine Operation

The Simulator Interface firmware maintains a set of 16 simple state machines, one for each bell. At any given time, each state machine may be in one of three possible states: Waiting for Input, Waiting for Debounce, Waiting for Guard Timer, Sensor Disabled, or Test Mode.

These changes of state are illustrated in the following diagram:

Figure 33 – State Machine Transitions Illustration

#### Waiting for Input

When a channel’s state machine is in the Waiting for Input state, on each iteration of the polling loop the firmware code reads the state of the input pin connected to the associated channel, and checks for a change in state (since the last poll) from logic HIGH to LOW, which would indicate the start of a signal pulse from the connected Sensor Module.

- If no HIGH to LOW change in state is detected, then the Interface code does nothing other than update its record of the last observed state of the input pin, and the code loop moves on to the next bell.
- If the start of a sensor pulse is detected then the code calculates the time at which the input de-bounce timer should expire (by adding the value of the global de-bounce timer to the current time from the microcontroller’s internal clock, in effect setting a timeout value), and switches the state machine into the Waiting for Debounce state. The default value for the de-bounce timer is 2ms, but this can be configured through the Simulator Interface CLI.

#### Waiting for Debounce

When a channel’s state machine is in the Waiting for Debounce state, on each iteration of the polling loop the firmware code reads the state of the input pin connected to the associated channel.

- If the pin state is detected as HIGH, then the input pulse previously detected has ceased. The code treats this as a “misfire” and switches the state machine back to the Waiting for Input state. The code loop moves on to the next bell.
- If the pin state is still LOW, the code compares the value of the de-bounce timeout with the current time from the microcontroller’s internal clock.
- If the timeout value has not yet been reached, the code does nothing and moves on to the next bell. The state machine remains in the Waiting for Debounce state.
- If the timeout has been reached or has been passed, the code sends the appropriate character over the serial interface to the Simulator PC, and switches the state machine into the Waiting for Guard Timer state.

#### Waiting for Guard Timer

When a channel’s state machine is in the Waiting for Guard Timer state, the firmware code compares the value of the Guard Timer timeout with the current time from the microcontroller’s internal clock.

- If the timeout value has not yet been reached, the code does nothing and moves on to the next bell. The state machine remains in the Waiting for Guard Timer state.
- If the timeout has been reached or has been passed, the code switches the state machine back into the Waiting for Input state, and the cycle starts again. The default value for the Guard Timer is 10cs (100ms), but this can be configured through the Simulator Interface CLI.
- The channel input pin is not read in the Waiting for Guard Timer state (other than for debugging purposes), effectively debouncing the end of the sensor pulse.

#### Disabled Sensor

When a channel’s state machine is in the Sensor Disabled state, the firmware code does nothing and moves on to the next bell. Sensor Disabled state is enabled through the CLI or from EEPROM configuration data during setup, and the state machine remains in the Sensor Disabled state until reset through the CLI.

Note that the number of channels to be scanned on each iteration is determined dynamically with reference to the highest numbered enabled channel: For example, if the highest numbered enabled channel is channel 10, only channels 1 to 10 will be scanned, shortening the loop time. If the highest numbered enabled channel is channel 16, then channels 1 to 16 will be scanned.

#### Test Mode

The Test Mode state implements a very simple test function, ignoring sensor inputs and generating simple test patterns on the serial interface. Test Mode state is enabled through the CLI, and persists until the interface is reset. This facility exists primarily for testing other components of a simulator installation.

The foregoing description covers the core simulator functionality. In addition to this, debug code provides additional timing and data gathering functions which are described later.

### Timer Issues

The ATmega328P microcontroller lacks a true Real Time Clock. The library inbuilt timing functions (millis() and micros()) return the number of milliseconds or microseconds respectively since the microcontroller was last powered on or the last hardware reset. All times used within the software are therefore offset times from this baseline.

The Simulator Interface firmware uses both the millis() and micros() functions for its main timing and delay calculations (micros() is used only by debugging code). These functions return 32-bit unsigned long data types; consequently the value returned by micros() will increase and then overflow back to zero after approximately 50 power-on days, and the value returned by micros() will overflow approximately every 70 minutes.

These overflows would disrupt simulator processing, as state machines may become “stuck” waiting for an overflowed timer to expire.

- In the case of the micros() timer, which is used for the sensor debounce timer, the Simulator Interface firmware attempts to catch this overflow, and looks for timer expiry times which are an unreasonably long time into the future.
- For the millis() timer, the current version of Simulator Interface firmware will require a power cycle or reset to clear the problem. This issue may be addressed in a future version of the firmware. However, this is considered a low-priority issue because it is unlikely that a Simulator Interface will be left powered up for such extended periods of time.

### Sensor De-Bouncing

The Simulator Interface firmware reacts to the start of a pulse from a sensor. In practice the output from some sensor types may be noisy and consist of a number of very short pulses, especially at the start or end of a pulse. This is known as “bounce”, a term derived from the physical elastic bounce of a mechanical contact. This is illustrated in the following diagram:

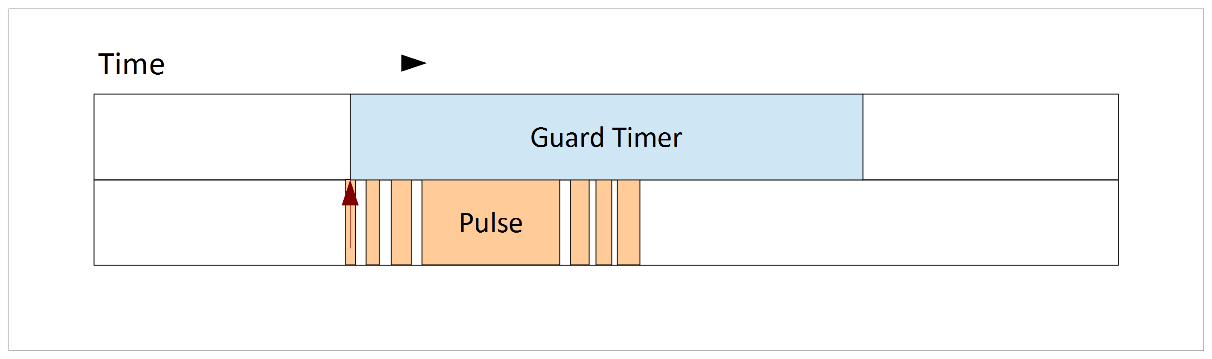
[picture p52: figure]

Figure 34 – Sensor De-Bounce Illustration

The current version of the Simulator Interface code reacts to the first observed transition in the output of the sensor (indicated by the red arrow on the diagram).

The code then requires that the sensor signal remains stable for at least the duration of the global debounce timer (default 2ms, configurable). If the detected signal ceases within that interval then the signal is treated as a “misfire”, is ignored, and the code returns the state machine to the Waiting for Input state. The debounce timer is specified in milliseconds, but calculated in microseconds for improved consistency. The resolution of the microsecond timer is 8µs.

When the state machine has switched into the Waiting for Guard Timer state, the input pin is not read at all (other than by debug code, which includes specific detection and reporting of multiple pulses), and any sensor bounce is therefore ignored. Provided that the overall sensor pulse is shorter than the duration of the guard timer, this effectively de-bounces the input. Typically, the input pulse from an optical sensor will be a few milliseconds in duration, and the guard time several hundred milliseconds, so this is not a practical issue.

In testing, no evidence of sensor bounce from the standard infra-red optical or Magnetic Sensor Modules was observed, within the resolution of the debug timing code and the microsecond timer.

### Debugging & Timing Features

In addition to the core timing and delay functions described above, which are required for core Simulator operation, the Simulator Interface firmware implements further timing and data gathering for debugging and experimental purposes. This output is not suitable for sending to Simulator Software package, but may be accessed via a terminal emulator such as PuTTY.

This debugging functionality is not part of the MBI Protocol specification.

Under normal operations, each pulse from a Sensor Module causes one ASCII character (following the conventional ringing notation of 1-9, 0, E, T) to be sent via the serial port for use by the Simulator PC, as defined in the MBI Protocol specification.

The following debugging features are available in firmware v3.5:

#### Debug Mask

The Debug Mask allows for debugging output to be enabled on a specific subset of input channels.

- This may be used to reduce the volume of debug output generated during fault finding. By default, the mask enables debugging on all 16 channels.
- The Debug Mask setting may be saved in non-volatile EEPROM[^37].
- Note that enabling Debug Mode globally suppresses normal simulator output for all channels, not just those set in the debug mask.

#### Debug Pulse Timer

When the Debug Pulse Timer flag is set, each valid input pulse will generate output on a separate line, with the following space separated data fields:

- The identifier “S”,
- The channel number (1-16),
- The mapped ASCII character (1-90ETABCDWXYZ),
- The guard timer expiry offset time in milliseconds,
- The duration of the (first) detected pulse, in microseconds,
- The total number of pulses detected before the expiry of the guard timer,
- The delta between the start of this input pulse and the start of the previous one, in milliseconds.

Note that the pulse length timing code is not entirely robust: the assumption is made that the first Sensor Module pulse will be shorter than the guard timer. If the first pulse has not completed by the time the guard timer expires, a spuriously large result would be displayed for the pulse length, because the last recorded pulse end time (from the previous sensor pulse) will be before the current pulse start time, and the unsigned long data type will overflow. This is trapped by the code and displayed as a zero duration. This limitation affects debugging output only.

#### Debug Show Misfires

When the Debug Show Misfires flag is set, pulses shorter than the de-bounce timer will generate output on a separate line, with the following space separated data fields:

- The identifier “M”,
- The channel number (1-16),
- The mapped ASCII character (1-90ETABCDWXYZ),
- The debounce timer expiry offset time in microseconds,
- The duration of the (first) detected pulse, in microseconds.

#### Debug Swing Timer

When the Debug Swing Timer flag is set, each valid input pulse will generate output on a separate line, with the following space separated data fields:

- The identifier “T”,
- The channel number (1-16),
- The mapped ASCII character (1-90ETABCDWXYZ),
- The duration of the current swing in milliseconds,
- The delta between the duration of the current and previous swing, in milliseconds.

The swing timer is intended to be used to check how close the sensor is to the BDC point, with the bell down and swinging through small arcs.

The duration of the current swing is defined as the period between the start of the most recent sensor pulse and the start of the sensor pulse immediately previous (and thus is always positive). The swing time delta is the difference between the current swing duration and that of the swing immediately previous (and may be positive or negative). Adjust the position of the sensor to get the delta value as close to zero as possible.

#### Debug Show Debounce

When the Debug Show Debounce flag is set, pulses longer than the debounce timer will generate output on a separate line, with the following data fields:

- The identifier “D”,
- The channel number (1-16),
- The mapped ASCII character (1-90ETABCDWXYZ),
- The debounce timer expiry offset time in microseconds.

#### Debug Show LED

When the Debug Show LED flag is set, the diagnostic LED output will be enabled for all bells for which debugging is enabled. By default, the diagnostic LED indicates pulses detected on channel 1 only.

#### Debug Settings

Debug settings other than the Debug Mask are volatile and are not retained in EEPROM. Resetting the Simulator Interface will revert to the following default debug settings:

- Debug Mode: Off
- Debug Flags: Debug Pulse Timer
- Debug Mask: EEPROM Value

Note that changes to the configured Debug Flags and the Debug Mask are remembered if Debug Mode is disabled via the CLI, so debugging may be resumed easily with the same settings.

### Serial Input & Command Line Interface

The Simulator Interface firmware implements a simple Command Line Interface (CLI), which may be used to configure certain aspects of the Interface, or to gather debugging and timing data. This functionality is not part of the MBI Protocol specification.

The Simulator Interface also must handle legitimate MBI Protocol commands and delay data sent by the Simulator Software, in order to differentiate these from CLI input (even though these data are not used by the Type 2 Simulator Interface). This processing is done inside the Arduino serialEvent() function, with the CLI itself handed off to a set of separate functions.

To achieve this, the firmware adopts the following strategy when handling serial input.

- The first byte received is examined. If this byte is the MBI Protocol 0xFD command, a 0xFD response is sent. If the first byte is any other recognised MBI Protocol command (See Appendix B), it is discarded. No other responses are sent to MBI commands.
- If the first byte is not a recognised MBI Protocol command, it may be the first of a set of updated delay values. There is no defined command byte defined in the MBI Protocol to precede a set of delay values, so the Simulator Interface attempts to read a full set of 13 bytes (12 values plus the specified terminator byte) within a defined timeout interval (one second in the current v3.8 firmware).
- If 12 values plus the correct terminator byte have been received within the timeout period, these are assumed to be delay values, and all 13 bytes are discarded.
- If a full set of values cannot be read, or the terminator is incorrect, the first (and possibly only) byte read is passed on to the CLI handler for further examination. Any bytes after the first are discarded.
- If the received byte is a recognised CLI command (Appendix B), it is processed, and any appropriate response sent.
- If the received byte is not a recognised CLI command, it is discarded.

The diagnostic LED is used to indicate that a CLI command has been received, or that an error occurred. The CLI command are documented in Appendix D below.

### Sensor Enable/Disable

The Simulator Interface firmware can be configured to disable any individual sensor input, for example to bypass temporarily a faulty sensor. Disabled inputs are ignored by the firmware, and generate no serial output, including debugging output. This behaviour is configured using CLI commands (Appendix D), accessed via a terminal emulator. The enabled or disabled state of each input channel is stored in non-volatile EEPROM.

As noted above, the number of channels to be scanned on each iteration is determined dynamically with reference to the highest numbered enabled channel.

### Memory Footprint

The ATmega328P has a very limited 2kByte SRAM capacity. The MemoryFree software library has been incorporated into the Simulator Interface code to track SRAM usage. This may be displayed via the Interface CLI. Flash (Program) Memory usage is reported by the Arduino IDE when the software sketch is compiled.

The memory footprint of the Simulator Interface firmware v3.8 on an ATmega328P is as follows:

- 13,016 / 32,768 Bytes Flash Memory
- 839 / 2,048 Bytes SRAM
- 23 / 1,024 Bytes EEPROM

The compiler F() macro has been used throughout the Interface code to store static text strings into program memory, thus relieving pressure on SRAM. As a result, the current v3.8 of the Interface firmware can run on older ATmega168 microcontrollers with 16kBytes of Flash Memory and only 1kByte of SRAM[^38].

## Metrics

The effects of three key metrics have been considered in the design of the Simulator Interface firmware. These are:

- The inter-blow interval: The rate at which the Simulator Interface is required to detect and transmit signals from all Sensor Modules to the Simulator during normal ringing.
- The inter-row interval: The rate at which the Simulator Interface is required to detect signals from any one Sensor Module during normal ringing.
- The Sensor Pulse Duration: The length of the pulse from each Sensor Module which the Simulator Interface is required reliably and unambiguously to detect.

Each of these metrics is considered further below.

### Inter-Blow Interval Requirements

For any given ring of bells, the inter-blow and inter-row requirements can be estimated from the known speed of ringing.

For example, for the Liverpool Cathedral bells, taking 4h 30m as a representative speed for a peal of 5042 changes of Maximus on the (82cwt) twelve, the inter-blow interval in rounds is given by the calculation:

(270 minutes x 60 seconds) / (5042 changes x 12 bells) = 0.268s or 268ms

Taking 3h 15m as a representative speed for a peal of 5056 changes of Major on the light (24cwt) eight, the inter-blow interval in rounds is given by the calculation:

(195 minutes x 60 seconds) / (5056 changes x 8 bells) = 0.289s or 289ms

The serial protocol used by the Simulator Interface Module runs at 2400 bits per second, and sends a single ASCII character for each blow of each bell. Each character comprises 10 bits (8 data bits, plus 1 start bit and 1 stop bit), giving a maximum continuous data rate of 240 characters per second, or approximately 4.2ms per character.

This confirms that the Simulator Data Connection has sufficient capacity, and has a resolution of approximately 1.6% of the inter-blow interval. Put another way, if the bells are fired accurately then the signals from all 12 bells can be sent over the data link to the Simulator PC within 51ms, or less than one fifth of the normal inter-blow interval. (True firing, the simultaneous striking of more than one bell, is not achievable with a Simulator Interface of this design.)

Under normal operation, where one byte at a time is sent to the Simulator PC, the serial print function call is non-blocking and operates asynchronously, so the main code loop is not slowed down or paused while data is sent to the Simulator PC[^39].

(Note that generating detailed debugging output from a large number of bells can cause the serial output buffer to fill and the serial print function to block. This can cause issues with timing behaviour and debugging output.)

A more detailed analysis of the inter-blow intervals for a large sample of rings of bells may be found in Appendix C.

### Inter-Row Interval Requirements

The inter-row interval follows from a similar calculation:

For the Liverpool Cathedral bells, taking 4h 30m as a typical speed for a peal of 5042 changes of Maximus, the inter-blow interval in rounds is given by the calculation:

(270 minutes x 60 seconds) / 5042 changes = 3.21s

Taking 3h 15m as a typical speed for a peal of 5056 changes of Major on the light (24cwt) eight, the inter-blow interval in rounds is given by the calculation:

(195 minutes x 60 seconds) / 5056 changes = 2.31s

As discussed below, the Simulator Interface firmware runs with a loop time of approximately 400µs, giving a resolution of less than 0.017% of the typical 12-bell inter-row interval.

A more detailed analysis of the inter-row intervals for a large sample of rings of bells may be found in Appendix C.

### Sensor Pulse Duration

For a typical, the theoretical expected duration of the signal pulse from the Sensor Module is a function of the width of the trigger (e.g., 25mm wide reflective tape or 20mm diameter magnets in the current installations) and the linear speed of the rim of the bell wheel as the bell passes through the bottom dead centre trigger point.

This linear speed can be approximated as 4πR/T, where R is the radius of the wheel, and T is the pendulum period of the bell for small oscillations. This calculation is based on the work of Frank King of Cambridge[^40]. Applying the basic equations of motion to these parameters produces theoretical pulse durations of approximately 4ms.

However, this does not take into account the actual size of the sensor head, and the fact that the sensor head may activate before the trigger is fully axially aligned with the module (and will not deactivate until after the trigger has ceased to be fully axially aligned). In addition to this, the detection zone on many sensors is effectively conical, and at the wheel is therefore somewhat larger than the physical diameter of the detector.

The following diagram illustrates this effect:

Figure 35 – Sensor Pulse Duration Illustration

In the diagram above, the Sensor Module signal pulse starts before the trigger is fully aligned with the sensor (top red arrow), and ends after the trigger has cease to be fully axially aligned (bottom red arrow). Thus, the effective width of the trigger, and the duration of the resulting pulse, are increased.

This is supported by evidence: An analysis of the theoretical and observed sensor pulse durations from the optical Sensor Heads of the original Liverpool Cathedral Simulator installation can be found in Appendix C. The sensor shielding tube has an internal diameter of approximately 17mm, and the observed values of pulse duration, approximately 6ms, indicate that the effective width of the reflector is increased from the actual 25mm to approximately 40mm.

## Potential Problems

The use of a polling approach in the Simulator Interface results in a number of potential problems:

### Missed Sensor Signals

If the Simulator Interface firmware polling interval is longer the pulse emanating from a Sensor Module, then there is a risk that some pulses may be missed. If a pulse starts just after the polling loop has examined a particular input pin, the pulse will have completed before the polling loop next returns to that input pin. As a result the pulse will be missed and no signal will be sent to the Simulator.

The following diagram illustrates this problem:

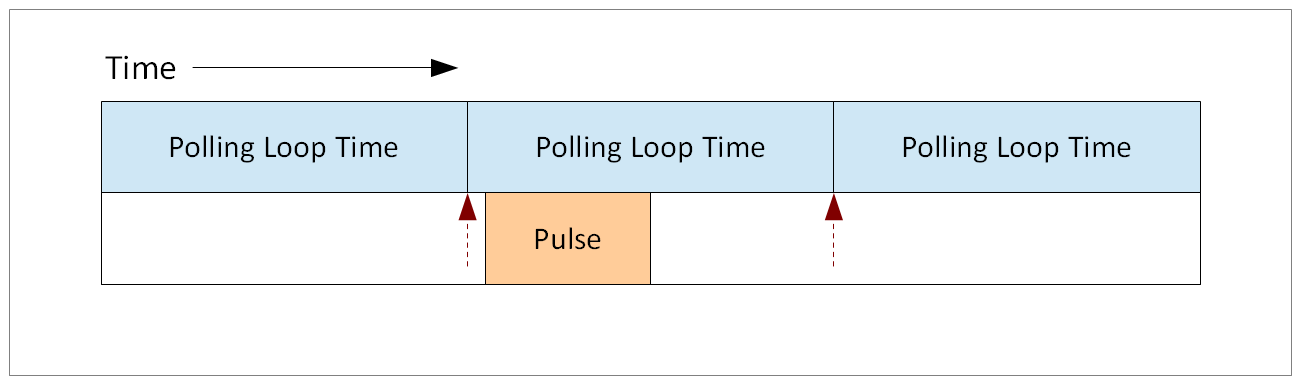
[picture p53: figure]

Figure 36 – Missed Sensor Signals Illustration

The red dashed arrows indicate the point at which the polling loop examines a particular input pin. During the remainder of the polling loop an incoming sensor pulse begins and completes without ever being detected.

Given a typical pulse duration of approximately 6ms, and a maximum polling loop duration of approximately 400µs, each pulse therefore lasts approximately 15 polling loop cycles, so this problem does not arise.

### Duplicated Sensor Signals

If the Simulator Interface firmware polling interval is shorter than the pulse emanating from a Sensor Module (which, as noted above, is a requirement for reliable detection), then there is a probability that some pulses may be detected more than once. If the polling loop examines a particular input pin just after a pulse starts, then that pulse may still be in progress when the polling loop next returns to the same input pin. As a result the pulse will be detected more than once and duplicate signals would be sent to the Simulator PC.

The following diagram illustrates this problem:

Figure 37 – Duplicated Sensor Signals Illustration

The red arrows indicate the points at which the polling loop examines a particular input pin. Because the incoming sensor pulse is longer than the polling loop, it is still in progress during the next loop, and would be detected again.

This problem is avoided by triggering based on detecting the transition of the input pin state from HIGH to LOW, and keeping state in the Interface code. Therefore, when the polling loop next returns to the input pin, the pin is still LOW, but no state transition is detected, and no duplicate signals are sent.

It will be observed that decreasing the polling loop duration to avoid the Missed Sensor Signals problem results in the manifestation of the Duplicated Sensor Signals problem, and vice-versa.

### Variable Odd-Struckness

A further problem arising from the use of a polling architecture in the Simulator Interface is variable odd-struckness.

- If a pulse from any particular Sensor Module starts a fraction of a second before the polling loop examines the associated input pin, the pulse will be detected almost immediately.
- If the pulse starts a fraction of a second after the polling loop examines the associated input pin, the pulse will be detected on the next iteration of the polling loop, in this case approximately 400µs later.
- There is no fixed correlation between the start time of a pulse and the current position of the polling loop in its cycle, and therefore each pulse is subject to an effectively random delay of between zero and 400µs (the duration of the polling loop).
- This would be experienced as the simulated bell striking randomly early or late by between zero and half the polling interval.

The following diagram illustrates this problem:


Figure 38 – Variable Odd-Struckness Illustration

The upper red arrow indicates the polling loop examining a particular input pin just after the start of an incoming sensor pulse. The delay due to polling is effectively zero. The lower red arrow indicates the polling loop examining a particular input pin just before the start of an incoming sensor pulse, and detecting the pulse on the next iteration of the loop. The delay due to polling is effectively equal to the polling loop interval.

Given a typical inter-row interval of say 2.3s, and a maximum polling loop duration of approximately 400µs, the variable odd-struckness contributed due to this problem is therefore between zero and ±0.009% of the inter-row interval, and in practice this is not detectable. Even for much lighter rings of bells with much shorter inter-row intervals this may still be assumed to be negligible.

Scope does exist to reduce the length of the polling loop further. The debug and timing code contribute approximately several tens of microseconds to the loop time, and could be omitted entirely from production code.

### Latency

The latency of a simulator system is the delay between the bell triggering the sensor at BDC, and the arrival of the corresponding signal at the Simulator PC.

The latency of the simulator system is not critical in BDC detecting systems, provided it is relatively small (much less than the time between BDC and strike), is reasonably consistent, and is symmetrical about the BDC position. Latencies of up to several tens of milliseconds may be accommodated by tuning the delay time applied by the Simulator PC.

The latency of the simulator consists of the sum of the following:

- The debounce timer,
- The polling loop time,
- The RS-232 serial speed.

The default debounce timer is set to 2ms. As discussed above, the polling approach results in some variation of detection time, and the polling loop time is approximately 400µs. Moving the state machine from Waiting for Input to Waiting for Debounce, and then detecting the end of the debounce timer, involves two polling events. The average latency from the start of a sensor pulse to the start of the serial transmission should therefore be approximately[^41] 2.4 ±0.2ms.

The serial line speed is 2400bps. Each ASCII character transmission consists of 10 bits (8 data bits, preceded by one start bit and followed by one stop bit). The time taken to transmit one character is therefore approximately 4.2ms and is constant.

The theoretical total latency of the simulator is therefore approximately 6.6 ±0.2ms. Any additional latency arising in the Simulator Software Package is beyond the scope of this discussion but may be compensated for by tuning the delay time applied by the software.

The typical latency of the Simulator Interface is illustrated in the following annotated CRO capture:

Figure 39 – Simulator Interface Latency

- The upper yellow trace represents a simulated sensor pulse measured on a Simulator Interface Module input pin. The duration of the pulse is approximately 5ms, and the pin transitions from +5V to 0V at the start of the pulse.
- The lower blue trace represents the RS-232 serial transmission, measured on the serial transmit pin of the same interface.
- On the serial line, logic 0 is a high voltage (approximately +8V), logic 1 is low (approximately -8V), and the bus idles at the logic 1 level[^42]. The start bit is logic 0, the stop bit is logic 1, and hence the end of the stop bit cannot be distinguished from the idle level.
- The character transmitted is ASCII “1” (0x31), binary 00110001, and is transmitted LSB first. Reading from left to right, the total bit stream is therefore “0100011001” (10 bits: a logic 0 start bit, ASCII “1” LSB first, and a logic 1 stop bit).
- The delay between the start of the sensor pulse and the start of the serial transmission is measured over multiple pulses as being between 2.200ms and 2.660ms, average 2.442ms. The latency start to end of the serial transmission can be estimated as approximately 4.2ms. These values are very close to the theoretical predictions.

The following logic analyser decode taken at the MAX233 transmitter input shows the same effect:

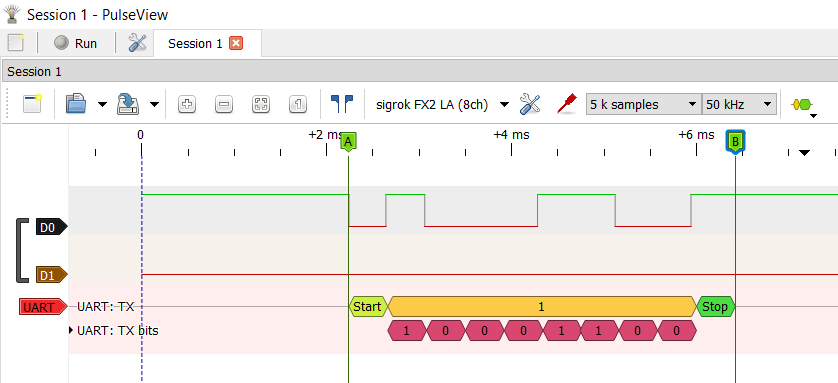
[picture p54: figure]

Figure 40 – Logic Analyser Decode

- Trace D0 is taken from the TTL level signal at the MAX233 transmitter input. The signal is therefore inverted with respect to the transmitter output recoded by the previous oscilloscope trace.
- Trace D1 is the trigger, taken from the channel 1 sensor line. Recording started at Time 0 when this line transitioned to logic 0. This was a manual trigger, so the end of the trace is not visible as the pulse was more than 8ms long.

## Software Development & Compatibility

### Development Environment

The current Simulator Interface firmware has been developed on the following versions of operating systems, development tools and Simulator Software packages. Later versions of tools are expected to be compatible:

- Microsoft Windows 10 64-bit
- Arduino IDE 1.8.19
- PuTTY 0.81
- ~~PortMon 3.03~~[^43]

### Source Code Availability

The current version of the firmware for the Simulator Interface is available from the project GitHub repository at https://github.com/Simulators. The firmware is released under the GNU General Public Licence (GPL), Version 3.

### Simulator Software Compatibility

#### Tested Configurations

The Type 2 Liverpool Ringing Simulator Interface has been tested successfully with Simulator Software Packages up to the following versions:

- Abel 10.3.2
- Beltower 2025 (14.05)
- Virtual Belfry[^44] 3.10

#### Untested Configurations

Compatibility with the Bagley Ringleader hardware simulator has not been tested. This device has been unavailable for purchase for some time due to key components no longer being available.

#### Future Simulator Support

The Simulator Interface software has also been structured to allow for the future addition of support for other simulators should this be necessary.

# USB-to-Serial Adapters

If the Simulator PC does not have an available RS-232 serial port, then a USB-to-Serial adapter may be used. These are available from a variety of manufacturers, but mainly use controller chips manufactured by Prolific and FTDI.

Modern versions of Windows include drivers for many USB-to-Serial adapters. However, older versions of Windows or some adapters may require the installation of software drivers. This section illustrates the installation process for older versions of Windows. Consult the documentation for your USB-to-Serial adapter to check whether the adapter is supported on your version of Windows, and whether manual driver installation is required.

This section also illustrates the process for renumbering COM ports if your adapter is assigned a COM port number outside the range supported by your Simulator Software Package. The process is similar on later versions of Windows.

Drivers for adapters based on Prolific[^45] and FTDI[^46] controllers are available from the respective websites; the driver required is the Virtual COM Port or VCP version.

A typical USB-to-Serial adapter (in this case from Prolific) is shown in the following photograph.

Figure 41 – Example of a USB-to-Serial Adapter

### Driver Installation

Follow the installation instructions supplied with the USB-to-Serial port driver software package. This example uses adapters and drivers with both Prolific and FTDI chipsets, but the approach is similar for adapters from other vendors.

1. Run the installer supplied with the driver software package. Both Prolific and FTDI drivers use a standard Windows installer.

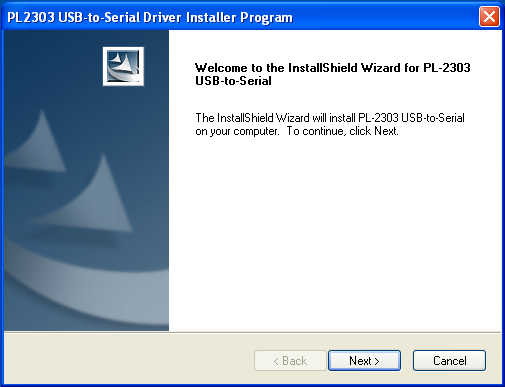
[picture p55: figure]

Figure 42 – Prolific Driver Installation

2. When the installation is complete, close the installer. A restart of the PC may be required.

Figure 43 – Driver Installation Complete

3. Connect the USB-to-Serial adapter to a spare USB port on the Simulator PC. To ensure consistent COM port numbering and avoid the need to reconfigure the Simulator Software Package, it is best always to use the same USB port for the adapter.
4. The Simulator PC should detect the USB-to-Serial adapter, configure the driver, and a confirmation balloon message should appear briefly above the Windows system tray.

Figure 44 – Found New Hardware Message

### Driver Verification

To verify that the USB-to-Serial adapter driver is correctly configured, open the Windows Device Manager and look for the adapter in the Ports section.

1. Right-click the Computer or My Computer icon on the Windows desktop and select the Properties menu item. These examples are from Windows XP and Windows 7 PCs, the process and appearance may vary for other versions of Windows.

Figure 45 – My Computer Context Menu (Windows XP)

Figure 46 – Computer Context Menu (Windows 7)

2. On Windows XP, click on the Hardware tab, and then click the Device Manager button.


Figure 47 – System Properties Hardware Tab (Windows XP)

3. On Windows 7, click the Device Manager button.

Figure 48 – System Properties Hardware Tab (Windows 7)

4. Expand the Ports (COM & LPT) section of the Device Manager list. The USB-to-Serial adapter should be listed, and the COM port number identified. In this example the adapter has been assigned the Virtual COM Port number COM3.

Figure 49 – Device Manager (Driver Installed)

5. If the device driver software has not been installed correctly, the adapter may be found with a warning marker in the Other Devices section of the device list. Install the device driver software or refer to the documentation for the USB-to-Serial adapter.


Figure 50 – Device Manager (Driver Missing)

### COM Port Reconfiguration

Current versions of specific Simulator Software Packages require that the Virtual COM Port number assigned to a USB-to-Serial adapter is in a specified range[^47]. If the adapter has been assigned a COM port number outside the supported range, the port must be reconfigured to lower value[^48].

1. Open the Windows Device Manager as described above.
2. Expand the Ports (COM & LPT) section of the Device Manager list. The USB-to-Serial adapter should be listed, and the COM port number identified. In this example the Prolific adapter has been assigned the Virtual COM Port number COM14, which is beyond the range supported by Abel.

Figure 51 – Device Manager (Port COM14)

3. Right-click the USB-to-Serial adapter entry and select the Properties menu item.


Figure 52 – Device Manager Context Menu

4. Click on the Port Settings tab, and then click the Advanced… button.

Figure 53 – COM Port Properties

5. Use the COM Port Number dropdown to select a COM port number in the range COM1 to COM8. Then click OK. Note that some values may be listed as “in use” if they have ever been assigned (for example, if other USB devices have been attached to the PC in the past). Use the Device Manager to determine which COM ports are in use.


Figure 54 – COM Port Advanced Settings (Prolific)

6. The Advanced Settings window for the FTDI driver is more complex, but the reconfiguration method is the same.

Figure 55 – COM Port Advanced Settings (FTDI)

7. It may be necessary to unplug the USB-to-Serial adapter, then plug it back before the adapter is correctly identified and initialised with the new COM port number.

Figure 56 – Device Manager (Reconfigured Port COM3)

# Interconnecting Type 1 & Type 2 Simulators

## Compatibility

Type 1 and Type 2 sensors and Simulator Interfaces are electrically compatible, both using +5V power supplies and active-low outputs, but the two generations of the simulator use different connectors, cabling, and wiring conventions.

Some installations may have a requirement to interconnect Type 1 and Type 2 hardware, for example to expand an existing Type 1 installation with additional Type 2 sensors. A simple adapter has been designed for this purpose.

## Type 1 – Type 2 Interface Adapter

The Type 1 – Type 2 Interface Adapter is designed to allow Type 2 sensors (using RJ45 connectors) to connect to a Type 1 Simulator Interface (using GX16-4 connectors). The adapter allows up to four Type 2 sensors, connected in a single chain, to connect to a Type 1 interface.[^49]

An example of a completed Interface Adapter and cable is shown in the following photograph, in this case wired to support connecting two Type 2 sensors to a Type 1 interface. The Type 1 interface sensor connectors may need to be modified with additional link wires to support multiple sensors; this is described in detail below.


Figure 57 - Type 1 - Type 2 Adapter

The connection and cabling requirements for the adapter are summarised in the following table:

Table 5 – Type 1 – Type 2 Interface Adapter Requirements

Number of Type 2 Sensors Connected | Number of Adapter Cables Required | Number of Type 1 Sensor Connectors | Type 1 Interface Link Wires Required?
1 | 1 | 1 | No
2 | 1 | 1 (plus 1 unused) | Yes - 1
3 | 2 | 2 (plus 1 unused) | Yes - 1
4 | 2 | 2 (plus 2 unused) | Yes - 2

The construction of the adapter cables and the configuration of link wires in the Type 1 Simulator Interface are described below.

## Schematic

## Interface Adapter PCB

Eagle CAD files and manufacturing Gerber files for the Interface Adapter PCB are available in the Type 2 GitHub repository. The Interface Adapter PCB is the same size as a Type 2 sensor PCB and will fit in the same size 0.07 Litre Really Useful Box®.

The following diagram shows the layout of the Type 1 – Type 2 Interface Adapter PCB. All components are mounted on the top (silkscreen) side of the board.


Figure 58 - Type 1 - Type 2 Adapter Board Layout

An example of a completed Interface Adapter is shown in the following photograph. As shown, this adapter would support the connection of up to two Type 2 sensors to a Type 1 Simulator Interface. An additional 4-way connector would need to be installed on the board to support a further two Type 2 sensors.

Figure 59 - Type 1 - Type 2 Adapter PCB

### Parts List

Table 6 – Type 1 – Type 2 Interface Adapter Parts List

Reference | Component | Notes
PCB | Type 1 – Type 2 Interface Adapter PCB
JP1 | Amphenol RJHSE-5080[^50] | Farnell 1860577
JP2, JP2 | 4-Way Molex KK 254 Connector | Farnell 1756798 (Molex 22-05-3041 Series 7478 PCB Header) Farnell 1462809 (Molex 22-01-2047 Series 2695 Receptacle) Farnell 2063734 (Molex 08-50-0113 Series 2759 Terminal)

## Interface Adapter Cabling

The wiring of the Interface Adapter cables is shown in the following diagram. One cable can support up to two Type 2 sensors, two cables are required to support up to four Type 2 sensors.


Figure 60 - Type 1 - Type 2 Adapter Cable

## Type 1 Interface Wiring Modification

To support more than one Type 2 sensor connected via the Interface Adapter, the Type 1 interface must be wired to support two sensors per GX16-4 connector. This approach is mentioned in the Type 1 Simulator Sensors Hardware Manual to support Type 1 sensor heads with two sensors.

An example of the required modification is illustrated in the following diagram. In this example, the Interface Adapter cable is connected to the top connector, Connector 1, and Connector 2 would be unused. An additional link wire is fitted between pin 4 of Connector 1 and pin 3 of Connector 2, to route the signal from the second sensor to the channel 2 of the interface.

Figure 61 - Type 1 Interface Connector Wiring Modification

# Appendices
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

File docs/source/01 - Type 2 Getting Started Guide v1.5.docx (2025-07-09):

Type 2 Liverpool Ringing Simulator

01 – Getting Started Guide


Author: Andrew Instone-Cowie

Date: 09 May 2025

Version: 1.5

# Index of Figures

# Document History

Version | Author | Date | Changes
0.1 | A J Instone-Cowie | 10/09/2018 | First Draft.
0.2 | A J Instone-Cowie | 10/02/2019 | Added link to documentation on GitHub.
0.3 | A J Instone-Cowie | 12/05/2019 | Add support for Second PC Board.
0.4 | A J Instone-Cowie | 27/05/2019 | Added link to ART Simulator Resources website.
1.0 | A J Instone-Cowie | 03/08/2019 | First Release.
1.1 | A J Instone-Cowie | 01/10/2019 | Multi-PC Options.
1.2 | A J Instone-Cowie | 18/08/2020 | Minor update.
1.3 | A J Instone-Cowie | 22/07/2021 | Add notes about Faculty Jurisdiction, remove references to COVID-19.
1.4 | A J Instone-Cowie | 19/06/2024 | Update external links, general text updates.
1.5 | A J Instone-Cowie | 09/05/2025 | Restyled MR sensors as “Magnetic Sensors” for consistency with Build & Installation Guide.

Copyright ©2018-25 Andrew Instone-Cowie.

Cover photograph: Prototype magnet mount, Liverpool Cathedral treble.

# Licence

This work is licensed under a Creative Commons Attribution-ShareAlike 4.0 International License.[^1]

Unless otherwise separately undertaken by the Licensor, to the extent possible, the Licensor offers the Licensed Material as-is and as-available, and makes no representations or warranties of any kind concerning the Licensed Material, whether express, implied, statutory, or other. This includes, without limitation, warranties of title, merchantability, fitness for a particular purpose, non-infringement, absence of latent or other defects, accuracy, or the presence or absence of errors, whether or not known or discoverable. Where disclaimers of warranties are not allowed in full or in part, this disclaimer may not apply to You.

To the extent possible, in no event will the Licensor be liable to You on any legal theory (including, without limitation, negligence) or otherwise for any direct, special, indirect, incidental, consequential, punitive, exemplary, or other losses, costs, expenses, or damages arising out of this Public License or use of the Licensed Material, even if the Licensor has been advised of the possibility of such losses, costs, expenses, or damages. Where a limitation of liability is not allowed in full or in part, this limitation may not apply to You.

# Attribution

The Creative Commons Attribution-ShareAlike (CC BY-SA) licence permits you to re-use this material for any purpose you wish, subject to the conditions of the licence, including providing attribution of the source.

The following is suggested as a suitable form of attribution for this document, or extracts thereof:

Type 2 Getting Started Guide, Liverpool Ringing Simulator Project (https://www.simulators.org.uk). This document is licensed under the CC BY-SA 4.0 licence (https://creativecommons.org/licenses/by-sa/4.0/). © 2018-2025 Andrew J Instone-Cowie.

# Documentation Map


Figure 1 – Documentation Map

# About This Guide

The Type 2 Liverpool Ringing Simulator allows sensors, attached to one or more real tower bells or teaching dumb bells, to be connected to a Simulator Software Package such as Abel[^2], Beltower[^3] or Virtual Belfry[^4] running on one or more PCs. This allows you to extend and augment the teaching and practice opportunities in your tower.

This Getting Started Guide introduces the Type 2 Liverpool Simulator and the Liverpool Ringing Simulator Project.

In this guide you will find:

- The background to the project.
- A brief introduction to the Type 2 Simulator hardware modules.
- Guidance on planning your simulator installation.

The other guides contain detailed information on how to build and install the simulator hardware modules and configure a selection of popular Simulator Software Packages. The other guides available are:

- Build & Installation Guide
- Configuring Abel Guide
- Configuring Beltower Guide
- Configuring Virtual Belfry Guide
- Multi-PC Guide
- Technical Reference Guide.

Please note that this is a Build-it-Yourself project. No pre-built hardware is available.

## First Steps

This guide is your starting point for the installation of a Type 2 Liverpool Simulator. It provides guidance and suggestions of things you might want to consider when planning your simulator setup.

## Next Steps

Once you have completed basic planning, move on to the Build & Installation Guide for guidance on building and installing the Type 2 Liverpool Simulator, and the Technical Reference Guide if you need more detailed information on a particular topic.

All the documentation for the Type 2 Liverpool Simulator can be found in the docs folder on the project GitHub repository:

- https://github.com/Simulators/simulator-type2/tree/master/docs

# Background

## The Liverpool Cathedral Simulator

The Liverpool Ringing Simulator project was originally based on work undertaken at Liverpool Cathedral to provide a 12-bell simulator for demonstration and training purposes.

The tower of Liverpool Cathedral is open to the paying public during the day, except when ringing is taking place. During regular opening hours visitors can view the bells (which are usually left up) from a gallery above as they pass through the upper levels of the belfry but have no access to the ringing room or belfry floor. These paying visitors are an important revenue stream for the Cathedral, but during ringing the tower is closed to visitors for health and safety reasons.


Figure 2 – Liverpool Cathedral Bells[^5]

The Cathedral tower was also open weekly to the paying public during the summer months for evening Twilight Tours, and from 2012 this was supplemented once a month with guided access to the ringing room and belfry, under the supervision of the Cathedral ringers. Statistics showed that visitor attendances on the “with bells” nights were well above the average, and so the Cathedral were keen to develop this aspect. The Cathedral ringers were also keen to use these events as a means of promoting the work of the Cathedral ringers and ringing generally to the public[^6].

The original 12-bell Liverpool Ringing Simulator was developed and installed in time for the 2014 season, and was later expanded with an additional six bell Saxilby simulator set up in the ringing room.


Figure 3 – Saxilby Simulator Installation, Liverpool Cathedral

## The Liverpool Ringing Simulator Project

From that beginning, the scope of the project has grown, with the aim of producing and publishing designs, software and documentation to enable other towers to build and install their own simulators at relatively low cost.

The objective is straightforward: More simulators in more towers means more time and opportunities for teaching and practice. Learners can spend more time on the end of a rope, leading to faster learning and better engagement. Established bands can extend and improve their capabilities with more opportunities to ring, including extended ringing such as quarter peals.

The use of simulators has great potential in the training of new ringers and the improvement of established bands, and therefore the Liverpool Ringing Simulator Project seeks to promote the installation and take-up of simulators in towers as a teaching aid.

In addition, the project makes all aspects of the design of the simulator available under a Creative Commons licence[^7], and releases all software under the GNU General Public Licence (GPL)[^8], making it the first fully Open Source Hardware simulator, freely available for re-use, adaptation and improvement by other ringers.

Although the original Liverpool Ringing Simulator worked well, and a number were built and deployed in other towers, it became clear from feedback received from builders and our own experiences, that the original simulator could be improved upon, and construction simplified[^9].

# The Type 2 Simulator

Full design and construction details can be found in the Build & Installation Guide, but in summary the general arrangement of a Simulator installation is shown in the diagram below.

The simulator is modular. Sensor modules in the belfry, on up to 16 bells, are connected to a Simulator Interface module. A single cable connects the Interface to a PC in the ringing room, running one of the commercially available Simulator Software Packages. The same cable powers the Interface and Sensors from a low voltage power supply.


Figure 4 – Simulator General Arrangement

## What’s New?

The Type 2 simulator has been completely redesigned and updated.

### Expanded Capacity

- The Type 2 Simulator now supports up to 16 sensors on a single interface module.
- These can be real tower bells, practice dumb bells, or any combination.
- The Type 2 Simulator supports multiple (up to 16) Simulator PCs used concurrently.

### Redesigned PCBs

- The Simulator Interface module and Sensor module PCBs have all been redesigned for easier construction.
- The Interface PCB is larger, less crowded and has improved heatsinking for the voltage regulator – an additional heatsink will rarely be required.
- A Power module PCB simplifies connections between the PC, Interface and power supply in the ringing room.
- PCB header pins are replaced with RJ45 connectors, which are much easier to assemble.
- CAM files for PCB “panels” of Sensor and Power PCBs are available, reducing costs.

### Simplified Enclosures

- Replaced the enclosures with readily available Really Useful™ boxes.
- Enclosure drilling and cutting are simplified, and much is eliminated altogether.
- Printable templates are supplied for marking out enclosures for drilling.
- Enclosure lids simply clip on, eliminating many tiny screws.

### Off the Shelf Cables

- Uses off the shelf RJ45 network cables, eliminating making and soldering custom cables.
- Together with the redesigned PCBs and enclosures, this eliminates the need for a large number of wire-to-connector solder joints, and pin crimp joints.
- Simplified cabling in the belfry, with “daisy chains” of sensors.

### New Guides

- The documentation has been re-written and reorganised into a series of Guides.
- The main Build & Installation Guide is easier to follow, with more supplier part numbers and sources, and focused more on assembly and installation.
- Separate guides for basic setup of Abel, Beltower and Virtual Belfry.
- A comprehensive Technical Reference Guide covering theory and design, and less frequently used technical details.

## What Does It Look Like?

The following photograph shows a full set of module boards for a basic six-bell installation. The belfry Interface Board is top left, with the ringing room Power Board below it. On the right are six magnetic sensors.


Figure 5 – A Six Bell Board Set

This photograph shows the completed Simulator Interface module in the suggested enclosure, ready for installation in the belfry.


Figure 6 – Completed Simulator Interface Module

This photograph (approximately to scale with the Interface picture above) shows a completed sensor module ready for installation.


Figure 7 – Completed Sensor Module

## Available Modules

Designs for the following modules are currently available:

- Power Module
- Interface Module
- Magnetic Sensor Module
- Infra-Red/Generic Sensor Module
- Second PC Module
- Basic Serial Splitter Module
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

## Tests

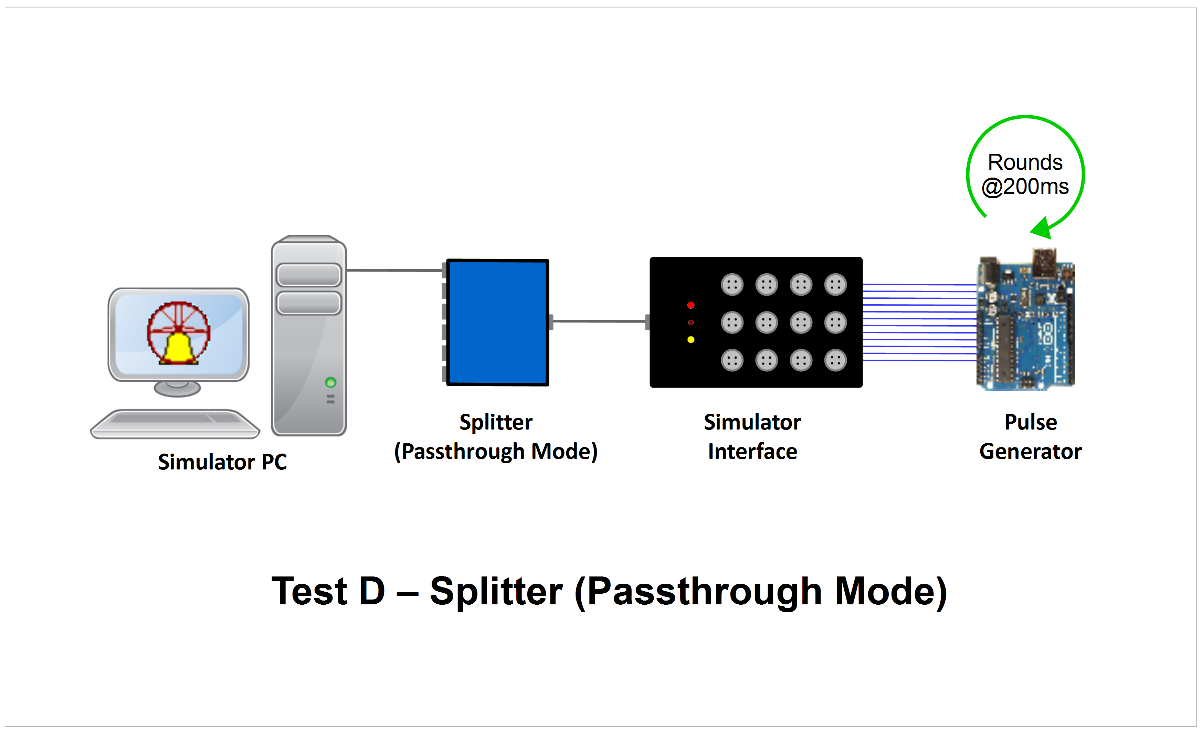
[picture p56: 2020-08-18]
docs/source/Diagrams/PNG/StrikingComp/Test D - Splittter Passthrough.png

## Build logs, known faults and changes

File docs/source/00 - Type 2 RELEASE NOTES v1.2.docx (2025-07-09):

Type 2 Liverpool Ringing Simulator

00 – RELEASE NOTES

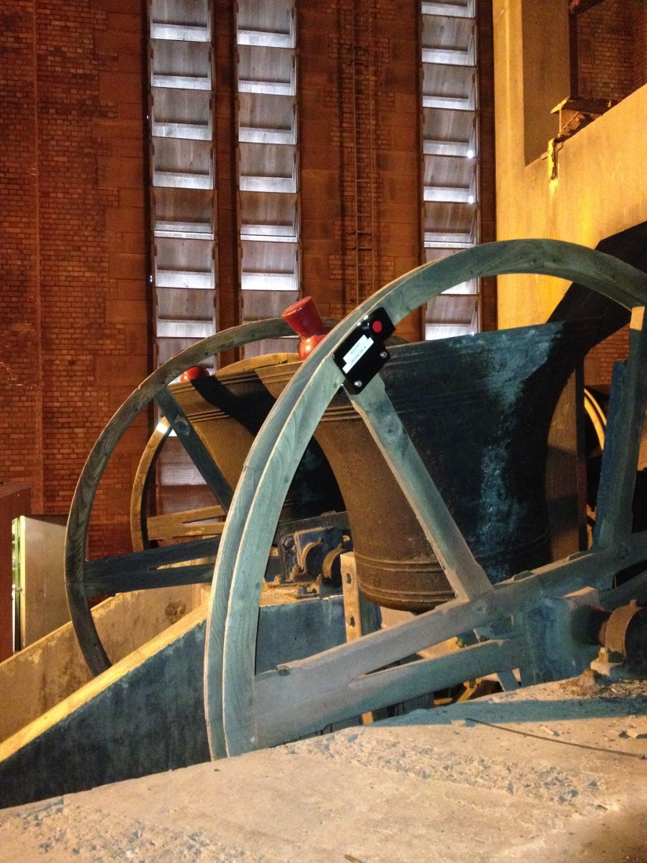
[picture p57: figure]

Author: Andrew Instone-Cowie

Date: 09 July 2025

Version: 1.2

# Document History

Version | Author | Date | Changes
1.0 | A J Instone-Cowie | 27/06/2024 | First Version.
1.1 | A J Instone-Cowie | 14/04/2025 | Type 1 – Type 2 Interface Adapter, Upcoming KiCad migration.
1.2 | A J Instone-Cowie | 09/07/2025 | A1120 Support

Copyright ©2024-25 Andrew Instone-Cowie.

Cover photograph: Prototype magnet mount, Liverpool Cathedral treble.

# Licence

This work is licensed under a Creative Commons Attribution-ShareAlike 4.0 International License.[^1]

Unless otherwise separately undertaken by the Licensor, to the extent possible, the Licensor offers the Licensed Material as-is and as-available, and makes no representations or warranties of any kind concerning the Licensed Material, whether express, implied, statutory, or other. This includes, without limitation, warranties of title, merchantability, fitness for a particular purpose, non-infringement, absence of latent or other defects, accuracy, or the presence or absence of errors, whether or not known or discoverable. Where disclaimers of warranties are not allowed in full or in part, this disclaimer may not apply to You.

To the extent possible, in no event will the Licensor be liable to You on any legal theory (including, without limitation, negligence) or otherwise for any direct, special, indirect, incidental, consequential, punitive, exemplary, or other losses, costs, expenses, or damages arising out of this Public License or use of the Licensed Material, even if the Licensor has been advised of the possibility of such losses, costs, expenses, or damages. Where a limitation of liability is not allowed in full or in part, this limitation may not apply to You.

# Attribution

The Creative Commons Attribution-ShareAlike (CC BY-SA) licence permits you to re-use this material for any purpose you wish, subject to the conditions of the licence, including providing attribution of the source.

The following is suggested as a suitable form of attribution for this document, or extracts thereof:

Type 2 Release Notes, Liverpool Ringing Simulator Project (https://www.simulators.org.uk). This document is licensed under the CC BY-SA 4.0 licence (https://creativecommons.org/licenses/by-sa/4.0/). © 2014-2025 Andrew J Instone-Cowie.

# RELEASE NOTES

## June 2024

### Documentation Updates

After several years, the entire documentation set has now been updated, part numbers checked and amended, and guides updated with the latest tested versions of Simulator Software.

### Component Costs

The price of many electronic components and other parts used in the simulator (particularly neodymium magnets) have increased dramatically over the last few years. The indicative cost of an 8-bell simulator with magneto-resistive sensors, which in 2019 would have been around £220, is now closer to £325. The Cost Estimation Tool spreadsheet has been updated with current, June 2024, prices. You may be able to reduce costs by sourcing parts from other vendors, but take particular care with low-priced semiconductors (which may not be as described), and with anything with obvious safety implications (such as power supplies).

### ATmega328P

Microchip have recently announced that the ATmega328P microcontroller is “no longer recommended for new designs”, the first step towards being discontinued. However, the microcontroller is still widely available. The Simulator Interface code will in theory work on the ATmega168P microcontroller, but changes to the build process are required for this. Contact the project if this applies to your build.

### Component Changes

Some minor component changes have been made to reflect changes in availability from vendors:

- The 5V voltage regulator previously specified has been discontinued. An equivalent replacement has been selected.
- Some IC socket part number have been changed, to reflect availability and minimum order quantity changes.
- The Screwfix part number for 20mm closed grommets has changed.

## April 2025

### Type 1 – Type 2 Interface Adapter

PCB design files and Gerbers have been provided for a simple interface adapter, which allows Type 2 sensors to be connected to a Type 1 interface, and vice-versa. As this is expected to be something of a niche requirement, the details are documented in the Technical Reference Guide, not the Build & Installation Guide.

### RIP Eagle, PCB Migration to KiCad

The fortunes of the once-popular Cadsoft Eagle PCB design tool among the hobbyist and maker community have waned over recent years, following the acquisition by AutoDesk and changes to the licensing regime. AutoDesk have announced[^2] that Eagle will cease to be available or supported as a free-standing product in June 2026.

Like many other small projects, the Liverpool Ringing Simulator Project will migrate PCB designs to the open source KiCad EDA tool over the coming months. Existing Gerber files remain valid in the interim.

## July 2025

### Magnetic Sensor Support for A1120EUA-T Hall Effect Sensor

The Type 2 simulator Magnetic Sensor Module now supports the Allegro Microsystems A1120EUA-T Hall Effect sensor as a lower cost alternative to the Honeywell 2SS52M magneto-resistive sensor. This support is based on work by Alan Griffin and Derek Livesey.

Magnetic Sensor PCB Rev E is required for the A1120EUA-T, and the updated PCB can accommodate either one A1120 device or one 2SS52M device, in right- and left-handed configurations. The details can be found in the updated Build & Installation Guide.

[^1] http://creativecommons.org/licenses/by-sa/4.0/
[^2] https://www.autodesk.com/support/technical/article/caas/sfdcarticles/sfdcarticles/Autodesk-EAGLE-Announcement-Next-steps-and-FAQ.html

Type 2 Simulator – RELEASE NOTES 1.2

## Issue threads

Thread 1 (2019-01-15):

TSR-1-2450 clearance

FLHerne, 2019-01-15:
While building an interface board using the TSR regulator that's suggested as an alternative, I've found that the physical clearance against capacitor C1 is very tight.

It can only be installed with the pins up against the far edge of the PCB holes, and even then one corner touches the capacitor.

While this should work, it's not ideal.

FLHerne, 2019-01-15:
Rev. C, 09/2018

Simulators, 2019-01-15:
Agreed, error introduced in Rev C. Workaround #1, if your deployment permits, use a conventional voltage regulator, perhaps with a small heatsink. That should be adequate for almost all deployments except for high current demands e.g. where there are large numbers of optical sensors. Workaround #2, contact me via the website form and I can send you a surplus Rev A board, which has better clearance. Permanent fix will follow in an updated board design.

FLHerne, 2019-01-15:
Thanks for the quick response.

It does just barely fit, and since neither component body is conductive I don't think that them touching will cause a functional problem; it just looks rather inelegant...

I do now have the board powered on and programmed, it seems to be working fine.

Should I need further interface boards beyond the pair I already have parts for, I shall probably use a conventional regulator.

Closed 2019-01-20.

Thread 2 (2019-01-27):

RJHSE-5080-02 no longer stocked by Farnell

Simulators, 2019-01-27:
The 2-port RJ45 connector used on the magneto-resistive and generic sensor boards is no longer available from Farnell.

Simulators, 2019-01-30:
AMP TE Connectivity 5406526-1 (Farnell 2452587) is a direct replacement. Documentation update to follow.

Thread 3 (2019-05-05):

ATmega328p RC oscillator calibration

Simulators, 2019-05-05:
The factory calibration accuracy of the ATmega328p internal 8MHz RC oscillator may be sufficiently off-nominal to result in garbled data on the interface serial port for all PCB versions up to and including Revision D. To date this has been observed on only one ATmega328p device, and the diagnosis confirmed by adjusting the oscillator frequency. Adjustment involves changing the value of the OSCCAL register, and requires an oscilloscope or frequency meter. A workaround for builders with suitable equipment will be posted to this issue soon. A full fix is under investigation.

Simulators, 2019-05-06:
**Symptom:**

Garbled data on the serial port of the Type 2 Simulator Interface, especially when displaying settings with the "?" CLI option. May affect any version of the interface up to PCB Revision D.

**Workaround 1**

- Try a different ATmega328p MCU. The problem has only been observed with a device with an outlier factory calibration setting close to the upper limit defined in the data sheet.

**Workaround 2**

- Calibrate the RC oscillator using a calibrated oscilloscope or frequency meter.

- **Disconnect all sensors from the interface.**

- Assuming you have at least some working serial data, retrieve the factory calibration value from the OSCCAL register, by uploading and running a sketch containing just the following in `setup()`, with nothing in `loop()`.

```
Serial.begin(` 2400, SERIAL_8N1 );
Serial.print("OSCCAL` = ");
Serial.println(OSCCAL);`
```

- In `boards.txt`, change the low fuse value from E2 to A2, then reapply the fuses to the interface by going through the "burn bootloader" steps as described in the main documentation. This routes the system clock to physical pin 14 of the ATmega328p (which is usually used for sensor channel 3).

```
type2.bootloader.low_fuses=0xA2
```

- Measure the frequency on pin 14 of the ATmega328p. Pin 14 is the bottom left pin of the DIP package.

- Refer to the ATmega328p data sheet for details of setting the OSCCAL value, then determine the optimal value for OSCCAL by adding to the sketch above similar to the following in `loop()`. Start by trying a  range of values around the factory value, for example if the factory value is 50:

```
for( int i=40; i<60; i++ )
{
   OSCCAL = i;
   Serial.print( "OSCCAL = " );
   Serial.println( i );
   delay( 5000 );
}
```

- Monitor the frequency on pin 14 as the value of OSCCAL changes, using an oscilloscope or frequency meter, and note the value which gives a clock output closest to 8.0MHz. The serial port text should be legible.

- Setting the OSCCAL register does not change the factory calibration value, so the optimal value should be set in software every time the interface boots. In the main interface firmware code, set the optimal OSCCAL value determined above by adding a new first line in `setup()`. For example if the optimal value is 57, set OSCCAL as follows:

```
void setup() {
   OSCCAL = 57;
   ...
```

- Set the low fuse value back to 0xE2 in `boards.txt`, then go through both the "burn bootloader" and "firmware upload" steps as described in the main documentation. **NB: Do not reconnect the sensors until the low fuse value has been reset on the interface.**

A fix for this problem is under evaluation.

Simulators, 2019-06-09:
Further investigation has shown that the issue was caused by combination of factors (an outlier - but within manufacturer's tolerance - oscillator frequency, a marginal power supply, and a failing PC serial port). The interface design has been updated to Rev E, with an 8MHz ceramic resonator clock source, which should improve reliability in marginal conditions.

Closed 2019-06-09.

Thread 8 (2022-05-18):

JLCPCB break-off tabs too narrow

Simulators, 2022-05-18:
A builder reports that JLCPCB are rejecting panelized power and sensor boards with 2.5mm stamp hole break-off tabs.

Simulators, 2022-05-18:
Work-in-progress updated Gerbers and panel files can be found in the JLCPCB branch.

Closed 2022-07-08.

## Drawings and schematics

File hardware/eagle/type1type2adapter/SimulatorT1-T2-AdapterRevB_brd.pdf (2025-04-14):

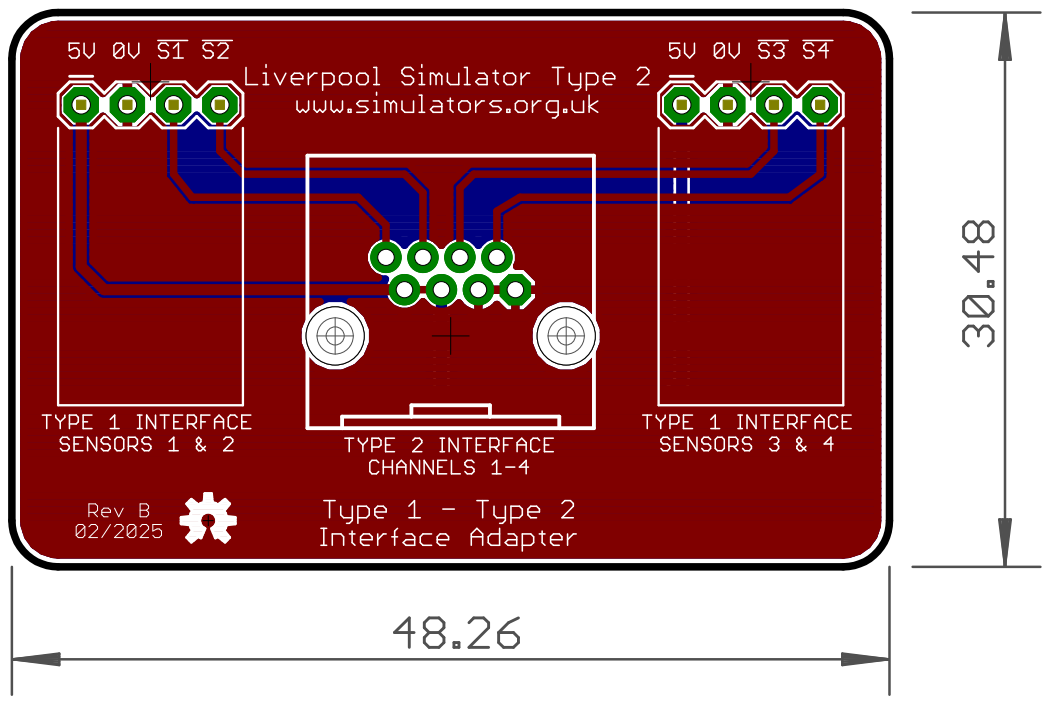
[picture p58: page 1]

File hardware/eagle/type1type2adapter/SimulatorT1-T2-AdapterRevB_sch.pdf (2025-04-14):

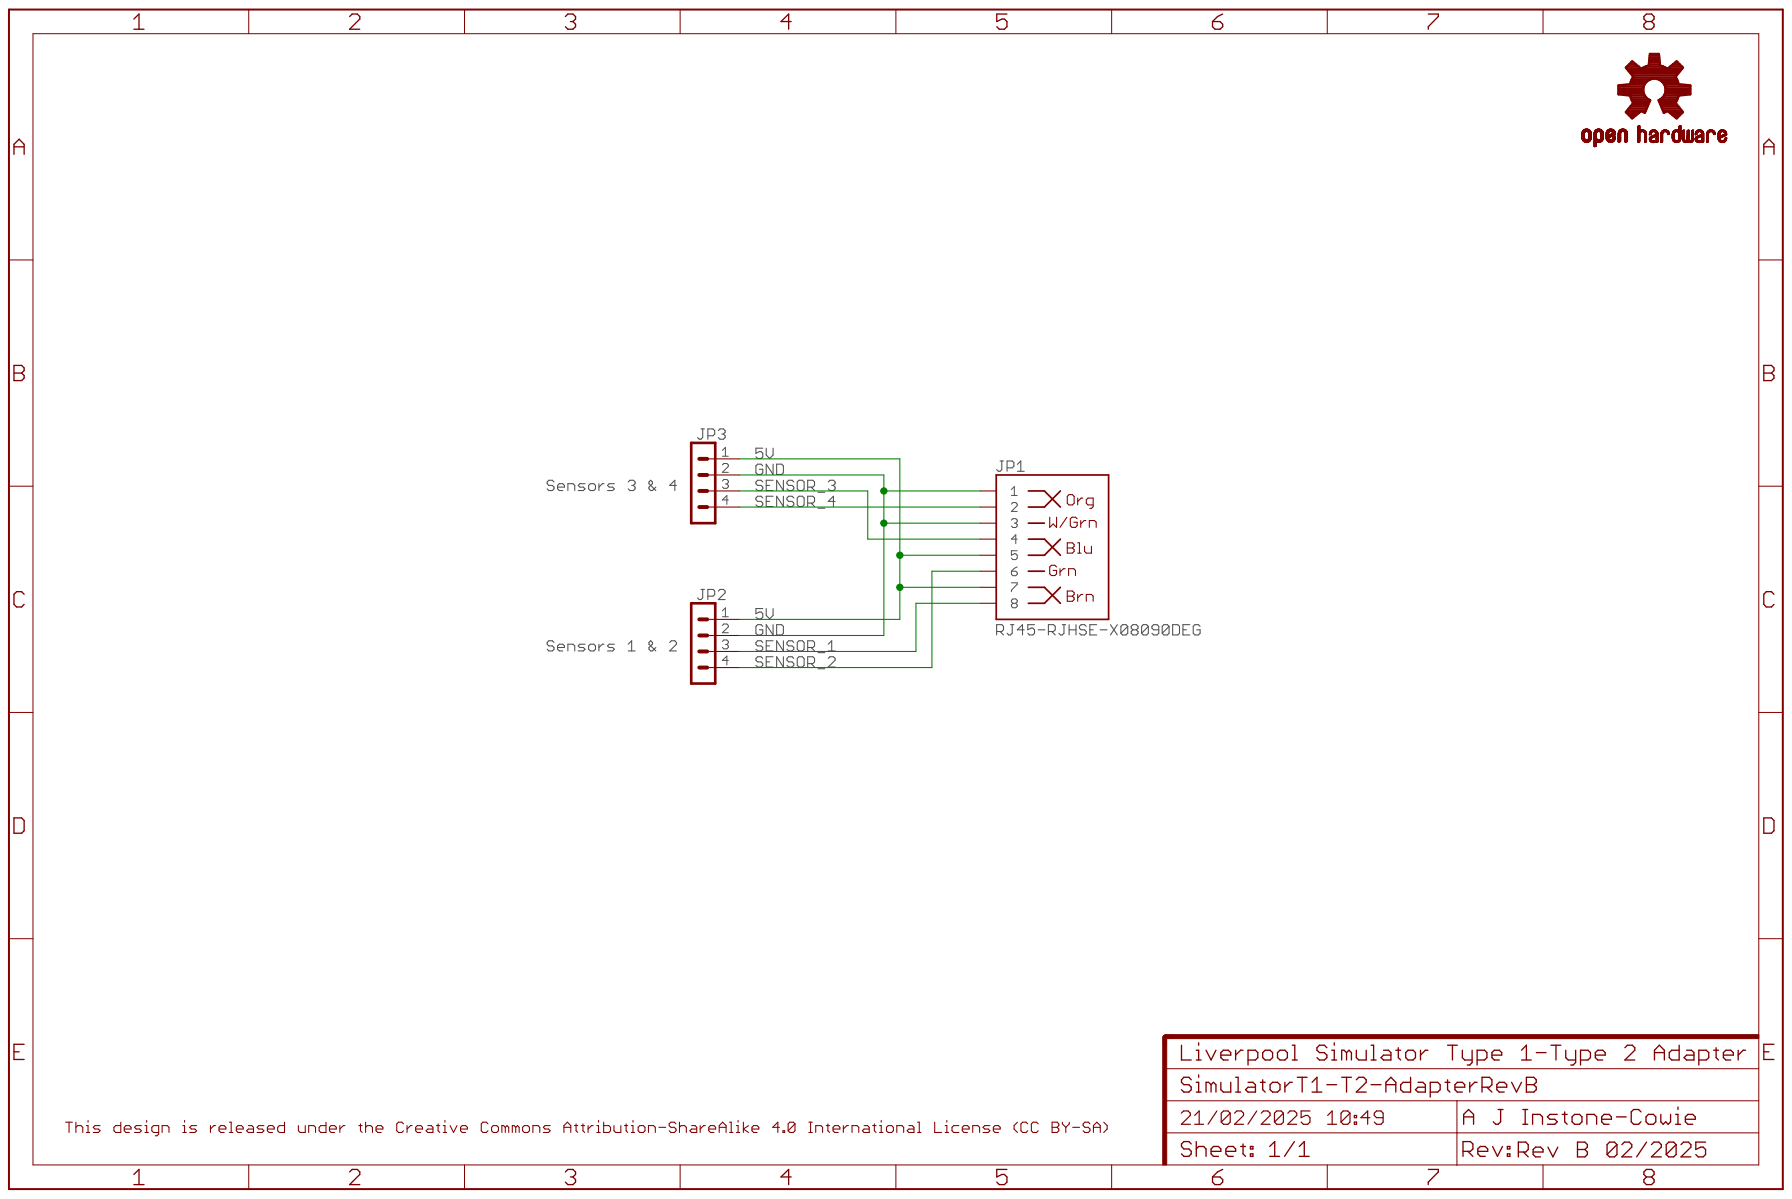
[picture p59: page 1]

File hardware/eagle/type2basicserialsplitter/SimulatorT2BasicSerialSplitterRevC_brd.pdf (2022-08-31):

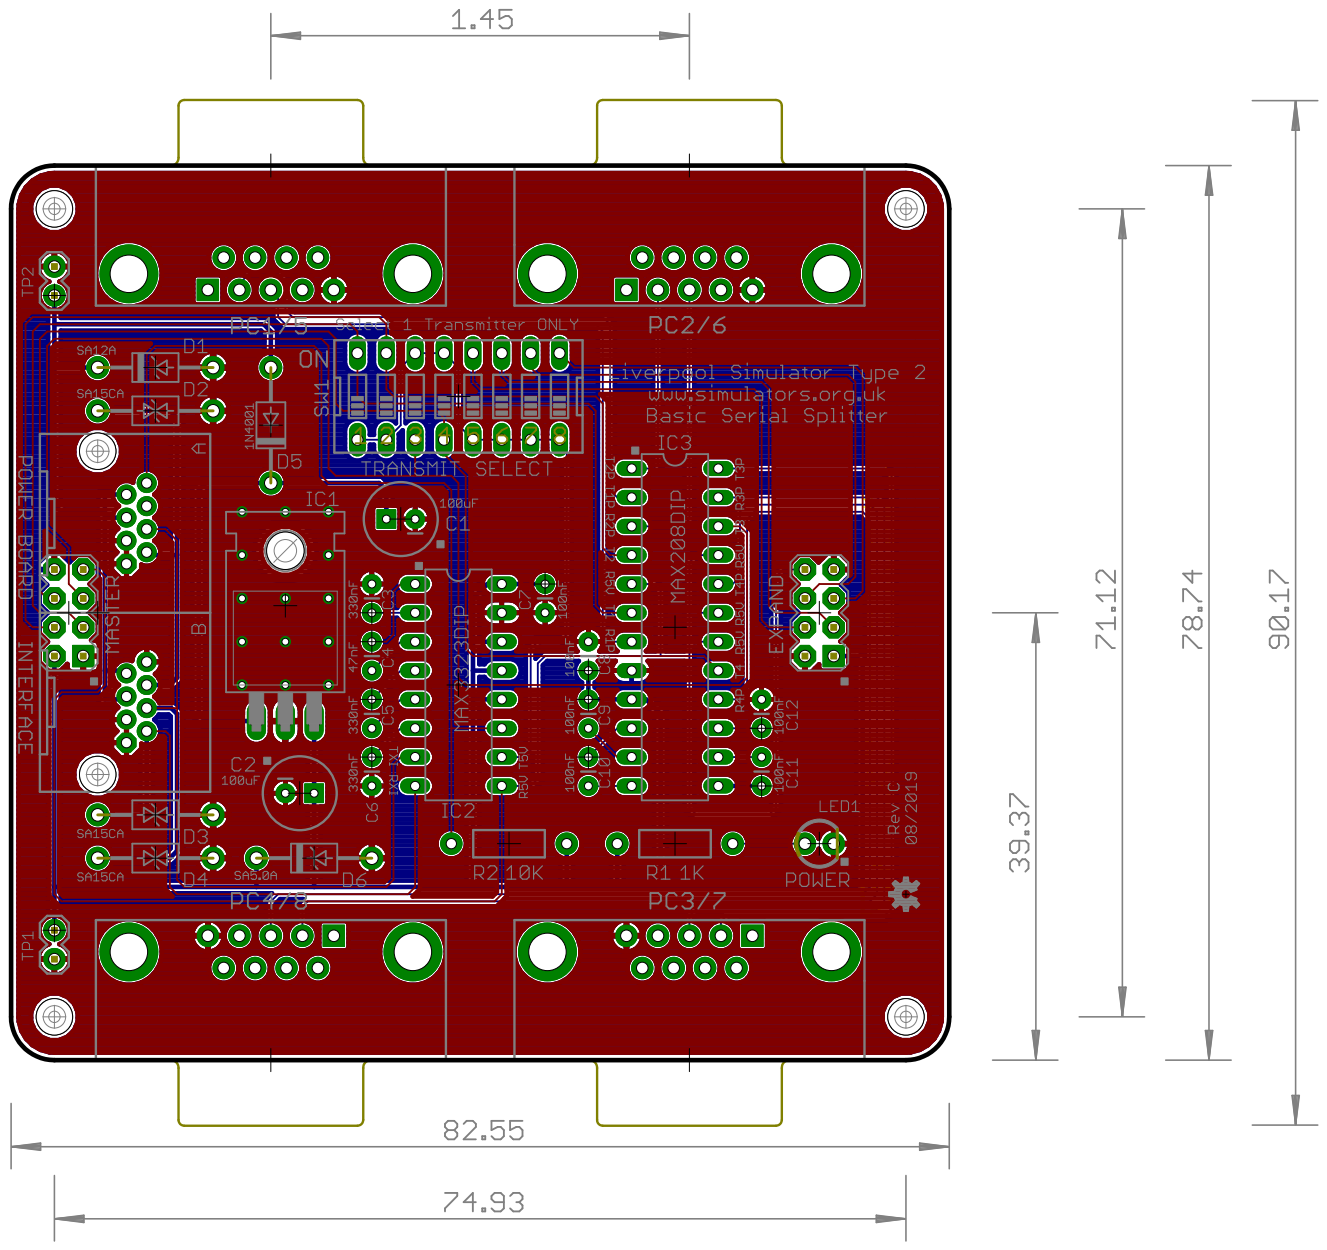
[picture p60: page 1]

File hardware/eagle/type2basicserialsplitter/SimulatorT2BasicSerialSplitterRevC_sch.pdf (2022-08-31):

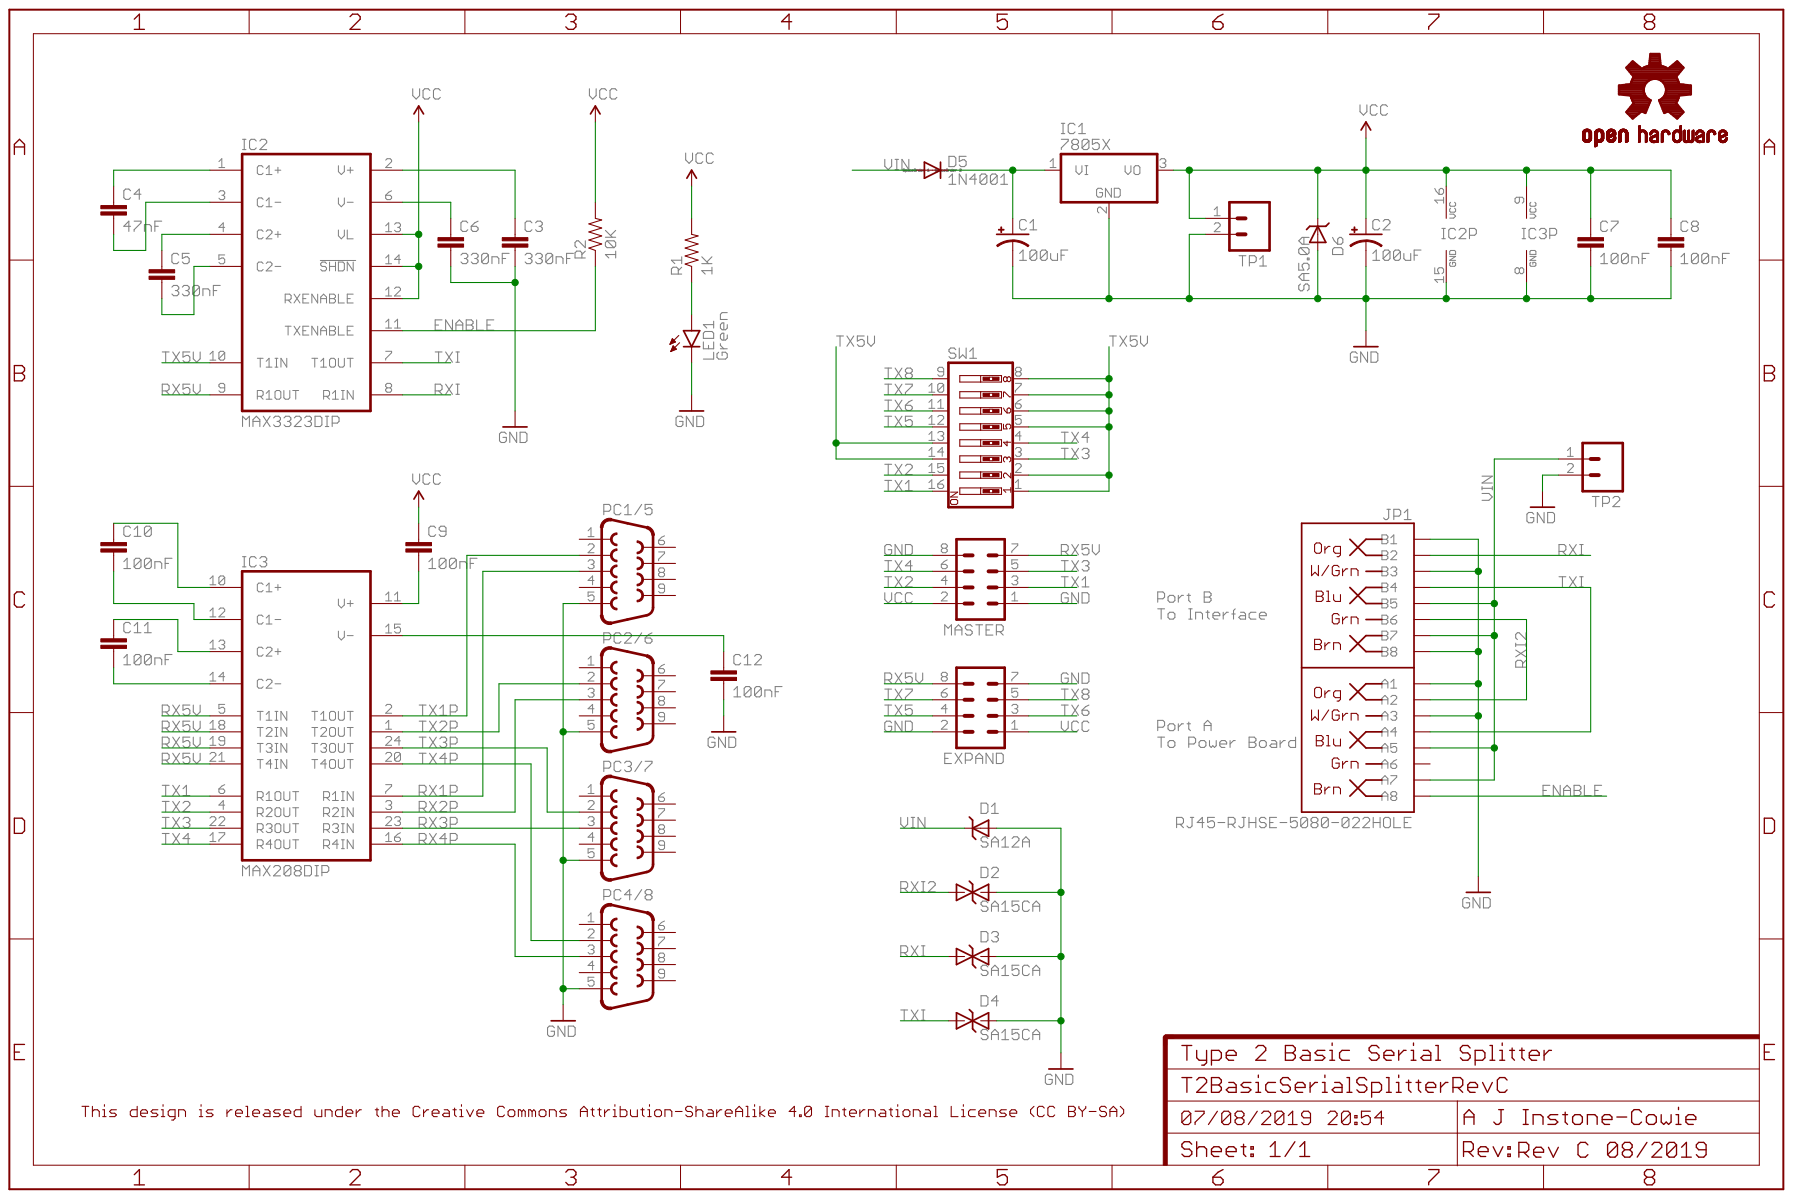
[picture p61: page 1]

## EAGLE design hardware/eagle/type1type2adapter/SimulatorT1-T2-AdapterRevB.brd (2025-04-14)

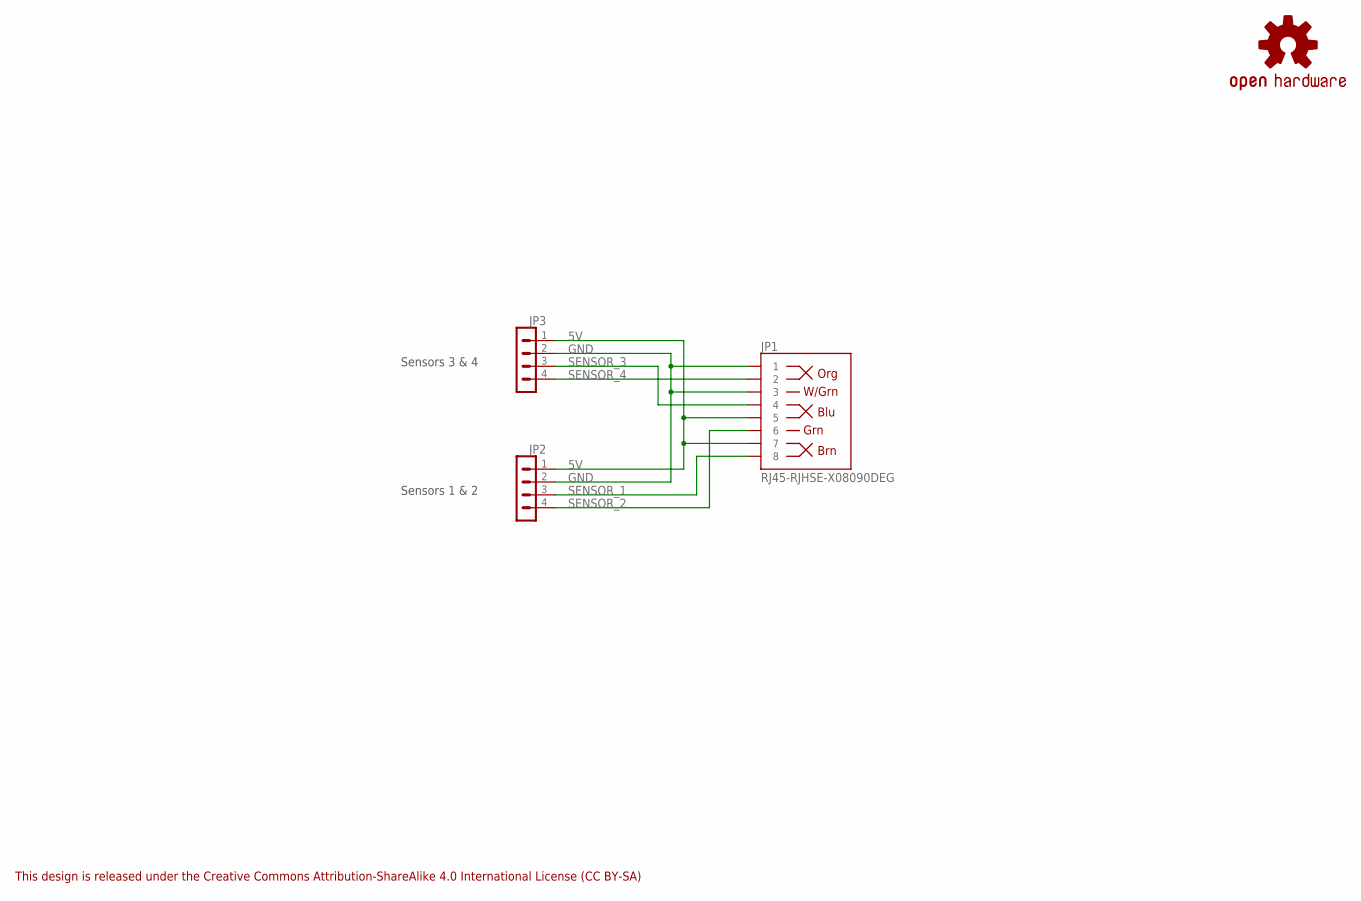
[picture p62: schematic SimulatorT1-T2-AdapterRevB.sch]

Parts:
JP1: RJ45-RJHSE-X08090DEG; RJ45-RJHSE-5080
JP2, JP3: MOLEX_KK_254_4WAY
LOGO1: OSHW-LOGOS; OSHW-LOGO-S

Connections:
5V: JP1.5, JP1.7, JP2.1, JP3.1
GND: JP1.1, JP1.3, JP2.2, JP3.2
SENSOR_1: JP1.8, JP2.3
SENSOR_2: JP1.6, JP2.4
SENSOR_3: JP1.4, JP3.3
SENSOR_4: JP1.2, JP3.4

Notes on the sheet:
This design is released under the Creative Commons Attribution-ShareAlike 4.0 International License (CC BY-SA)
Sensors 1 & 2
Sensors 3 & 4

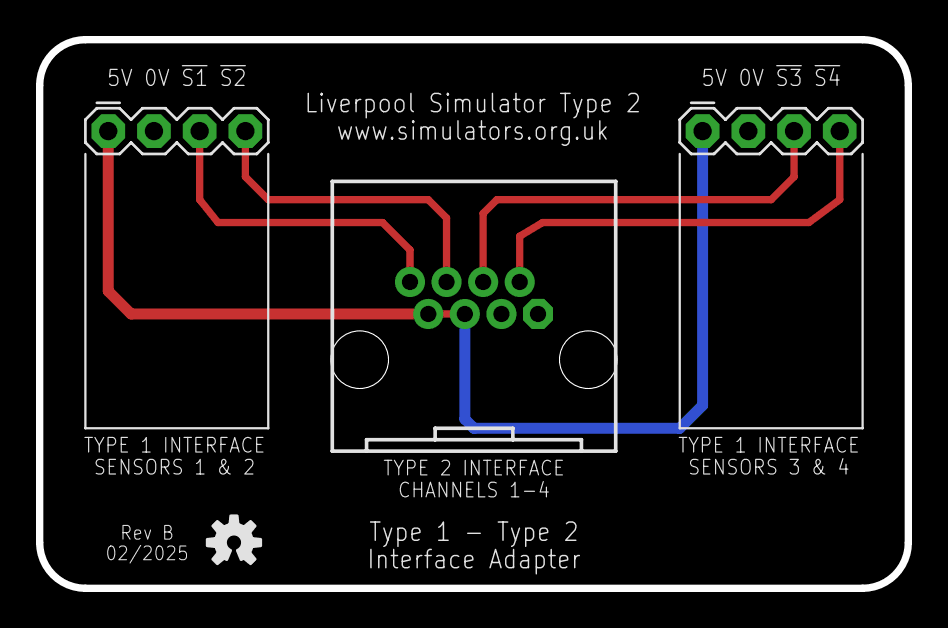
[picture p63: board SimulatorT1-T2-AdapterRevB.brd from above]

Board: 2 copper layers, 48.3 x 30.5 mm, 5 parts (1 on the bottom side), 6 nets.

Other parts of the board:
U$1: WARNING_TRIANGLE_TPLACE

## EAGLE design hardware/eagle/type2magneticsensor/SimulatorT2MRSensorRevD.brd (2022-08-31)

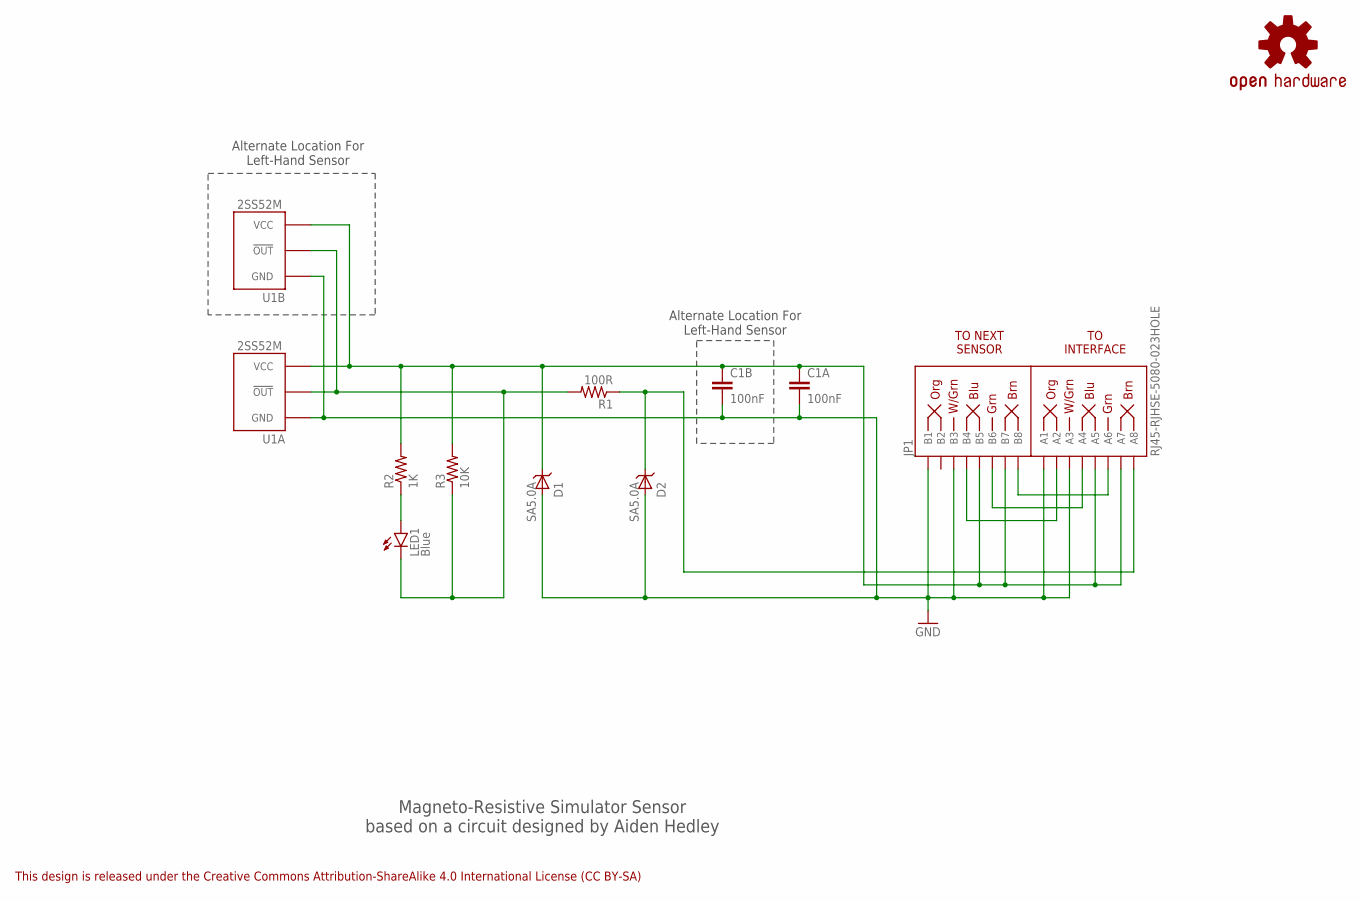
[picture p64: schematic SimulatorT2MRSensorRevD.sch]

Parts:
C1A, C1B: 100nF; CAP-PTH-SMALL
D1, D2: SA5.0A; DO41_TVS_UNI
JP1: RJ45-RJHSE-5080-023HOLE; RJ45-RJHSE-5080-02-3HOLE
LED1: Blue; LED3MM
LOGO1: OSHW-LOGOS; OSHW-LOGO-S
R1: 100R; AXIAL-0.4
R2: 1K; AXIAL-0.4
R3: 10K; AXIAL-0.4
U1A, U1B: 2SS52MOFFSET; 2SS52M_FLAT_OFFSET

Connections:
!OUT!: D2.CATHODE, JP1.A8, R1.P$1 (1)
B2: JP1.A6, JP1.B8
B3: JP1.A4, JP1.B6
B4: JP1.A2, JP1.B4
GND: C1A.2, C1B.2, D1.ANODE, D2.ANODE, JP1.A1, JP1.A3, JP1.B1, JP1.B3, U1A.P$1 (GND), U1B.P$1 (GND)
LED: LED1.A, R2.P$1 (1)
SIG: LED1.K (C), R1.P$2 (2), R3.P$1 (1), U1A.P$2 (!OUT!), U1B.P$2 (!OUT!)
VCC: C1A.1, C1B.1, D1.CATHODE, JP1.A5, JP1.A7, JP1.B5, JP1.B7, R2.P$2 (2), R3.P$2 (2), U1A.P$3 (VCC), U1B.P$3 (VCC)

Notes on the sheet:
This design is released under the Creative Commons Attribution-ShareAlike 4.0 International License (CC BY-SA)
TO INTERFACE
TO NEXT SENSOR
Magneto-Resistive Simulator Sensor based on a circuit designed by Aiden Hedley
Alternate Location For Left-Hand Sensor

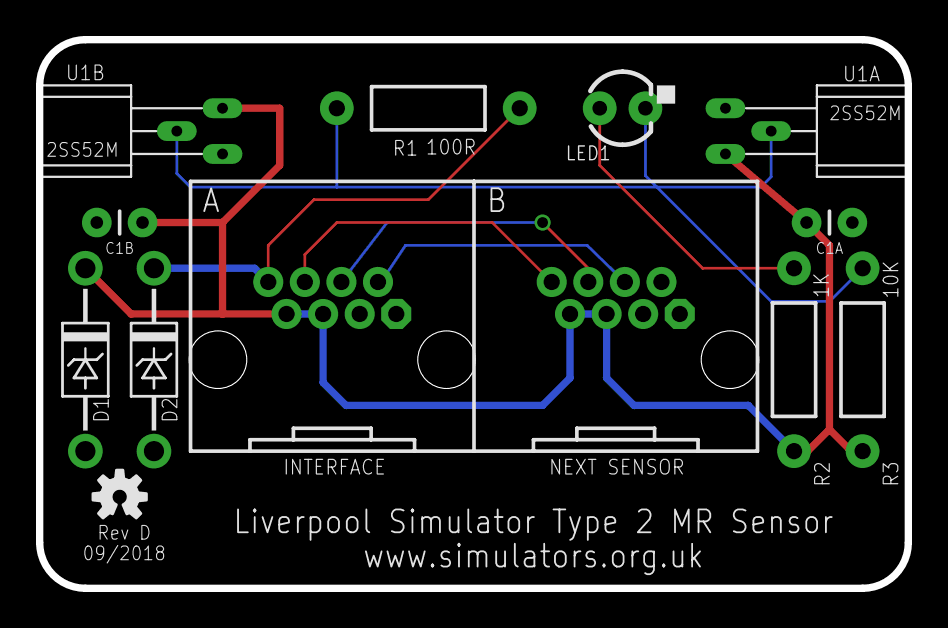
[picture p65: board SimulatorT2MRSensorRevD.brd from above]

Board: 2 copper layers, 48.3 x 30.5 mm, 13 parts (1 on the bottom side), 8 nets.

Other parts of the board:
U$1: WARNING_TRIANGLE_TPLACE

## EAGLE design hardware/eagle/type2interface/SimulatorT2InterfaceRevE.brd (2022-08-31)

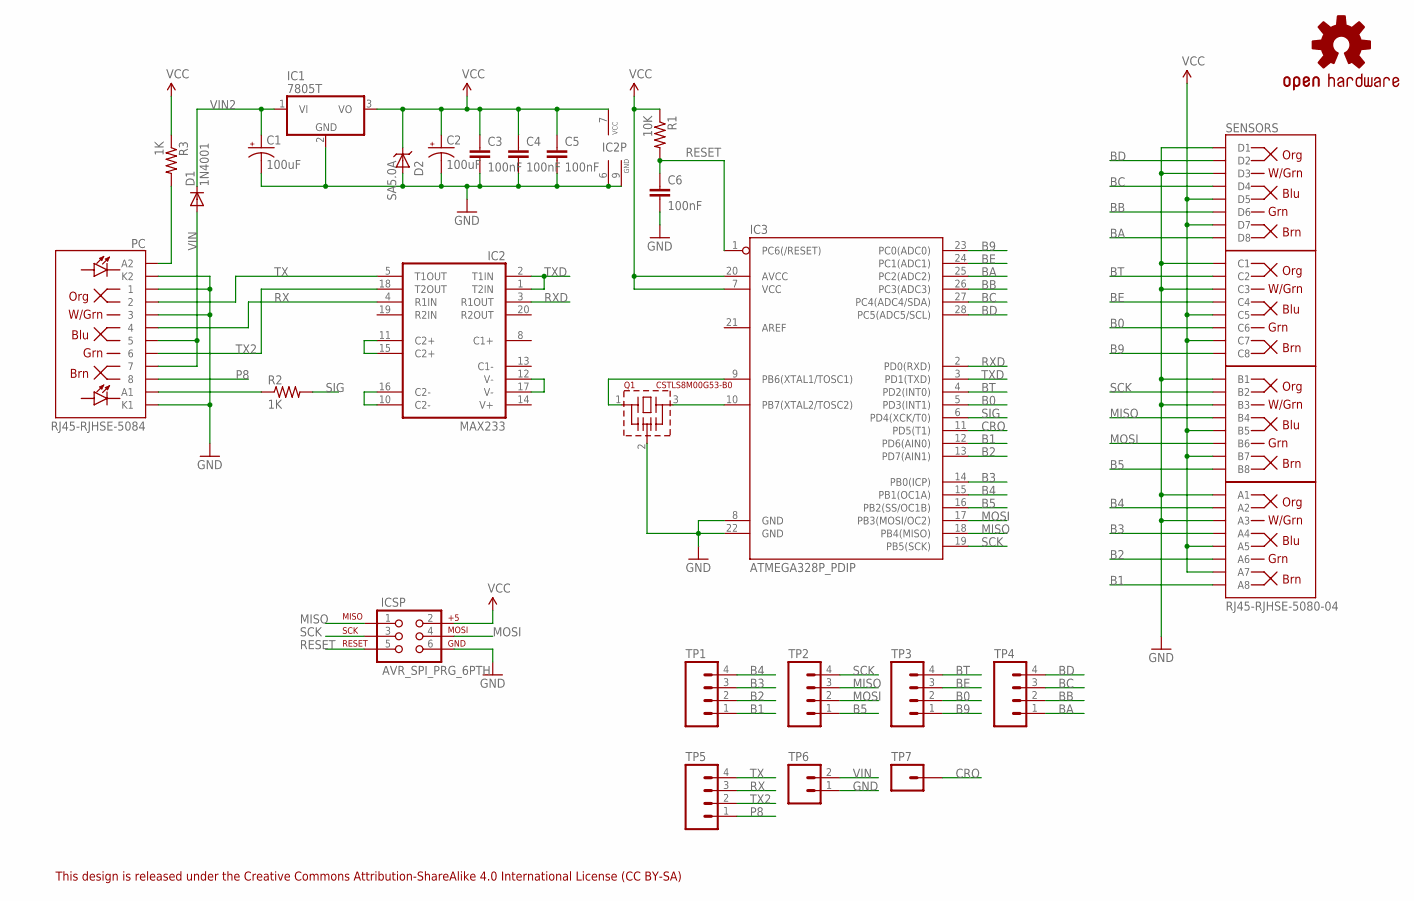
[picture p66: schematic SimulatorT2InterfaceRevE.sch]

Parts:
C1, C2: 100uF; CPOL-RADIAL-100UF-25V
C3, C4, C5, C6: 100nF; CAP-PTH-SMALL
D1: 1N4001; DO41_DIODE
D2: SA5.0A; DO41_TVS_UNI
IC1: 7805T; TO220H+TSR
IC2: MAX233; DIL20
IC3: ATMEGA328P_PDIP; DIL28-3
ICSP: AVR_SPI_PRG_6PTH; 2X3
LOGO1: OSHW-LOGOS; OSHW-LOGO-S
PC: RJ45-RJHSE-5084
Q1: CSTLS8M00G53-B0; CSTLS_G8
R1: 10K; AXIAL-0.4
R2, R3: 1K; AXIAL-0.4
SENSORS: RJ45-RJHSE-5080-04
TP1, TP2, TP3, TP4, TP5: M04PTH; 1X04
TP6: M02PTH; 1X02
TP7: M01PTH; 1X01

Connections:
B0: IC3.5 (PD3(INT1)), SENSORS.C6, TP3.2
B1: IC3.12 (PD6(AIN0)), SENSORS.A8, TP1.1
B2: IC3.13 (PD7(AIN1)), SENSORS.A6, TP1.2
B3: IC3.14 (PB0(ICP)), SENSORS.A4, TP1.3
B4: IC3.15 (PB1(OC1A)), SENSORS.A2, TP1.4
B5: IC3.16 (PB2(SS/OC1B)), SENSORS.B8, TP2.1
B9: IC3.23 (PC0(ADC0)), SENSORS.C8, TP3.1
BA: IC3.25 (PC2(ADC2)), SENSORS.D8, TP4.1
BB: IC3.26 (PC3(ADC3)), SENSORS.D6, TP4.2
BC: IC3.27 (PC4(ADC4/SDA)), SENSORS.D4, TP4.3
BD: IC3.28 (PC5(ADC5/SCL)), SENSORS.D2, TP4.4
BE: IC3.24 (PC1(ADC1)), SENSORS.C4, TP3.3
BT: IC3.4 (PD2(INT0)), SENSORS.C2, TP3.4
CRO: IC3.11 (PD5(T1)), TP7.1
GND: C1.2 (-), C2.2 (-), C3.2, C4.2, C5.2, C6.2, D2.ANODE, IC1.2 (GND), IC2.6 (GND), IC2.9 (GND), IC3.8 (GND), IC3.22 (GND), ICSP.6, PC.1, PC.3, PC.K1, PC.K2, Q1.2 (GND), SENSORS.A1, SENSORS.A3, SENSORS.B1, SENSORS.B3, SENSORS.C1, SENSORS.C3, SENSORS.D1, SENSORS.D3, TP6.1
LED1: PC.A1, R2.P$1 (1)
LED2: PC.A2, R3.P$2 (2)
MISO: IC3.18 (PB4(MISO)), ICSP.1, SENSORS.B4, TP2.3
MOSI: IC3.17 (PB3(MOSI/OC2)), ICSP.4, SENSORS.B6, TP2.2
unnamed: IC2.10 (C2-), IC2.16 (C2-)
unnamed: IC2.11 (C2+), IC2.15 (C2+)
unnamed: IC2.12 (V-), IC2.17 (V-)
OSC1: IC3.9 (PB6(XTAL1/TOSC1)), Q1.1
OSC2: IC3.10 (PB7(XTAL2/TOSC2)), Q1.3
P8: PC.8, TP5.1
RESET: C6.1, IC3.1 (PC6(/RESET)), ICSP.5, R1.P$2 (2)
RX: IC2.4 (R1IN), PC.4, TP5.3
RXD: IC2.3 (R1OUT), IC3.2 (PD0(RXD))
SCK: IC3.19 (PB5(SCK)), ICSP.3, SENSORS.B2, TP2.4
SIG: IC3.6 (PD4(XCK/T0)), R2.P$2 (2)
TX: IC2.5 (T1OUT), PC.2, TP5.4
TX2: IC2.18 (T2OUT), PC.6, TP5.2
TXD: IC2.1 (T2IN), IC2.2 (T1IN), IC3.3 (PD1(TXD))
VCC: C2.1 (+), C3.1, C4.1, C5.1, D2.CATHODE, IC1.3 (VO), IC2.7 (VCC), IC3.7 (VCC), IC3.20 (AVCC), ICSP.2, R1.P$1 (1), R3.P$1 (1), SENSORS.A5, SENSORS.A7, SENSORS.B5, SENSORS.B7, SENSORS.C5, SENSORS.C7, SENSORS.D5, SENSORS.D7
VIN: D1.A, PC.5, PC.7, TP6.2
VIN2: C1.1 (+), D1.C, IC1.1 (VI)

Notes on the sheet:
This design is released under the Creative Commons Attribution-ShareAlike 4.0 International License (CC BY-SA)

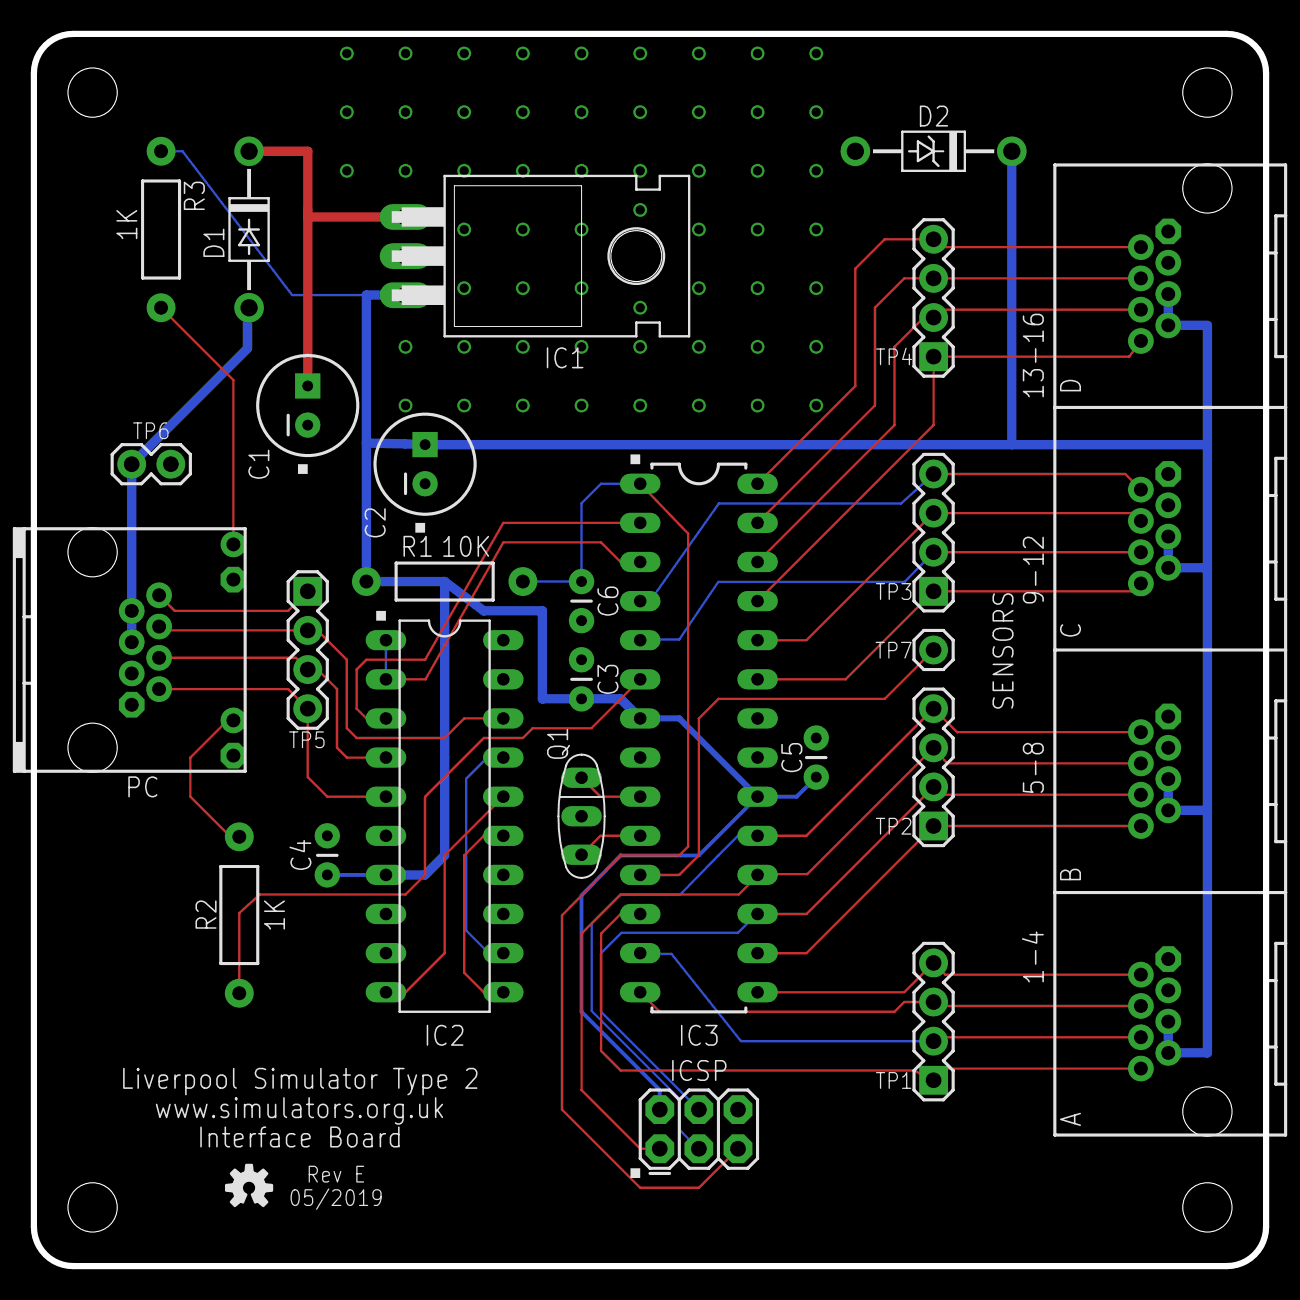
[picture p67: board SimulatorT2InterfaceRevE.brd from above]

Board: 2 copper layers, 80.0 x 80.0 mm, 27 parts (1 on the bottom side), 36 nets.

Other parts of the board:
U$1: WARNING_TRIANGLE_TPLACE

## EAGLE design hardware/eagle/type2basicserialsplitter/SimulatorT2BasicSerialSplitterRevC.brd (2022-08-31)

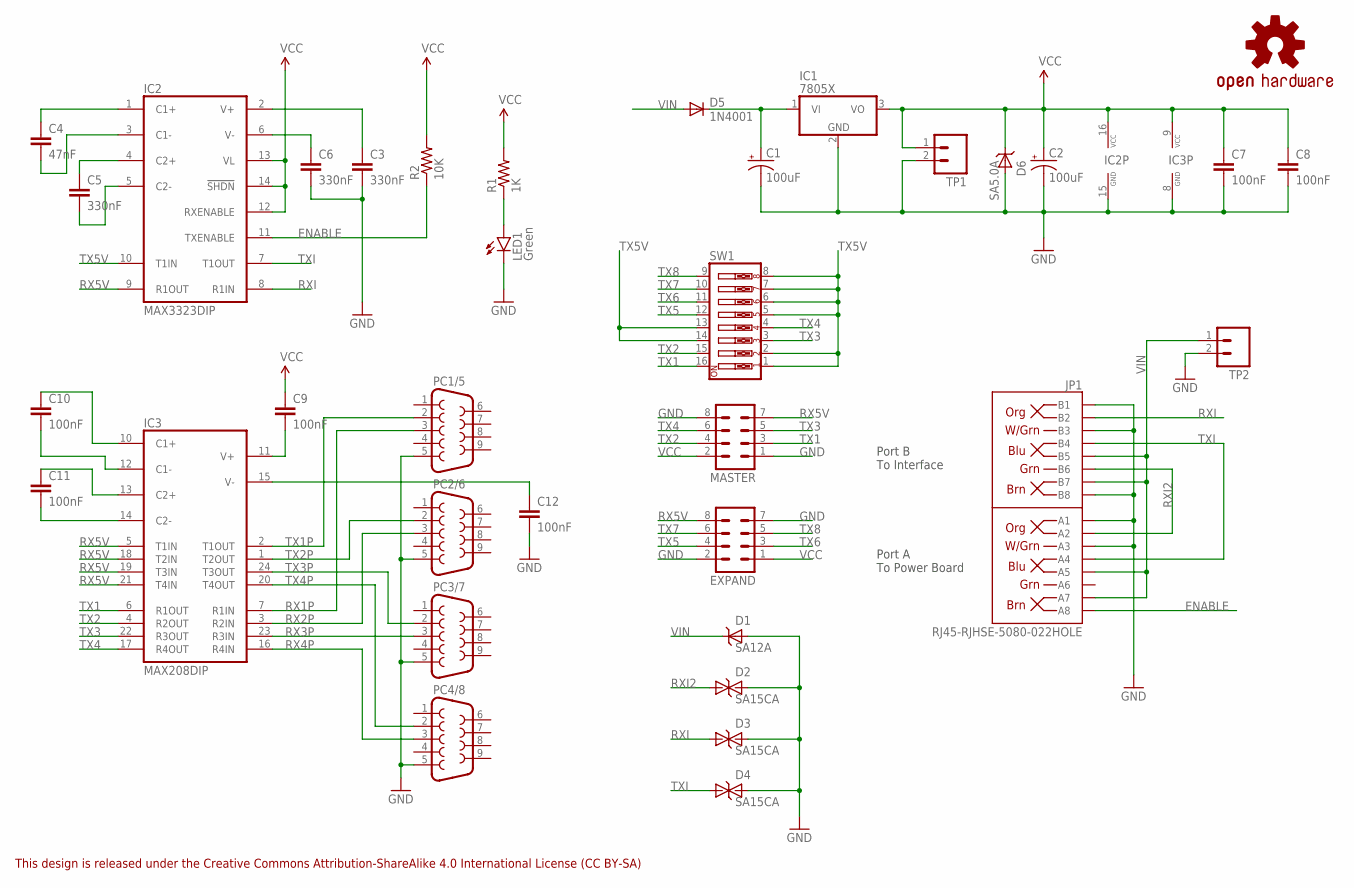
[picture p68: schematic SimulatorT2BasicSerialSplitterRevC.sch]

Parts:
C1, C2: 100uF; CPOL-RADIAL-100UF-25V
C3, C5, C6: 330nF; CAP-PTH-SMALL
C4: 47nF; CAP-PTH-SMALL
C7, C8, C9, C10, C11, C12: 100nF; CAP-PTH-SMALL
D1: SA12A; DO41_TVS_UNI
D2, D3, D4: SA15CA; DO41_TVS_BI
D5: 1N4001; DO41_DIODE
D6: SA5.0A; DO41_TVS_UNI
EXPAND: M04X2POL; 2X4-POLARISED
IC1: 7805X; TO220H
IC2: MAX3323DIP; DIL16
IC3: MAX208DIP; DIL24
JP1: RJ45-RJHSE-5080-022HOLE; RJ45-RJHSE-5080-02
LED1: Green; LED3MM_LARGEHOLES
LOGO1: OSHW-LOGOS; OSHW-LOGO-S
MASTER: M04X2POL; 2X4-POLARISED
PC1/5, PC2/6, PC3/7, PC4/8: DB9-CONNECTOR-PCBFEMALE; MULTICOMP-DB9-FEMALE-PCB-90DEG
R1: 1K; AXIAL-0.4
R2: 10K; AXIAL-0.4
SW1: SW_DIP-8; DIPSWITCH-08
TP1, TP2: M02PTH; 1X02

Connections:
ENABLE: IC2.11 (TXENABLE), JP1.A8, R2.P$1 (1)
GND: C1.2 (-), C2.2 (-), C3.2, C6.2, C7.2, C8.2, C12.2, D1.ANODE, D2.C, D3.C, D4.C, D6.ANODE, EXPAND.2, EXPAND.7, IC1.2 (GND), IC2.15 (GND), IC3.8 (GND), JP1.A1, JP1.A3, JP1.B1, JP1.B3, JP1.B8, LED1.K (C), MASTER.1, MASTER.8, PC1/5.5, PC2/6.5, PC3/7.5, PC4/8.5, TP1.2, TP2.2
unnamed: C3.1, IC2.2 (V+)
unnamed: C6.1, IC2.6 (V-)
unnamed: C5.1, IC2.4 (C2+)
unnamed: C5.2, IC2.5 (C2-)
unnamed: C4.1, IC2.1 (C1+)
unnamed: C4.2, IC2.3 (C1-)
unnamed: C11.2, IC3.14 (C2-)
unnamed: C11.1, IC3.13 (C2+)
unnamed: C10.1, IC3.10 (C1+)
unnamed: C10.2, IC3.12 (C1-)
unnamed: C12.1, IC3.15 (V-)
unnamed: C9.2, IC3.11 (V+)
POWER_LED: LED1.A, R1.P$1 (1)
RX1P: IC3.7 (R1IN), PC1/5.3
RX2P: IC3.3 (R2IN), PC2/6.3
RX3P: IC3.23 (R3IN), PC3/7.3
RX4P: IC3.16 (R4IN), PC4/8.3
RX5V: EXPAND.8, IC2.9 (R1OUT), IC3.5 (T1IN), IC3.18 (T2IN), IC3.19 (T3IN), IC3.21 (T4IN), MASTER.7
RXI: D3.A, IC2.8 (R1IN), JP1.B2
RXI2: D2.A, JP1.A2, JP1.B6
TX1: IC3.6 (R1OUT), MASTER.3, SW1.16
TX1P: IC3.2 (T1OUT), PC1/5.2
TX2: IC3.4 (R2OUT), MASTER.4, SW1.15
TX2P: IC3.1 (T2OUT), PC2/6.2
TX3: IC3.22 (R3OUT), MASTER.5, SW1.3
TX3P: IC3.24 (T3OUT), PC3/7.2
TX4: IC3.17 (R4OUT), MASTER.6, SW1.4
TX4P: IC3.20 (T4OUT), PC4/8.2
TX5: EXPAND.4, SW1.12
TX5V: IC2.10 (T1IN), SW1.1, SW1.2, SW1.5, SW1.6, SW1.7, SW1.8, SW1.13, SW1.14
TX6: EXPAND.3, SW1.11
TX7: EXPAND.6, SW1.10
TX8: EXPAND.5, SW1.9
TXI: D4.A, IC2.7 (T1OUT), JP1.A4, JP1.B4
VCC: C2.1 (+), C7.1, C8.1, C9.1, D6.CATHODE, EXPAND.1, IC1.3 (VO), IC2.12 (RXENABLE), IC2.13 (VL), IC2.14 (!SHDN), IC2.16 (VCC), IC3.9 (VCC), MASTER.2, R1.P$2 (2), R2.P$2 (2), TP1.1
VIN: D1.CATHODE, D5.A, JP1.A5, JP1.A7, JP1.B5, JP1.B7, TP2.1
VREG_IN: C1.1 (+), D5.C, IC1.1 (VI)

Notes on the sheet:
This design is released under the Creative Commons Attribution-ShareAlike 4.0 International License (CC BY-SA)
Port A To Power Board
Port B To Interface

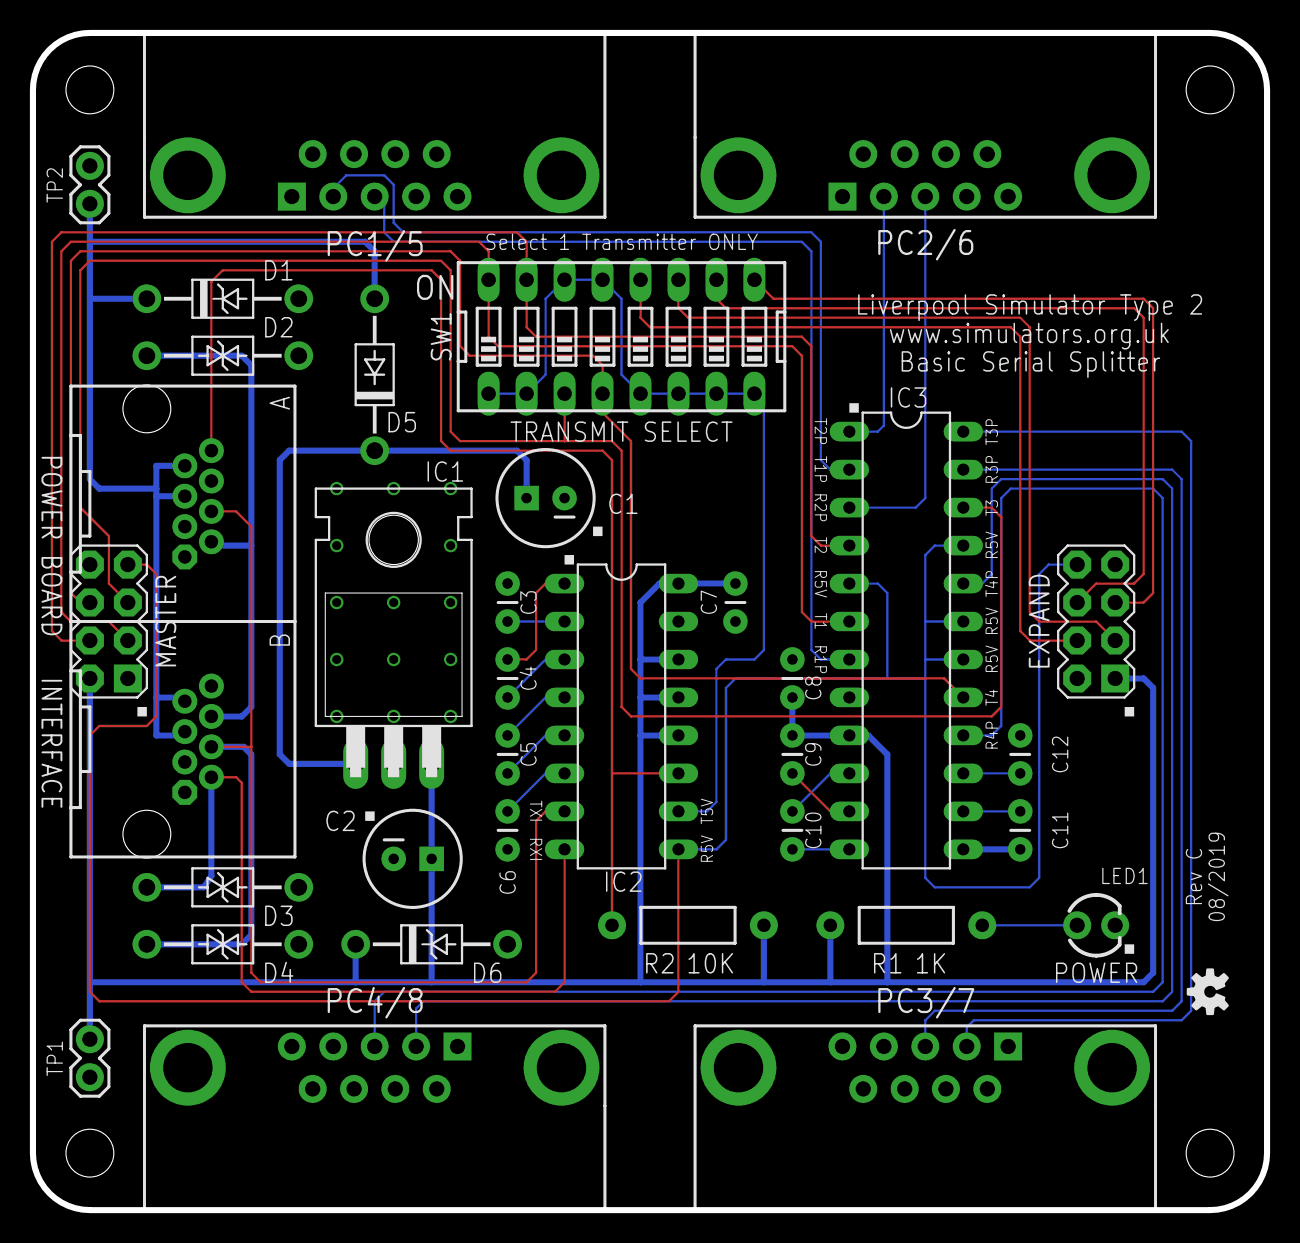
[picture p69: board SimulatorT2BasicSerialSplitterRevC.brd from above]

Board: 2 copper layers, 82.5 x 78.7 mm, 36 parts (1 on the bottom side), 39 nets.

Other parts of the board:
U$1: WARNING_TRIANGLE_TPLACE

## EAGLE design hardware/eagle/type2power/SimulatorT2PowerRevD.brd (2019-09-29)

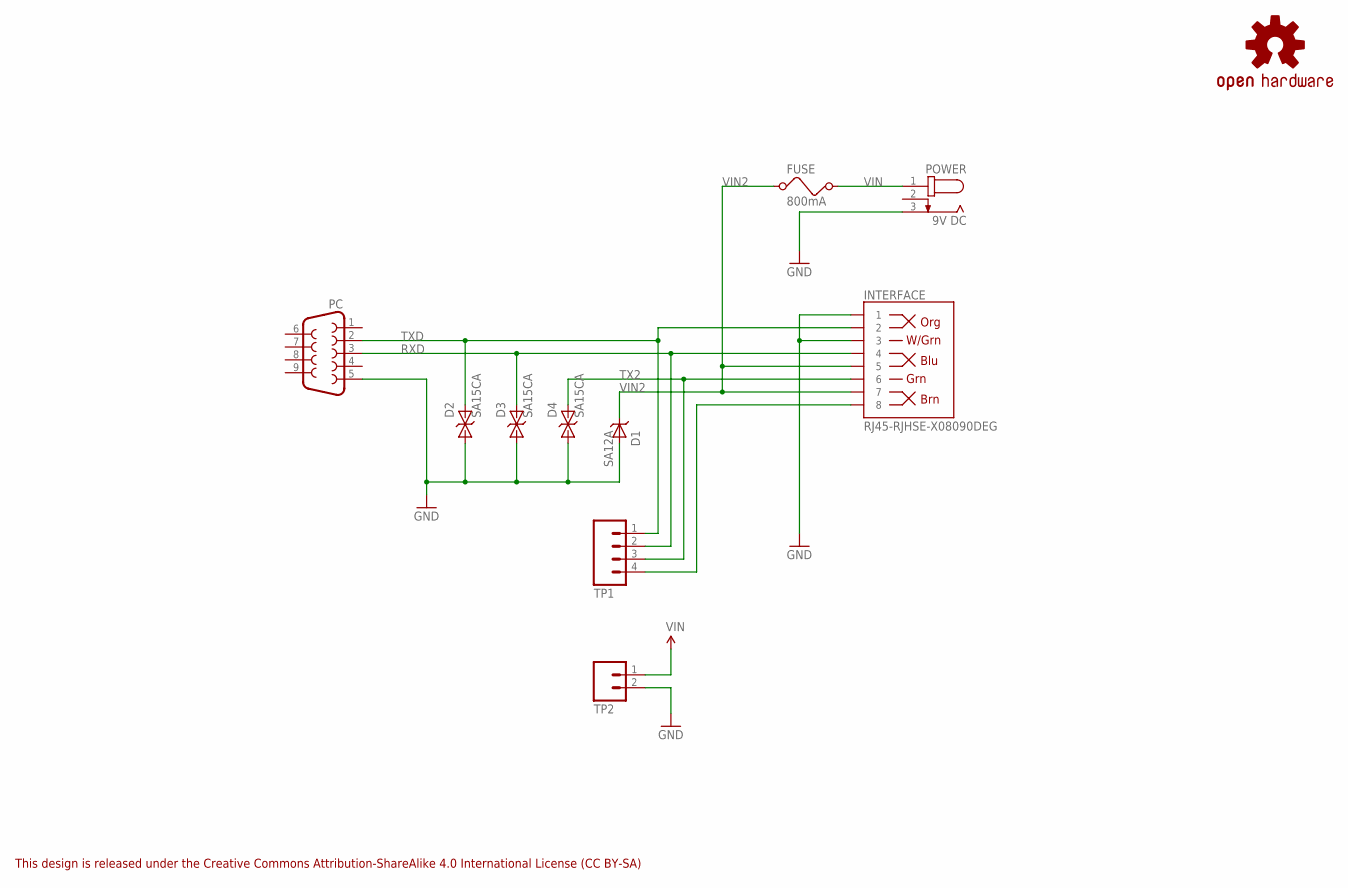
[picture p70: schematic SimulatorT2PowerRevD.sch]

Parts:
D1: SA12A; DO41_TVS_UNI
D2, D3, D4: SA15CA; DO41_TVS_BI
FUSE: 800mA; MCOMP-FUSE-HOLDER-PCB
INTERFACE: RJ45-RJHSE-X08090DEG; RJ45-RJHSE-5080
LOGO1: OSHW-LOGOS; OSHW-LOGO-S
PC: DB9-CONNECTOR-PCBFEMALE; MULTICOMP-DB9-FEMALE-PCB-90DEG
POWER: 9V DC; CLIFF-FC681465P-DC-JACK
TP1: M04PTH; 1X04
TP2: M02PTH; 1X02

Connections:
GND: D1.ANODE, D2.A, D3.A, D4.A, INTERFACE.1, INTERFACE.3, PC.5, POWER.3, TP2.2
P8: INTERFACE.8, TP1.4
RXD: D3.C, INTERFACE.4, PC.3, TP1.2
TX2: D4.C, INTERFACE.6, TP1.3
TXD: D2.C, INTERFACE.2, PC.2, TP1.1
VIN: FUSE.2, POWER.1, TP2.1
VIN2: D1.CATHODE, FUSE.1, INTERFACE.5, INTERFACE.7

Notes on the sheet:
This design is released under the Creative Commons Attribution-ShareAlike 4.0 International License (CC BY-SA)

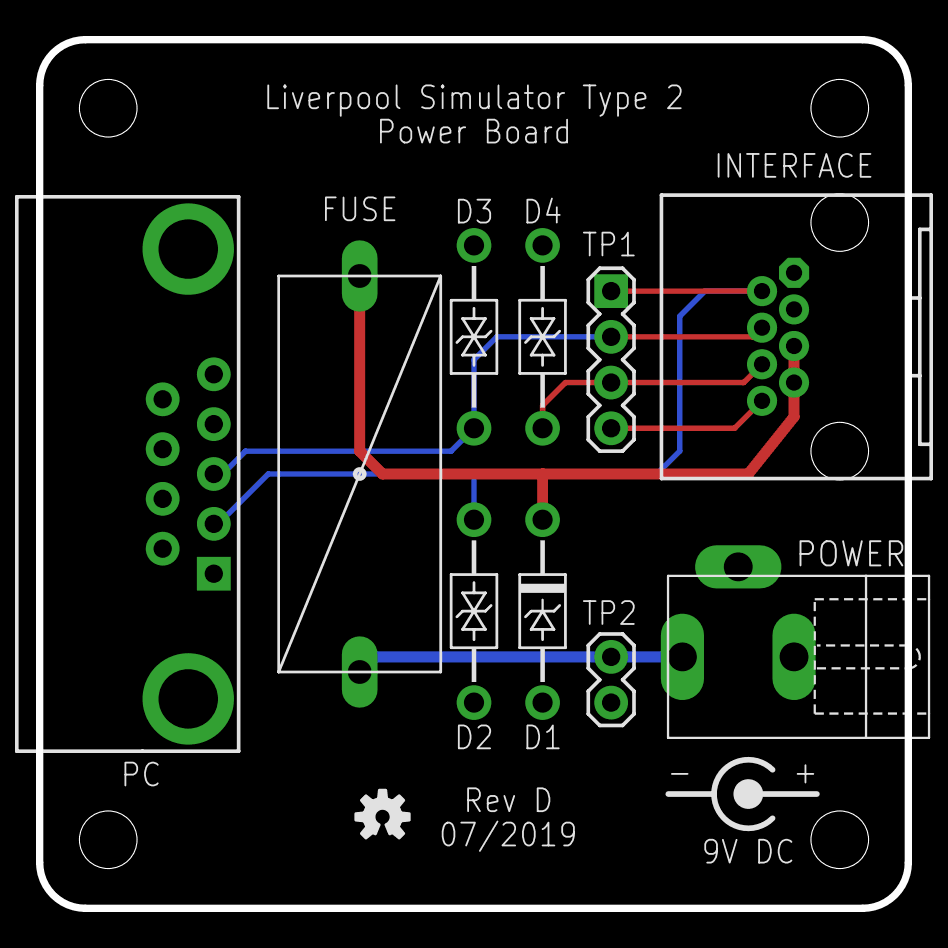
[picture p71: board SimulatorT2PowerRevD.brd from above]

Board: 2 copper layers, 48.3 x 48.3 mm, 12 parts (0 on the bottom side), 7 nets.

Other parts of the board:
U$1: CENTRE-POS-SILK

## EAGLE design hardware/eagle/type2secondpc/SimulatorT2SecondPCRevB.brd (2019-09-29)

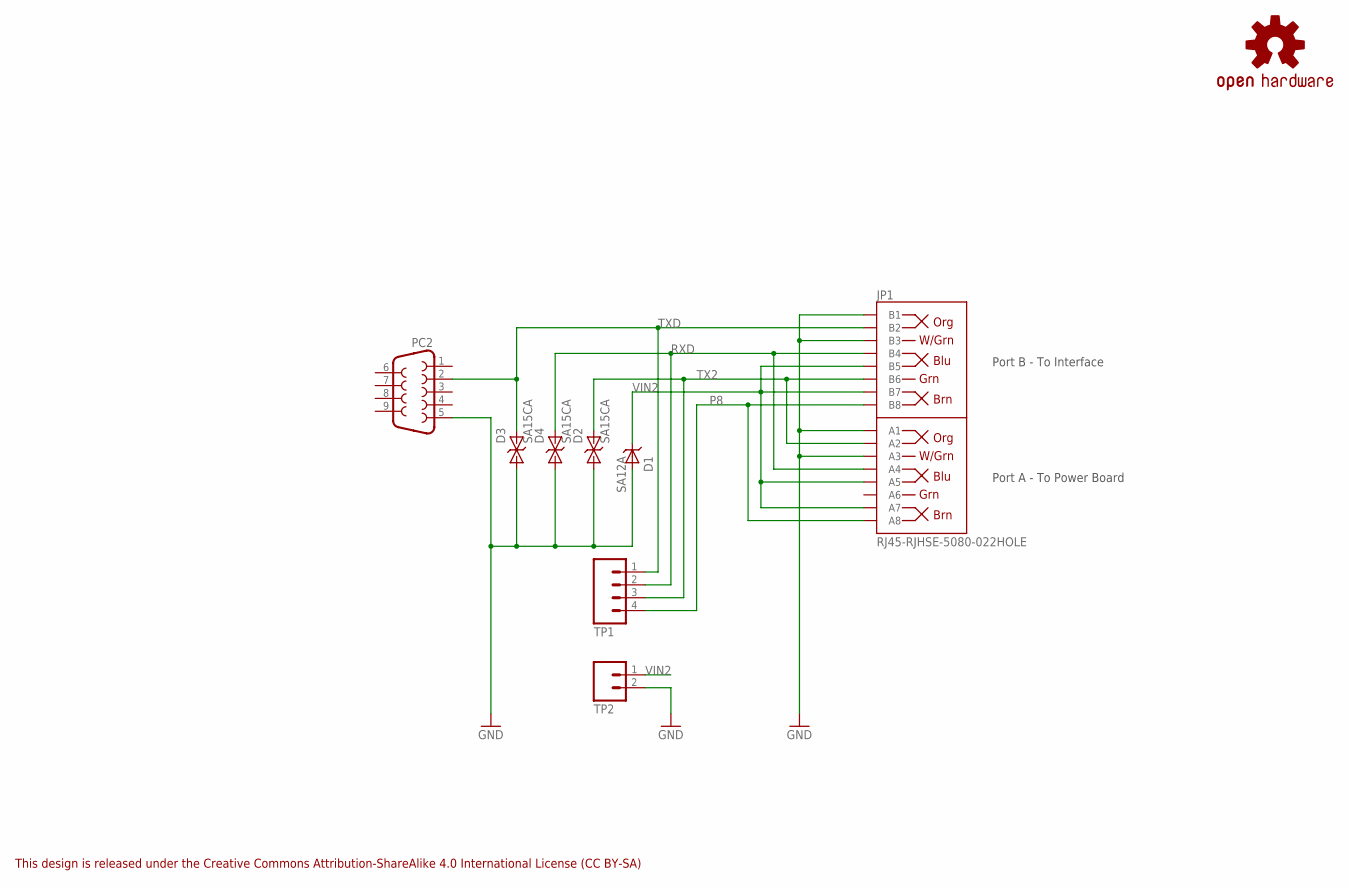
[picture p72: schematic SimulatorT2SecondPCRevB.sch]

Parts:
D1: SA12A; DO41_TVS_UNI
D2, D3, D4: SA15CA; DO41_TVS_BI
JP1: RJ45-RJHSE-5080-022HOLE; RJ45-RJHSE-5080-02
LOGO1: OSHW-LOGOS; OSHW-LOGO-S
PC2: DB9-CONNECTOR-PCBFEMALE; MULTICOMP-DB9-FEMALE-PCB-90DEG
TP1: M04PTH; 1X04
TP2: M02PTH; 1X02

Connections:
GND: D1.ANODE, D2.A, D3.A, D4.A, JP1.A1, JP1.A3, JP1.B1, JP1.B3, PC2.5, TP2.2
P8: JP1.A8, JP1.B8, TP1.4
RXD: D4.C, JP1.A4, JP1.B4, TP1.2
TX2: D2.C, JP1.A2, JP1.B6, TP1.3
TXD: D3.C, JP1.B2, PC2.2, TP1.1
VIN2: D1.CATHODE, JP1.A5, JP1.A7, JP1.B5, JP1.B7, TP2.1

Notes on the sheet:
This design is released under the Creative Commons Attribution-ShareAlike 4.0 International License (CC BY-SA)
Port B - To Interface
Port A - To Power Board

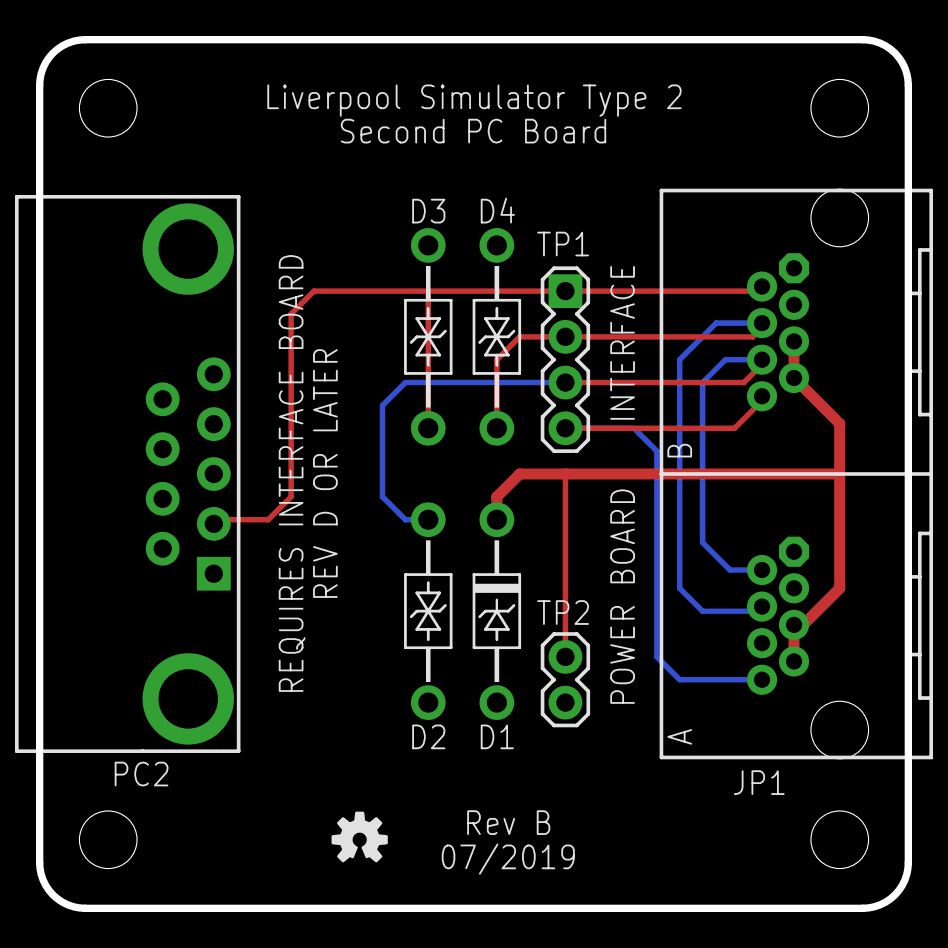
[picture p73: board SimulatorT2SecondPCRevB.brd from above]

Board: 2 copper layers, 48.3 x 48.3 mm, 9 parts (0 on the bottom side), 6 nets.

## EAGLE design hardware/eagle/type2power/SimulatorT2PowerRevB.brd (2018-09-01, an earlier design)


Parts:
FUSE: 800mA; MCOMP-FUSE-HOLDER-PCB
INTERFACE: RJ45-RJHSE-X08090DEG; RJ45-RJHSE-5080
LOGO1: OSHW-LOGOS; OSHW-LOGO-S
PC: DB9-CONNECTOR-PCBFEMALE; MULTICOMP-DB9-FEMALE-PCB-90DEG
POWER: 9V DC; CLIFF-FC681465P-DC-JACK
TP1: M04PTH; 1X04
TP2: M02PTH; 1X02

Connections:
GND: INTERFACE.1, INTERFACE.3, PC.5, POWER.3, TP2.2
P6: INTERFACE.6, TP1.3
P8: INTERFACE.8, TP1.4
RXD: INTERFACE.4, PC.3, TP1.2
TXD: INTERFACE.2, PC.2, TP1.1
VIN: FUSE.2, POWER.1, TP2.1
VIN2: FUSE.1, INTERFACE.5, INTERFACE.7

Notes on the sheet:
This design is released under the Creative Commons Attribution-ShareAlike 4.0 International License (CC BY-SA)


Board: 2 copper layers, 48.3 x 48.3 mm, 7 parts (0 on the bottom side), 7 nets.

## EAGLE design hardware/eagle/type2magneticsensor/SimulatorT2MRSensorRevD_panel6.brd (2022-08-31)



Board: 2 copper layers, 99.1 x 96.5 mm, 79 parts (6 on the bottom side), 48 nets.

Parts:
C1A, C1A_1, C1A_2, C1A_3, C1A_4, C1A_5, C1B, C1B_1, C1B_2, C1B_3, C1B_4, C1B_5: 100nF; CAP-PTH-SMALL
D1, D1_1, D1_2, D1_3, D1_4, D1_5, D2, D2_1, D2_2, D2_3, D2_4, D2_5: SA5.0A; DO41_TVS_UNI
E$1, E$2, E$3, E$4, E$5, E$6: WARNING_TRIANGLE_TPLACE
E$12: OUTLINE_PANEL_6_5MM
JP1, JP1_1, JP1_2, JP1_3, JP1_4, JP1_5: RJ45-RJHSE-5080-023HOLE; RJ45-RJHSE-5080-02-3HOLE
LED1, LED1_1, LED1_2, LED1_3, LED1_4, LED1_5: Blue; LED3MM
LOGO1, LOGO1_1, LOGO1_2, LOGO1_3, LOGO1_4, LOGO1_5: OSHW-LOGOS; OSHW-LOGO-S
R1, R1_1, R1_2, R1_3, R1_4, R1_5: 100R; AXIAL-0.4
R2, R2_1, R2_2, R2_3, R2_4, R2_5: 1K; AXIAL-0.4
R3, R3_1, R3_2, R3_3, R3_4, R3_5: 10K; AXIAL-0.4
U1A, U1A_1, U1A_2, U1A_3, U1A_4, U1A_5, U1B, U1B_1, U1B_2, U1B_3, U1B_4, U1B_5: 2SS52MOFFSET; 2SS52M_FLAT_OFFSET

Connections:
!OUT!: D2.CATHODE, JP1.A8, R1.P$1
!OUT!1: D2_1.CATHODE, JP1_1.A8, R1_1.P$1
!OUT!2: D2_2.CATHODE, JP1_2.A8, R1_2.P$1
!OUT!3: D2_3.CATHODE, JP1_3.A8, R1_3.P$1
!OUT!4: D2_4.CATHODE, JP1_4.A8, R1_4.P$1
!OUT!5: D2_5.CATHODE, JP1_5.A8, R1_5.P$1
B2: JP1.A6, JP1.B8
B3: JP1.A4, JP1.B6
B4: JP1.A2, JP1.B4
B21: JP1_1.A6, JP1_1.B8
B22: JP1_2.A6, JP1_2.B8
B23: JP1_3.A6, JP1_3.B8
B24: JP1_4.A6, JP1_4.B8
B25: JP1_5.A6, JP1_5.B8
B31: JP1_1.A4, JP1_1.B6
B32: JP1_2.A4, JP1_2.B6
B33: JP1_3.A4, JP1_3.B6
B34: JP1_4.A4, JP1_4.B6
B35: JP1_5.A4, JP1_5.B6
B41: JP1_1.A2, JP1_1.B4
B42: JP1_2.A2, JP1_2.B4
B43: JP1_3.A2, JP1_3.B4
B44: JP1_4.A2, JP1_4.B4
B45: JP1_5.A2, JP1_5.B4
GND: C1A.2, C1B.2, D1.ANODE, D2.ANODE, JP1.A1, JP1.A3, JP1.B1, JP1.B3, U1A.P$1, U1B.P$1
GND1: C1A_1.2, C1B_1.2, D1_1.ANODE, D2_1.ANODE, JP1_1.A1, JP1_1.A3, JP1_1.B1, JP1_1.B3, U1A_1.P$1, U1B_1.P$1
GND2: C1A_2.2, C1B_2.2, D1_2.ANODE, D2_2.ANODE, JP1_2.A1, JP1_2.A3, JP1_2.B1, JP1_2.B3, U1A_2.P$1, U1B_2.P$1
GND3: C1A_3.2, C1B_3.2, D1_3.ANODE, D2_3.ANODE, JP1_3.A1, JP1_3.A3, JP1_3.B1, JP1_3.B3, U1A_3.P$1, U1B_3.P$1
GND4: C1A_4.2, C1B_4.2, D1_4.ANODE, D2_4.ANODE, JP1_4.A1, JP1_4.A3, JP1_4.B1, JP1_4.B3, U1A_4.P$1, U1B_4.P$1
GND5: C1A_5.2, C1B_5.2, D1_5.ANODE, D2_5.ANODE, JP1_5.A1, JP1_5.A3, JP1_5.B1, JP1_5.B3, U1A_5.P$1, U1B_5.P$1
LED: LED1.A, R2.P$1
LED1: LED1_1.A, R2_1.P$1
LED2: LED1_2.A, R2_2.P$1
LED3: LED1_3.A, R2_3.P$1
LED4: LED1_4.A, R2_4.P$1
LED5: LED1_5.A, R2_5.P$1
SIG: LED1.K, R1.P$2, R3.P$1, U1A.P$2, U1B.P$2
SIG1: LED1_1.K, R1_1.P$2, R3_1.P$1, U1A_1.P$2, U1B_1.P$2
SIG2: LED1_2.K, R1_2.P$2, R3_2.P$1, U1A_2.P$2, U1B_2.P$2
SIG3: LED1_3.K, R1_3.P$2, R3_3.P$1, U1A_3.P$2, U1B_3.P$2
SIG4: LED1_4.K, R1_4.P$2, R3_4.P$1, U1A_4.P$2, U1B_4.P$2
SIG5: LED1_5.K, R1_5.P$2, R3_5.P$1, U1A_5.P$2, U1B_5.P$2
VCC: C1A.1, C1B.1, D1.CATHODE, JP1.A5, JP1.A7, JP1.B5, JP1.B7, R2.P$2, R3.P$2, U1A.P$3, U1B.P$3
VCC1: C1A_1.1, C1B_1.1, D1_1.CATHODE, JP1_1.A5, JP1_1.A7, JP1_1.B5, JP1_1.B7, R2_1.P$2, R3_1.P$2, U1A_1.P$3, U1B_1.P$3
VCC2: C1A_2.1, C1B_2.1, D1_2.CATHODE, JP1_2.A5, JP1_2.A7, JP1_2.B5, JP1_2.B7, R2_2.P$2, R3_2.P$2, U1A_2.P$3, U1B_2.P$3
VCC3: C1A_3.1, C1B_3.1, D1_3.CATHODE, JP1_3.A5, JP1_3.A7, JP1_3.B5, JP1_3.B7, R2_3.P$2, R3_3.P$2, U1A_3.P$3, U1B_3.P$3
VCC4: C1A_4.1, C1B_4.1, D1_4.CATHODE, JP1_4.A5, JP1_4.A7, JP1_4.B5, JP1_4.B7, R2_4.P$2, R3_4.P$2, U1A_4.P$3, U1B_4.P$3
VCC5: C1A_5.1, C1B_5.1, D1_5.CATHODE, JP1_5.A5, JP1_5.A7, JP1_5.B5, JP1_5.B7, R2_5.P$2, R3_5.P$2, U1A_5.P$3, U1B_5.P$3

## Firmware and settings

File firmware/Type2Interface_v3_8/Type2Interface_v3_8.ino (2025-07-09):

/*
Liverpool Ringing Simulator Project
Simulator Interface v3.8

Copyright 2014-2025 Andrew J Instone-Cowie.

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
Tested against Abel 10.3.2, Beltower 14.05 (2025), Virtual Belfry 3.10.

	3.1 : Dedicated Type 2 (RJ45) Version.
	3.2 : Added remapping code (largely ex SplitterBox).
		  Added CLI option Z to load default settings.
		  CLI detection of unsaved EEPROM settings.
		  Remove quirks mode (Option Q) & associated code.
		  Change default debounce timer to 2ms.
		  Disambiguate channels from bells throughout CLI.
		  Make CLI non case sensitive (apart from Options D/d & T).
		  Improve CLI formatting, really disable disabled channels.
		  Abel 3.10.0, Virtual Belfry 3.5.
		  Measure debounce timer in microseconds to improve consistency.
		  First GitHub release in simulator-type2 repo.
	3.3 : Simplify CLI. Remove requirement to set numChannels and save it to EEPROM,
		  by deriving the value from enabledChannelMask in getNumChannels.
	3.4 : Test mode selection, additional test mode ("firing").
	3.5 : Fix a very old bug in WAIT_FOR_DEBOUNCE.
	3.6 : Test Mode uses the calculated numChannels from enabledChannelMask.
		  Fix Test Mode startup menu crunch.
		  Improve Test Mode CLI.
	3.7 : Add support for MBI protocol 0xFD command for Abel 10.3.2.
	3.8 : Add swing delta timing as an additional debug option.
		  Change debug message format to have identifying letter first.
		  Add time since last pulse to pulse timer (S) debug message.
		  Tested against Beltower 14.05.
		  
*/

/*
ATmega328P fuse settings for 8MHz internal clock:
(Type 2 Interface Board Rev D and earlier)
low_fuses=0xE2
	SUT0
	CKSEL3
	CKSEL2
	CKSEL0
high_fuses=0xDF
	SPIEN
extended_fuses=0xFD
	BODLEVEL1
	
ATmega328P fuse settings for 8MHz external ceramic resonator:
(Type 2 Interface Board Rev E and later)
low_fuses=0xCF
	SUT0
	SUT1
high_fuses=0xDF
	SPIEN
extended_fuses=0xFD
	BODLEVEL1

The appropriate set of fuses is selected in the Arduino IDE by selecting the
correct board type in the Liverpool Ringing Simulator Boards set.

Unlike the previous hardware, we do now clear the EEPROM on load (high fuse 0xdF instead of
0xd7), so we can be confident of getting a workable startup config even if the interface has
not been configured. See loadFromEEPROM() and defaulMask.

*/

// Simulator Interface Hardware Type
//  - Type 2 hardware is the RJ45 interface board.
//  - The IDE sets up a #define ARDUINO_AVR_SIMULATOR_TYPE2
//#define ARDUINO_AVR_SIMULATOR_TYPE2

// Uncomment the following line to use a pin as a CRO timing pin.
// This should be commented out in production code.
//#define USE_CRO

// Include the free memory library, freeMemory() is called by dumpdata().
#include <MemoryFree.h>

// Include the VTSerial library for VT100-style input functions.
#include <VTSerial.h>

// Initialise the VTSerial library.
VTSerial vtSerial;

// Include attributes file for the terminal handling functions.
#include "Terminal_Functions.h"

// Non-volatile configuration data are stored in EEPROM:
// Location  1    : No longer used
// Location  2    : No longer used
// Location  3    : Debounce Timer (in ms)
// Location  4    : Serial port speed (as an index into serialSpeeds[])
// Location  5    : enabledChannelMask (lo byte)
// Location  6    : enabledChannelMask (hi byte)
// Location  7    : debugChannelMask (lo byte)
// Location  8    : debugChannelMask (hi byte) 
// Location  9    : Guard Timer (in cs)

// Define the EEPROM locations to make the code more readable.
// #define EEPROM_SIMULATOR_TYPE 1
// #define EEPROM_NUMCHANNELS 2
#define EEPROM_DEBOUNCE_DELAY 3
#define EEPROM_SERIAL_SPEED 4
#define EEPROM_ENABLE_MASK_LO 5
#define EEPROM_ENABLE_MASK_HI 6
#define EEPROM_DEBUG_MASK_LO 7
#define EEPROM_DEBUG_MASK_HI 8
#define EEPROM_GUARD_DELAY 9
#define EEPROM_MAPPING_BASE 10 //10-25 are used for remapped output signals

#include <EEPROM.h>

// Software version
const int majorVersion = 3;
const int minorVersion = 8;

// -------------------------------------------------------------------------------------------
//                                    Core Simulator
// -------------------------------------------------------------------------------------------

// Define the maximum number of channels that can be set on the hardware. For the Type 2 
// interface this is 16.
const int maxNumChannels = 16;

// Define the number of the highest input channel to scan (always starting at 0, held in EEPROM).
// Not scanning unused channels avoids issues with spurious signals being detected on
// floating inputs (even with INPUT_PULLPUP). Most data structures, etc are set up for this
// number of channels.
int numChannels; // initialised from enabledChannelMask after EEPROM load in setup

#ifdef ARDUINO_AVR_SIMULATOR_TYPE2
const int channelSensorPin[] = { 6, 7, 8 ,9, 10, 11, 12, 13, 14, 3, 15, 2, 16, 17, 18, 19 };
//14-19 aka A0-A5
#endif

// Set up an array of the characters sent on the serial port to the simulator software, as
// defined in the MBI interface specification. These are ASCII characters. 
// These may be overwritten from EEPROM, see loadFromEEPROM();
char bellStrikeChar[] = { '1', '2', '3', '4', '5', '6', '7', '8', '9', '0', 'E', 'T', 'A', 'B', 'C', 'D' };

// Define the default serial characters in case the EEPROM is not yet set sensibly.
const char defaultBellStrikeChar[] = { '1', '2', '3', '4', '5', '6', '7', '8', '9', '0', 'E', 'T', 'A', 'B', 'C', 'D' };

// Set up an array to store the last observed sensor status, so we can detect transitions
// in input state. This is important to avoid duplicated sensor signals. 
int channelLastValue[maxNumChannels]; //initialise these in setup, and set them LOW (see below)

// Set up an array of the permitted serial port speeds. Note that Abel and Beltower
// (and the MBI protocol specification) REQUIRE 2400 bps. Other speeds may be useful only
// for debugging where the text output can overrun the serial transmit buffer and cause
// timing issues. Also declare an int to hold the indexed value, and a sane default.
unsigned long serialSpeeds[] = { 2400, 4800, 9600 };
int serialSpeed = 0; // index into serialSpeeds[], not the actual bps, loaded from EEPROM 
const long defaultSerialSpeed = 0; // 2400 - required by the simulators

// Set up an Enabled Sensor Mask variable as a 16 bit unsigned word. The bits
// (0-15) correspond to the sensor being enabled on that channel (1=true=on, 0=false=off).
// LSB = Channel 0 (usually treble, or sensor 1).
word enabledChannelMask; // initialised from EEPROM in setup. See option E.

// Define the default mask to use if the EEPROM is not sane. This is used for both the
// enabledSensorMask and debugBellMask.
const word defaultMask = 65535;

// -------------------------------------------------------------------------------------------
//                                   Sensor Debounce
// -------------------------------------------------------------------------------------------

// Set up an array to hold the time that the debounce timer will expire, one per channel. The
// data type is unsigned long, because these values will be the sum of debounceDelay and
// the output of micros().
unsigned long channelDebounceEndTime[maxNumChannels]; // initialise these in setup()

// Set up a variable to hold the debounce delay time, in milliseconds.
// Note that the debounce timer is stored and presented in milliseconds, but observed
// in microseconds. This improves accuracy where the number of milliseconds is very small.
unsigned long debounceDelay ; // initialised from EEPROM in setup. See option B.

// Define the maximum permitted debounce timer value. Current value is stored in EEPROM, so
// must be <=255 ms. This value is used when setting the timer via the B CLI option.
// The minDebounceTimer will always be 1ms, so no definition for it.
const unsigned long maxDebounceDelay = 20; //ms

// Define the default debounce timer value in case the EEPROM is not yet set sensibly.
const unsigned long defaultDebounceDelay = 2; //ms

// -------------------------------------------------------------------------------------------
//                                   Sensor Guard Time
// -------------------------------------------------------------------------------------------

// Set up an array to hold the actual time that the guard timer will expire for each channel,
// one per channel. The data type is unsigned long, because these values will be the sum of
// guardDelay (x 10) and the output of millis().
unsigned long channelGuardEndTime[maxNumChannels]; // initialise these in setup()

// Set up a variable to hold the debounce delay time, in milliseconds.
unsigned long guardDelay ; // initialised from EEPROM in setup. See option G.

// Define the maximum permitted guard timer value. Current value is stored in EEPROM, so
// must be <=255 cs. This value is used when setting the timer via the G CLI option.
// The minDebounceTimer will always be 1cs, so no definition for it.
const unsigned long maxGuardDelay = 50; //cs

// Define the default guard timer value in case the EEPROM is not yet set sensibly.
const unsigned long defaultGuardDelay = 10; //cs

// -------------------------------------------------------------------------------------------
//                                    State Machines
// -------------------------------------------------------------------------------------------

// Set up an array of integers to indicate whether each per-channel state machine is in the
// program state "WAIT_FOR_INPUT" (0), "WAIT_FOR_DEBOUNCE" (1), "WAIT_FOR_GUARD"(2), 
// "TEST_MODE" (3) or "SENSOR_DISABLED" (4)
int channelMachineState[maxNumChannels]; // initialise these in setup()

// Define the possible machine states as text to make the code more readable.
#define WAIT_FOR_INPUT 0
#define WAIT_FOR_DEBOUNCE 1
#define WAIT_FOR_GUARD 2
#define TEST_MODE 3
#define SENSOR_DISABLED 4

// -------------------------------------------------------------------------------------------
//                                      Debugging
// -------------------------------------------------------------------------------------------
// Set up a Debug Mode flag - this always cleared on reset, so not held in EEPROM.
boolean debugMode = false;

// Define the debug flags as text to make the code more readable
#define DEBUG_PULSE_TIMER 1		//bit 0
#define DEBUG_SHOW_MISFIRES 2	//bit 1
#define DEBUG_SHOW_DEBOUNCE 4	//bit 2
#define DEBUG_SHOW_LED 8		//bit 3
#define DEBUG_SWING_TIMER 16	//bit 4
// Remaining bits not used.
// (See also the function printDebugFlagName(), seeing as F() is not available globally)

// Set up a Debug Mask variable as a 16 bit unsigned word. The bits (0-16)
// correspond to debugging being enabled on that channel (1=true=on, 0=false=off). This
// allows per-channel debugging to be configured. LSB = Channel 0 (which is sensor 1).
word debugChannelMask; // initialised from EEPROM in setup. See option M.
// See also defaulMask above.

// Set up a Debug Flags Mask variable. The first 5 bits (0-4) correspond to debugging
// facilities in the code (1=on, 0=off). This allows each facility to turned on and off
// independently. These can be changed on the fly with the D option.
word debugFlagsMask = DEBUG_PULSE_TIMER; //debug starts with DEBUG_PULSE_TIMER flag set by default

// Define the maximum configured number of flags. This value will depend on the flags
// actually implemented in the code. Currently there are 5 flags, as #defined below.
// If you add a debug level, increment this constant so that the CLI works.
const int maxDebugFlags = 5;


// -------------------------------------------------------------------------------------------
//                                   Debug Pulse Timing
// -------------------------------------------------------------------------------------------

// These variables are used for debug mode pulse length timing and counting only. There is
// no need to do pulse timing during normal operation.

// Set up two arrays to hold the actual start and end times of the sensor pulse, one per bell.
// The data type is unsigned long, because these values will be the output of micros(). These
// are used in debug mode only to calculate the length of the (first) sensor pulse.
unsigned long pulseStartTime[maxNumChannels]; // initialise these in setup()
unsigned long pulseEndTime[maxNumChannels];   // initialise these in setup()

// Set up an array to store the last observed sensor status, so we can detect transitions.
// This array is used for debug mode pulse timing only, because updating the real
// channelLastValue[] would lose the debounce effect for real simulator operation (which
// has to carry on regardless).
int pulseTimeLastValue[maxNumChannels]; //initialise these in setup, and set them LOW (see below)

// Set up an array of integers to count the pulses (to show how noisy a sensor is). We do this
// by counting spurious pulse *ends* (LOW to HIGH) when we aren't expecting them, and to make
// sure we timed only the first pulse.
int pulseTimeCount[maxNumChannels]; //initialise in setup, and set to zero


// -------------------------------------------------------------------------------------------
//                                   Debug Swing Timing
// -------------------------------------------------------------------------------------------

// These variables are used for debug mode swing timing only. There is no need to do swing
// timing during normal operation.

// Set up an array to hold the saved start time of the /previous/ pulse, so that the swing
// time (i.e. the delta between one pulse and the next) can be calculated, one per bell.
// The previous value of pulseStartTime[n] is pushed into this array before pulseStartTime[n]
// is updated in WAIT_FOR_INPUT.
unsigned long lastPulseStartTime[maxNumChannels]; // microseconds, initialise these in setup()

// Set up an array to hold the duration of the previous swing, so that the delta between this
// swing time and the previous one can be calculated (i.e. the difference between handstroke
// and backstroke). The swingTime value is pushed into lastSwingTime[n] for re-use after the
// current swing time has been calculated and displayed in WAIT_FOR_DEBOUNCE. Data type is long,
// because this will be difference between two long values, and may be negative.
long lastSwingTime[maxNumChannels]; // milliseconds, initialise these in setup()


// -------------------------------------------------------------------------------------------
//                                     CLI Terminal
// -------------------------------------------------------------------------------------------

// Define the terminal display configurations as text to make the code more readable.
// See termSetFor().
#define TERM_DEFAULT 0
#define TERM_HEADING 1
#define TERM_CLI 2
#define TERM_INPUT 3
#define TERM_CONFIRM 4
#define TERM_DEBUG 5

// -------------------------------------------------------------------------------------------
//                                     Test Mode
// -------------------------------------------------------------------------------------------

// These variables are used for test mode. None of these things are configurable on the fly.

// Define the delay before test mode kicks in after selecting the "T" CLI option
const int testStartDelay = 20; //seconds

// The number of bells used in test mode (and elsewhere) is calculated as numChannels from the
// highest channel enabled in the enabledChannelMask, so by setting this (option E in the CLI),
// the number of test mode bells can be set.

// Define the inter-bell interval used in test mode. 200ms equates to a 12-bell peal speed
// of 3h30m with an open handstroke lead.
const int testInterval = 200; //msec

// Define the test mode:
// Mode 0 = Bail out of the T menu item in the CLI
// Mode 1 = Rounds on testBells @testInterval ms
// Mode 2 = "Firing" at approx the same speed, all characters sent as quickly as possible
int testMode = 0;

// -------------------------------------------------------------------------------------------
//                                     LEDs & Timing
// -------------------------------------------------------------------------------------------

// Miscellaneous LEDs and optionally a CRO timing pin

#ifdef ARDUINO_AVR_SIMULATOR_TYPE2
// Only 1 signal LED, the right hand yellow LED in the power/data RJ45 connector
const int LED = 4;
#endif

// If USE_CRO was defined above, define a pin for CRO timing measurements.
#if defined USE_CRO && defined ARDUINO_AVR_SIMULATOR_TYPE2
const int CROpin = 5; 
#endif

// Overall this leaves as spares the following pins:
// - Type 2: 5

// ------------------------------------------------------------------------------------------
//                                   Target Remapping
// ------------------------------------------------------------------------------------------
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
void loop() {

	// main loop start, waggle the CRO timing pin up if used.
#ifdef USE_CRO
	digitalWrite( CROpin, HIGH );
#endif

	// main loop counter
	int i;
	// test mode counters
	int j, k;

	// loop around all the active channels and look at the state of the state machine for each
	for ( i = 0; i < numChannels; i++ ) {

		// Variable to store the value read from the pin
		int channelSensorValue;
		
		switch ( channelMachineState[i] ) {

			// ---------------------------------------------------------------------------------------
			// -                                 WAIT_FOR_INPUT                                      -
			// ---------------------------------------------------------------------------------------
		case WAIT_FOR_INPUT:

			// This channel is in "WAIT_FOR_INPUT" state
			// Read the value from the sensor pin
			channelSensorValue = digitalRead( channelSensorPin[i] );
			
			if ( channelSensorValue == LOW && channelLastValue[i] == HIGH ) {
				
				// This is a HIGH to LOW transition since we last looked, so we have the start of a
				// sensor pulse. Note the current time in a scratch variable (to avoid calling
				// time functions twice)
				unsigned long timeNowMicros;
				timeNowMicros = micros();
				unsigned long timeNowMillis;
				timeNowMillis = millis();
				
				// Set the time that the guard timer will expire to now + the guard timer,
				// remembering that the guard timer is in cs, not ms. (Do this calculation
				// here so we only have to do the comparison in following loops, not the addition)
				channelGuardEndTime[i] = timeNowMillis + ( guardDelay * 10 );

				// Set the time that the debounce timer will expire to to now + the debounce timer,
				// remembering that the stored value is in milliseconds but measured in microseconds.
				// (Do this calculation here so we only have to do the comparison in following loops,
				// not the addition)
				channelDebounceEndTime[i] = timeNowMicros + ( debounceDelay * 1000 );
				
				// Set the last observed value to the current state of the sensor, which is LOW.
				// For an explanation of why we do this, see below.
				channelLastValue[i] = channelSensorValue;

				// Use the LED to signal strikes on channel 1 (MBI always starts at channel 1, even for
				// <12 bells). Turn on when the pulse is received, off when guard timer expires. Array
				// is zero indexed. (The LED may be used in other debug options, so hand this off to
				// a function.)
				strikeLED( LED, i, true );
				
				// Move the machine state on to "WAIT_FOR_DEBOUNCE"
				channelMachineState[i] = WAIT_FOR_DEBOUNCE;
				
				// If we are in debug mode, grab the pulse start time (saving the previous value) and reset the counter.
				// Both the pulse timer and the misfire detection require pulse timing to be done.
				// Swing timing requires the start time of this and the previous pulse.
				if ( debugThisChannel( i ) && isDebugFlagSet( DEBUG_PULSE_TIMER | DEBUG_SHOW_MISFIRES | DEBUG_SWING_TIMER ) ) {
					
					lastPulseStartTime[i] = pulseStartTime[i]; //save the previous value for swing timer debugging
					pulseStartTime[i] = timeNowMicros;
										
					// Avoid overflows giving a silly number if we get to a debug print before the end
					// of the first pulse! A pulse length of 0 means the pulse has not ended yet.
					pulseEndTime[i] = pulseStartTime[i];
					pulseTimeLastValue[i] = channelSensorValue;
					pulseTimeCount[i] = 0; //incremented at the END of the pulse
					
					// We only run this code at the start of a valid pulse. The counter is used
					// to ensure that we only measure the duration of the first pulse in a potential
					// string of noisy input pulses (which are ignored by the main interface code).
					
				} //debugThisBell
				
			}
			else // this is not the start of a pulse
			{

				// Set the last observed value to the current state of the sensor, which may
				// (still) be LOW or (by now) HIGH.
				channelLastValue[i] = channelSensorValue;
				
				// We stay in the "WAIT_FOR_INPUT" state. We may have come back here and found the
				// sensor still LOW after sending the character to the simulator if the delay is
				// very short and the pulse very long, hence the transition detection.
				
			} //channelSensorValue
			
			break; //channelMachineState == WAIT_FOR_INPUT

			// ---------------------------------------------------------------------------------------
			// -                                WAIT_FOR_DEBOUNCE                                    -
			// ---------------------------------------------------------------------------------------      
		case WAIT_FOR_DEBOUNCE:
			
			// This channel is in "WAIT_FOR_DEBOUNCE" state.
			// Check whether the signal has ended too soon (and so is considered noise).
			
			// Note the current time in a scratch variable (to avoid calling time functions twice)
			unsigned long timeNowMicros;
			timeNowMicros = micros();
						
			// Read the value from the sensor pin
			channelSensorValue = digitalRead( channelSensorPin[i] );
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

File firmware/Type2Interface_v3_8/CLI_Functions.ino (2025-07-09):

/*
Liverpool Ringing Simulator Project
Simulator Interface v3.8
Serial CLI Functions

Copyright 2014-2025 Andrew J Instone-Cowie.

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
You should have received a copy of the GNU General Public License
along with this program.  If not, see <http://www.gnu.org/licenses/>.
*/

/*
*********************************************************************************************
*                                   Function dumpData()                                     *
*********************************************************************************************
*/

// Dump current configuration data to the serial port.
void dumpData( void ) {

	// Position the cursor and clear the screen.
	termClear();

	// generic loop counter
	int i;
	
	// What version of software are we running?
	termSetFor( TERM_HEADING );
	Serial.print(F("Simulator Interface Version: "));
	Serial.print( majorVersion );
	Serial.print(F("."));
	Serial.println( minorVersion );
	termSetFor( TERM_DEFAULT );

	// What version of hardware are we compiled for? 
	Serial.print(F("Hardware Version: "));
#if defined ARDUINO_AVR_SIMULATOR_TYPE2
	Serial.println("Type 2");
#else
	Serial.println(F("Unknown"));
#endif
	
	// How many channels are we scanning? 
	if ( debugMode ) {
		Serial.print(F("Highest Active Channel: "));
		Serial.println( numChannels );
	}
	
	// What are the debounce timer values? 
	Serial.print(F("Active Debounce Timer (ms): "));
	Serial.println( debounceDelay );
	Serial.print(F("EEPROM Debounce Timer (ms): "));
	Serial.println( EEPROM.read( EEPROM_DEBOUNCE_DELAY ) );

	// What are the guard timer values? 
	Serial.print(F("Active Guard Timer (cs): "));
	Serial.println( guardDelay );
	Serial.print(F("EEPROM Guard Timer (cs): "));
	Serial.println( EEPROM.read( EEPROM_GUARD_DELAY ) );

	// Start of Channels Status

	// Heading & space-separated list of channel numbers
	printChannelList();
	
	// Which channels are enabled?
	Serial.print(F("Enabled: "));
	printEnabledStatus( enabledChannelMask, maxNumChannels );	
	
	// What is the current output mapping?
	showActiveMapping();
	
	// What are the most recent sensor values?
	showSensorInputs();
	
	// End of Channels Status
	
	// Check for duplicate mappings and warn
	duplicateMapCheck();
	
	// What is the configured serial port speed? 
	Serial.print(F("Serial Port Speed: "));
	serialSpeed = int( EEPROM.read( EEPROM_SERIAL_SPEED ) );
	// setup sets a default 2400 if the EEPROM value is bad...
	if ( serialSpeed < 0 || serialSpeed > 2 ) {
		serialSpeed = defaultSerialSpeed;
	}
	Serial.println( serialSpeeds[serialSpeed] );  
	
	Serial.print(F("Free Memory: "));
	Serial.println( freeMemory() );  

	// Show debug mode status 
	Serial.print(F("Debug Mode: "));
	if ( debugMode ) { 
		Serial.println(F("ON"));
		// Serial.print(F("Debug Flags Mask: "));
		// printMask( debugFlagsMask, maxDebugFlags );
		printChannelList();
		Serial.print(F("DebugEn: "));
		printEnabledStatus( debugChannelMask, maxNumChannels );
		Serial.println(F("Debug Flags Set: "));
		printDebugFlagsSet();
	}
	else
	{
		Serial.println (F("OFF"));
	}

#ifdef USE_CRO
	Serial.print(F("CRO Timing Pin Enabled: "));
	Serial.println( CROpin );  
#endif

}

/*
*********************************************************************************************
*                                   Function showCLI()                                      *
*********************************************************************************************
*/

// Display the CLI prompt to the serial port.
void showCLI( void ) {

	// If you call showCLI(), you need to supply the carriage return later, e.g. after
	// you have echoed the keypress.

	// The CLI is different when in debug mode.

	// Set the terminal modes for the CLI.
	termSetFor( TERM_CLI );

	// Print the first part of the CLI
	Serial.print(F(" : B/G/E/S/P/R/D/"));

	if ( debugMode )
	{
		// Print the debug mode options - in this version all debug options
		// are available at any debug level.
		Serial.print(F("d/M/0-9/L/Z/"));
	}

	// Print the trailing part of the CLI
	Serial.print(F("H/T/? "));

	// Set the terminal modes back to normal.
	termSetFor( TERM_DEFAULT );

}

/*
*********************************************************************************************
*                                  Function handleCLI()                                     *
*********************************************************************************************
*/

// Handle CLI input.
void handleCLI( byte commandByte ) {

	// This function is passed the first (and possibly only) byte from the serial buffer,
	// once we know it's not an MBI command or new (erroneously sent) delay data.

	// generic loop counter
	int i;

	// generic scratch variable for vtSerial.ReadLong
	int readval;

	switch ( commandByte ) {

	case '?':    // ?  = Dump values to serial for debugging
		Serial.println( char( commandByte ) );
		dumpData();
		// blink the LED to indicate we got a valid command
		// just a quick blink so as not to slow the CLI down too much when cycling
		blinkLED( LED, 0, 1 ); //one quick
		break;

	case 'B':    // B  = Set the debounce timer value (ms)
	case 'b':
		Serial.println( char( commandByte ) );
		readval = 0; // Set the value to be read deliberately out of range.
		do {
			termSetFor( TERM_INPUT );
			Serial.print(F(" -> Enter debounce timer [1-20ms]: "));
			termSetFor( TERM_DEFAULT );
			readval = vtSerial.ReadLong();       // read integer
			Serial.println("");
		} while ( readval < 1 || readval > maxDebounceDelay );
		debounceDelay = readval;
		termSetFor( TERM_CONFIRM );
		Serial.print(F("Debounce Timer: "));
		Serial.print( debounceDelay );
		Serial.println(F("ms"));
		blinkLED( LED, 2, 3 );
		break;

	case 'G':    // G  = Set the guard timer value (cs)
	case 'g':
		Serial.println( char( commandByte ) );
		readval = 0; // Set the value to be read deliberately out of range.
		do {
			termSetFor( TERM_INPUT );
			Serial.print(F(" -> Enter guard timer [1-50cs]: "));
			termSetFor( TERM_DEFAULT );
			readval = vtSerial.ReadLong();       // read integer
			Serial.println("");
		} while ( readval < 1 || readval > maxGuardDelay );
		guardDelay = readval;
		termSetFor( TERM_CONFIRM );
		Serial.print(F("Guard Timer: "));
		Serial.print( guardDelay );
		Serial.println(F("cs"));
		blinkLED( LED, 2, 4 );
		break;
		
	case 'S':    // S  = Save settings to EEPROM as bytes
	case 's':
		Serial.println( char( commandByte ) );
		saveToEEPROM();
		// blink the LED to indicate we got a valid command
		blinkLED( LED, 2, 5 );
		break;
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

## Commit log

2018-09-01 Upload firmware and PCB files
    Upload latest Type 2 firmware, Eagle and Gerber files into the new repo.
    [SimulatorT2GenericSensorRevC.brd, SimulatorT2GenericSensorRevC.sch, SimulatorT2GenericSensorRevC_panel1.brd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]
2018-09-11 Minor fix to Interface board
    [SimulatorT2InterfaceRevC.brd]
2018-09-13 More draft guides
    New Beltower, Virtual Belfry, changed Abel
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2018-10-28 Build Guide Update
    Minor corrections, PCB ordering, voltage regulator
2018-11-02 Part Code Change
    Changed the Farnell part code for the 1N4001 diode to a more available
    UK stocked item.
2018-11-02 Cost Estimation Tool
    Added an Excel cost estimation tool to give an estimate component cost
    based on the required number of interfaces and sesnsors.
    [Type 2 Cost Estimation Tool v1.0.xlsx]
2019-01-20 Interface Board Rev D
    Fixes a clearance problem with the alternative voltage regulator, and
    adds a second serial connection for future use. Enable layer 51 tDocu in
    Eagle to see alternate regulator outline. Closes #1
    [SimulatorT2InterfaceRevD.brd, SimulatorT2InterfaceRevD.sch]
2019-01-24 Build Guide v.04
    Updated for Interface PCB Rev D, and added guidance on polarised
    components.
2019-01-25 Cost Estimation Tool v1.1
    Added the PSU
    [Type 2 Cost Estimation Tool v1.0.xlsx, Type 2 Cost Estimation Tool v1.1.xlsx]
2019-02-05 Part changes
    Replace Amphenol 2-port RJ45 (no longer stocked by Farnell) with Amp TE
    Connectivity direct replacement. Remove link to Boardstuff programmer
    (no longer available) and replace with examples of hardware programmers.
    Update cost estimation tool.
    [Type 2 Cost Estimation Tool v1.1.xlsx, Type 2 Cost Estimation Tool v1.2.xlsx]
2019-02-10 Documentation updates
    Diagram showing voltage test points, more GitHub links.
2019-02-17 Minor correction to build guide
    Correct error in the voltage checks pinout diagram.
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2019-02-24 Power Board Rev C
    Add an indication of power supply polarity to the top silkscreen.
    [SimulatorT2PowerRevC.brd, SimulatorT2PowerRevC.sch, SimulatorT2PowerRevC_panelized.brd]
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2019-04-18 Second PC Board Rev A
    Enables support for a second PC by daisy-chaining the Second PC board
    between the Power Board and Interface. Requires Interface Rev D or
    later, or a mod to earlier Interface boards (described in the Eagle
    Description file).
    [SimulatorT2SecondPCRevA.brd, SimulatorT2SecondPCRevA.sch, SimulatorT2SecondPCRevA_panel4.brd]
2019-05-06 Board fixes
    [SimulatorT2SecondPCRevA.brd, SimulatorT2SecondPCRevA_panel4.brd]
2019-05-12 2nd PC Board Doc Changes
    Update the Getting Started and Build & Installation Guides with support
    for the Second PC Board
2019-05-27 Interface RevE Boards
    Eagle files and Gerbers for Type 2 Interface Board Rev E
    [SimulatorT2InterfaceRevE.brd, SimulatorT2InterfaceRevE.sch]
2019-05-27 Cost estimation tool update for Rev E
    Update the cost estimation tool for Rev E boards, clean up spurious
    images folder.
    [Type 2 Cost Estimation Tool v1.2.xlsx, Type 2 Cost Estimation Tool v1.3.xlsx]
2019-06-20 Fuse Values
    Comment change only: Add note describing the fuses for resonators on Rev
    E boards,
2019-08-03 Enhanced surge protection
    Power Rev D, 2nd PC Rev B boards with improved surge protection,
    Gerbers, Cost Estimation tool, New enclosure drilling templates.
    [SimulatorT2PowerRevD.brd, SimulatorT2PowerRevD.sch, SimulatorT2PowerRevD_panel4.brd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]
2019-08-03 Documentation updates
    All docs updated to v1.0. Updated Power Board to Rev D, Second PC to Rev
    B, both with improved surge protection. Remove OSH Park permalinks,
    Fixed dimension error on IR sensor enclosure. Add reference to enclosure
    drilling templates.
2019-09-29 Rev C Hardware
    Eagle, Gerbers, Library files for BAsic Serial Splitter Rev C
    [T2BasicSerialSplitterRevC.brd, T2BasicSerialSplitterRevC.sch]
2019-10-19 Fix bug in debounce code
    When misfiring, set the last observed value to the current state of the
    sensor in WAIT_FOR_DEBOUNCE, which is now HIGH again. If we don't do
    this, and the noise pulse is so close to the stable pulse that the
    stable pulse begins on the very next iteration of loop(), then the real
    pulse would be missed (because WAIT_FOR_INPUT is looking for a
    high-to-low transition). This has only been seen with a VERY noisy
    mechanical switch sensor.
    [CLI_Functions.ino, Debug_Functions.ino, EEPROM_Functions.ino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]
2020-01-02 TRG v1.1
    Added BAsic Serial Splitter details, more connector info, logic analyser
    trace to latency section.
2020-08-18 Documentation update
    Minor documentation update and upload of all documentation source
    material.
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2022-05-18 Wider 5mm break-offs
    Issues with JLPCB rejecting panelised boards with 2.5mm stamp hole
    break-off tabs. Increased tab width to 5mm on all panelised boards.
    [SimulatorT2GenericSensorRevC_panel1.brd, SimulatorT2GenericSensorRevC_panel6.brd, SimulatorT2GenericSensorRevC_panel6b.brd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]
2022-07-25 Firmware v3.6, Eagle Custom Library
    Improvements to Test Mode functionality and CLI. Also latest Eagle
    custom library which was missed previously.
    [CLI_Functions.ino, Debug_Functions.ino, EEPROM_Functions.ino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]
2022-08-31 Board Housekeeping
    URL on silkscreens, caution messages, tidy up naming conventions.
    [SimulatorT2BasicSerialSplitterRevC.brd, SimulatorT2BasicSerialSplitterRevC.sch, SimulatorT2GenericSensorRevC.brd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]
2024-06-27 Cost Estimation Tool Update
    Update Cost Estimation Tool with latest (June 2024) costs, and add support for costing the Multi-PC options (Second PC Board, Basic Serial Splitter).
    [Type 2 Cost Estimation Tool v1.4.xlsx, Type 2 Cost Estimation Tool v1.5.xlsx]
2024-08-28 Multi-PC Documentation Improvements
    Update diagrams to show cable types more clearly, add a table of possible module combinations for multi-PC configurations.
2025-02-21 T1-T2 Adapter Resources
    Eagle files, Gerbers, diagrams & images for the Type 1 - Type 2 Adapter board.
    [SimulatorT1-T2-AdapterRevB.brd, SimulatorT1-T2-AdapterRevB.sch]
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2025-04-24 Kicad Projects
    Kicad archived Projects for all boards excluding the MR sensor.
2025-04-24 Kicad Panel Gerbers
    Panelised Gerbers for sensor/power/2nd PC excluding the MR sensor.
2025-04-24 A1120 MR Sensor
    Adds support for the Allegro Microsystems A1120 Hall Effect sensor in addition to the Honeywell 2SS52M Magneto-Resistive sensor. Documentation to follow.
2025-05-07 KiCad Documentation
    Updated documentation set with schematics and board layouts generated by KiCad (except for the MR Sensor).
2025-05-09 Cost Estimation Tool v1.6
    Cost estimation tool updated to support option of A110EUA-T Hall Effect sensors, and change supplier of 2SS52M MR device to RS (no longer stocked by Farnell).
    [Type 2 Cost Estimation Tool v1.5.xlsx, Type 2 Cost Estimation Tool v1.6.xlsx]
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2025-07-07 Firmware 3.8
    Added time delta between pulses to debug pulse timer output.
2025-07-09 A1120 Support
    Completion of A1120 Hall Effect sensor support. Add recommended attribution details to all guides.
2025-07-18 Add Magnet Positioning Guide
    Add printable guide to assist with aligning magnets and sensors.
2026-03-23 Update KiCad_Libraries.zip
    Add LRSP logo symbols with PCB silkscreen and copper footprint versions.
2026-10-09 Basic Serial Splitter update to KiCad 10.0.x
    Reorganised KiCad directory by major version. Updated Basic Serial Splitter KiCad project to KiCad 10.0.x, using new variants feature for Master & Expander boards. Added Creative Commons to silkscree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

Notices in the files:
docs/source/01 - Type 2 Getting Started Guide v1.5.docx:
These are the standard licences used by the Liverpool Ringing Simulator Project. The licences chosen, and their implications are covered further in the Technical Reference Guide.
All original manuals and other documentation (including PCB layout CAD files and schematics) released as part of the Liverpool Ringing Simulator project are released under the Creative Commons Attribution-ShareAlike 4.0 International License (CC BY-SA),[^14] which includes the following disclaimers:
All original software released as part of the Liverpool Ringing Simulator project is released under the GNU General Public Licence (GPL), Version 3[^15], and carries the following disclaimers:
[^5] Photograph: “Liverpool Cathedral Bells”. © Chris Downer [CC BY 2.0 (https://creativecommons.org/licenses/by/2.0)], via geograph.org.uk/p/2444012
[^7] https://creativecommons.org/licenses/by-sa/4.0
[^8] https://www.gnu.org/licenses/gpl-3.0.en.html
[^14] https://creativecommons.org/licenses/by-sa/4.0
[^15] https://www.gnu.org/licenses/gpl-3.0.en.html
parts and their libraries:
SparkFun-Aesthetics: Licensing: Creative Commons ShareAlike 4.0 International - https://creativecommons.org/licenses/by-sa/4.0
